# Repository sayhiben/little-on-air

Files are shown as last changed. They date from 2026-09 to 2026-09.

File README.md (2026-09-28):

# Little On Air

A wireless status sign for your desk, door or studio. Choose a mood on the desk
controller, press the knob, and the sign shows people whether you're available,
on air, waiting or asking for a little help.

The controller and sign communicate directly over Bluetooth. No phone app,
Wi-Fi network or account is needed. You choose the status yourself; Little On
Air does not automatically detect recording, calls or streaming software.

**This is the product manual.** For assembly, parts, source code, builds and
feature development, see the [developer guide](CONTRIBUTING.md).

## In this guide

- [Meet your devices](#meet-your-devices)
- [Quick start](#quick-start)
- [Choose a mood](#choose-a-mood)
- [Read the controller screen](#read-the-controller-screen)
- [Controls and settings](#controls-and-settings)
- [Connect or change a sign](#connect-or-change-a-sign)
- [Power and charging](#power-and-charging)
- [Understand the indicator lights](#understand-the-indicator-lights)
- [Troubleshooting](#troubleshooting)
- [Versions and further help](#versions-and-further-help)

## Meet your devices

Controller and sign diagrams showing the knob, OLED, mood light, sign face, reset button and power indicator.

The **desk controller** has a rotary knob that also presses like a button, a
small OLED screen and a round mood light beside the screen. Its rear USB-C port
provides power from your computer or a USB supply. It has no battery.

The **sign** has a lit front panel, a small rectangular **RESET** button and a
separate round red power indicator. The top has the **POWER** switch, a smaller
**RUN / PROGRAM** mode switch, a charger USB port and a separate XIAO USB port
for servicing. Two light guides at the rear expose the charger indicators.

The drawings are control maps, not assembly or dimensioned drawings. Locate the
two different sign USB ports before connecting a cable; they have different jobs.

## Quick start

For an assembled, commissioned pair:

1. With the sign's **POWER OFF** and both of its USB ports unplugged, select
   **RUN**. Turn **POWER ON**. Leave both sign USB ports unplugged during use.
2. Plug the controller into USB power. Keep the devices nearby for setup.
3. If already paired, the controller checks the sign and displays its mood.
   If it says **MEET YOUR SIGN**, tap the sign's **RESET** once, then press the
   controller knob to connect during the 60-second pairing window.
4. Turn the knob to choose a mood. **Press once to send it.** Wait for
   **YOUR SIGN** and the selected mood to appear as confirmed.

Turning alone is a preview: it does not change either device's mood light.
The sign remembers its last accepted mood through a normal power cycle.

## Choose a mood

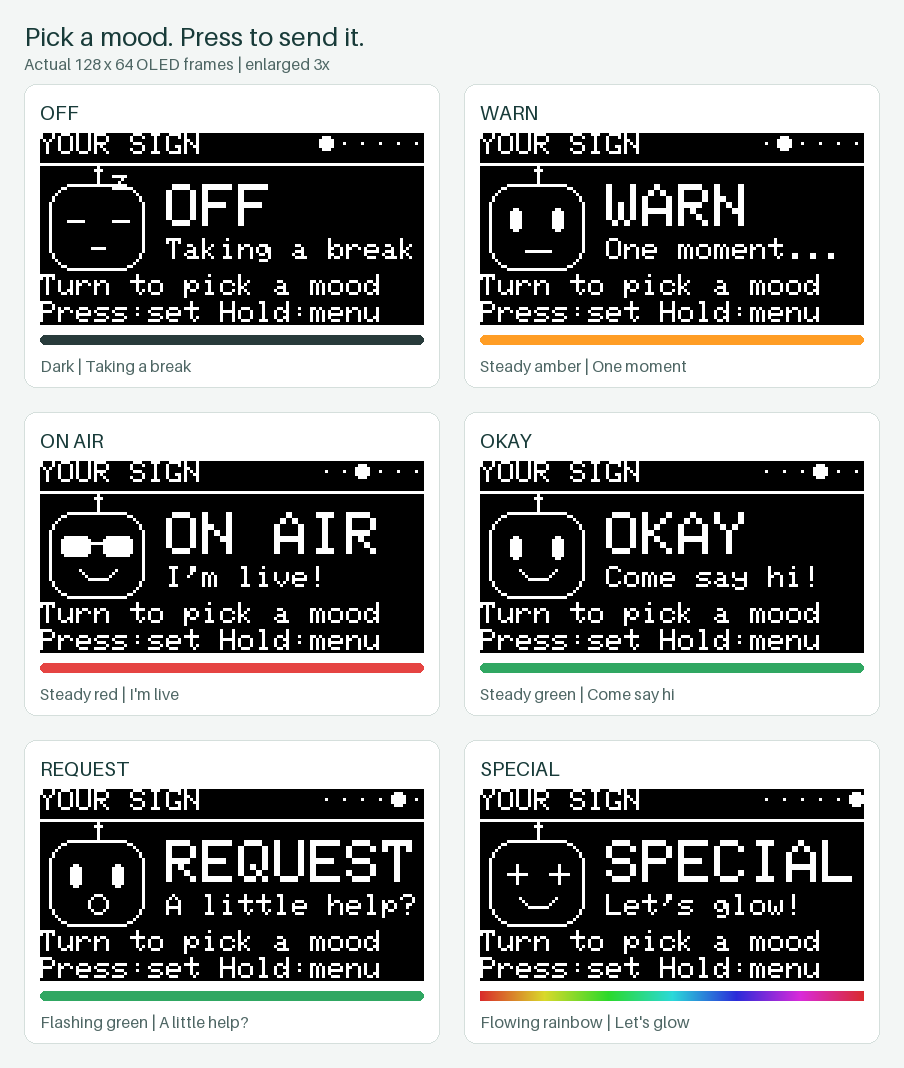
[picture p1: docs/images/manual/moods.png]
Six real controller screens: Off, Warn, On Air, Okay, Request and Special.


These screenshots use the controller's actual display code and font, enlarged
without smoothing. The color strips are a guide to the lights, not part of the
monochrome OLED. Colors on a monitor are approximate.

| Mood | Sign and controller mood light | Suggested meaning |
| --- | --- | --- |
| **Off** | Dark | Taking a break; no illuminated status |
| **Warn** | Steady warm amber | One moment; please wait |
| **On Air** | Steady red | I'm live; please avoid interruptions |
| **Okay** | Steady green | Come say hi; available |
| **Request** | Green flashing on for 0.6 seconds, off for 0.6 seconds | A little help, please |
| **Special** | A slow, flowing rainbow, repeating about every 20 seconds | Let's glow; a decorative or special status |

Agree on the meanings with the people around you. The colors are signals you
choose, not measurements of your activity.

Turning forward cycles **Off → Warn → On Air → Okay → Request → Special → Off**.
Turn the other way to go backward. Pressing a mood that is already confirmed
shows **Already set!** and leaves the sign alone.

The sign's four corner lights blend across its face. In Special, different
corners show different parts of the rainbow. The controller has one mood light;
its animation and the sign's animation do not have to move in exact step.

**Off turns off the mood lights, not the sign's power.** Its separate red power
indicator remains on while the sign is powered and paired.

## Read the controller screen

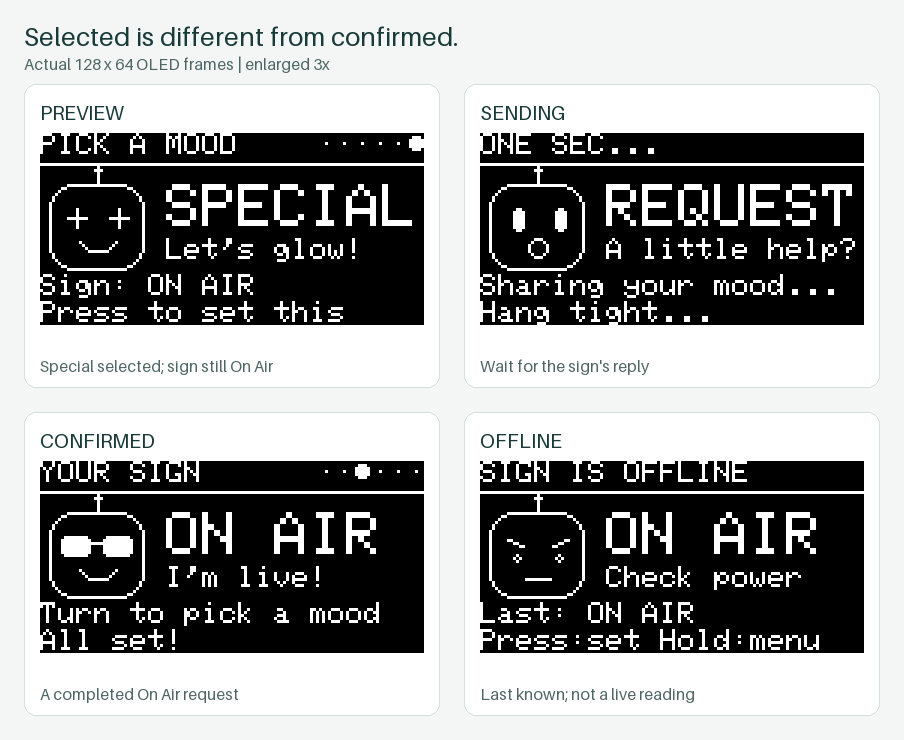
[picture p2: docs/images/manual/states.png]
Real controller screens showing a preview, a command in progress, confirmation and an offline last-known value.


The large word is the mood currently selected on the knob. Read the heading
and the smaller line to tell whether that mood has reached the sign. The six
dots at the top show the selected mood's position in the cycle; they are not
a battery gauge or signal-strength meter.

| Screen or message | What it means | What to do |
| --- | --- | --- |
| **YOUR SIGN** | The displayed mood has been checked with the sign | Turn to choose another mood, or leave it as it is |
| **PICK A MOOD** with **Sign: ON AIR**, for example | You are previewing a different mood; the smaller line is the confirmed sign state | Press to apply the large selection |
| **ONE SEC…**, **Sharing your mood…**, **Waiting for the sign** | A foreground operation is in progress | Wait for confirmation or an error |
| **All set!** | The sign confirmed the requested mood | No further action needed |
| **SIGN IS OFFLINE** with **Last: …** | The stored value has not been verified in the current connection state | Check sign power and distance; use **Check my sign** |
| **Last: not checked** | There is no confirmed saved value to show | Connect and check the sign |
| **MEET YOUR SIGN** | The controller has no paired sign | Open the sign's pairing window and press the knob |

A **Last:** value is a memory, not a live reading. When the controller cannot
verify the sign, its own mood light is dim white. It returns to the mood color
after a successful check. White is not a seventh mood.

The controller checks the sign on startup and periodically while on the home
screen. These background checks do not change the mood, restart the animations
or wake the OLED. After a connection failure it makes a few read-only retries.
If a send fails, it does not keep replaying that command later; check the screen
and press again when the sign is available.

## Controls and settings

### The knob

| Action | On the home screen | In settings |
| --- | --- | --- |
| **Turn** | Preview the next or previous mood | Move through choices |
| **Press and release** | Send the selected mood; connect if unpaired | Choose the highlighted item |
| **Hold for 1.2 seconds** | Open settings | Return to the home screen |

Holding and releasing does not also count as a click. The controller also
ignores a knob held down while it starts, so plugging it in with the knob
pressed does not send a mood or erase pairing.

### Settings menu

Hold the knob, turn to an item and press to select it.

| Item | What it does |
| --- | --- |
| **Back to my sign** | Return to the home screen |
| **Check my sign** | Read the sign's current mood without changing it |
| **Connect a sign** | Pair an unpaired controller with a sign in its pairing window; an already paired controller says **Already connected!** |
| **Brightness** | Adjust the sign frame, sign indicator, awake screen, dim screen and controller light; reset each to its default |
| **Light test** | Test the controller's small mood light; see below |
| **Forget this sign** | Ask for confirmation, then remove the pairing; see [changing or reconnecting a sign](#changing-or-reconnecting-a-sign) |

Settings and an unanswered Forget confirmation return home after 30 seconds
without input. You can also hold the knob to leave them.

### Brightness

Choose **Brightness**, then the light or screen mode you want to adjust. Press
**Level**, turn to change it in 5-point steps, and press again. Choose **Save**
to keep it. **Reset default** selects that item's original brightness; choose
**Save** to keep the reset. **Cancel**, holding the knob, or leaving the editor
idle discards an unsaved change.

Every level uses a **0–100% adjustment scale**: 0% is the lowest available
brightness, not off. The ranges are limited for each light. The default is 50%
for the three LED controls, 100% for **Screen awake**, and 0% for **Screen dim**.
These defaults reproduce the previous firmware's light levels. Awake and dim
are adjustable separately; dim stays below the awake range. Screen sleep still
turns the display off after two minutes.

The controller previews its own light and screen while editing, including the
idle contrast when editing **Screen dim**. Its light continues showing the
current mood, so choose a lit mood first if it is Off. The sign applies a change
when you save. Its mood and animation continue without restarting.

The sign must be reachable to read or save its brightness. Wait for
**Brightness saved**. **Save not confirmed** means the result is uncertain;
press to read the sign again before making another change. Unsaved or failed
requests are never sent automatically later. **Update sign firmware** means the
sign needs the matching brightness-capable firmware.

Each device saves its own brightness through power cycles and disconnects.
Changing or forgetting a pairing preserves these settings, so a replacement
controller reads the sign's own levels. Controller settings also work without a
paired sign.

### Light test

**Light test** affects only the controller's round light. It does not change the
sign or its saved mood. The screen says **LIGHT CHECK** and shows the test color
and counts of turns and clicks.

The test starts red. Turn or click to cycle through **Off, Red, Green, Blue,
White and Yellow**. Hold to finish, or let it exit after 60 seconds without
input. The controller then resumes its usual confirmed-mood or offline light.

### Screen sleep

The OLED dims after 30 seconds without activity and turns off after two minutes.
The first turn, click or hold while it is asleep **only wakes it**. Make the
gesture again to select, send or open settings. The mood light continues to work
while the screen sleeps.

If your computer removes USB power during sleep, the controller turns off.
The battery-powered sign keeps its saved mood. When USB power returns, the
controller reads the sign; startup does not advance or send a new mood.

## Connect or change a sign

### First connection

1. Power the sign in **RUN** on its battery, with both sign USB ports unplugged.
2. Tap the unpaired sign's **RESET** once. Its red indicator blinks quickly for
   the **60-second pairing window**.
3. Press the unpaired controller's knob, or choose **Connect a sign**. Keep the
   devices nearby and allow the search to finish; it can take several seconds.
4. Look for **YOUR SIGN** and a confirmed mood. The sign's red power light becomes
   steady after it is paired.

There is no PIN to type. Each controller/sign pairing is for one partner.
If the pairing window expires, tap RESET once to open it again on an unpaired
sign. Ordinary power cycles keep an existing pairing.

### Changing or reconnecting a sign

Keep the old sign powered and nearby. Hold the controller knob and choose
**Forget this sign**. The confirmation starts on **Keep my sign**; turn to
**Forget sign** and press to proceed. Hold to cancel instead.

With matching current firmware and a reachable sign, this unlinks both devices.
The sign restarts, clears its saved mood to Off and opens its pairing window.
When the controller says **Ready to connect!**, press to pair again, or open the
pairing window on the replacement sign you want to use. Only put the intended
sign into pairing mode nearby.

If the old sign cannot be reached, the controller still forgets its own pairing
and displays the recovery instructions below. The old sign retains its keys
until you reset its pairing locally.

### Five-reset recovery

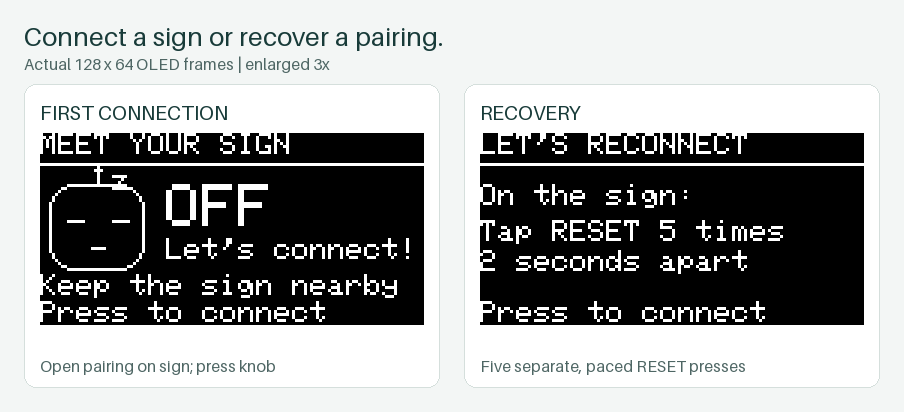
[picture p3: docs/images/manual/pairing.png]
Actual first-connection and recovery screens. The recovery screen says to tap the sign's RESET five times, two seconds apart.


Use this if a sign still remembers an old controller, online Forget could not
reach it, or the devices have mismatched pairing records.

1. If the controller still has an old pairing, use **Forget this sign** first.
2. With the sign powered in RUN, press and release its **RESET five times**, about
   **two seconds apart**. Let the application start between presses.
3. After the fifth reset, the sign forgets its pairing and saved mood, returns
   to Off and opens a 60-second pairing window.
4. Press the unpaired controller's knob to connect.

This is five separate presses, not a long hold. A gap of six seconds of normal
running clears an incomplete count; if you lose count, wait and start again.
A power cycle also clears an incomplete count. Avoid a rapid double tap: that
enters the firmware bootloader instead. If you accidentally do that, a normal
power cycle returns to the application when valid firmware is installed.

## Power and charging

**Before connecting either USB port on the sign: set POWER OFF and select
PROGRAM. Connect only one sign USB port at a time.** The sign does not have an
automatic USB/battery power selector. Do not charge it while using it in RUN.

Power mode guide: normal use is ON and RUN with no sign USB cable; charging is OFF and PROGRAM with charger USB only; servicing is OFF and PROGRAM with XIAO USB only.

| Activity | POWER | MODE | Sign USB connection |
| --- | --- | --- | --- |
| Normal use | **ON** | **RUN** | Neither port |
| Turn the sign off | **OFF** | RUN | Neither port |
| Charge the battery | **OFF** | **PROGRAM** | **Charger USB only** |
| Firmware service | **OFF** | **PROGRAM** | **XIAO USB only**; see the developer guide |

To charge:

1. Turn POWER OFF. With both USB cables removed, move MODE to PROGRAM.
2. Connect power to the **charger USB port**. Leave XIAO USB unplugged.
3. The rear light guides show the charger's indicators. Their meaning depends
   on the fitted charger board; use its verified labels. The OLED does not show
   battery percentage or a charging estimate.
4. After charging, unplug USB first. With POWER still OFF, select RUN, then turn
   POWER ON to use the sign.

Only change MODE with POWER OFF and both USB ports unplugged. PROGRAM provides
electrical isolation; selecting it does not itself start a firmware update.
POWER OFF disconnects the normal load but does not disconnect the battery from
the charging board.

The controller's USB port is separate from these restrictions: it normally stays
plugged in during use. Do not open a powered sign or charge a damaged battery;
have wiring, a loose connector or battery replacement checked using the
[assembly and commissioning guidance](CONTRIBUTING.md#hardware-and-bill-of-materials).

## Understand the indicator lights

There are three different kinds of light:

| Light | Appearance | Meaning |
| --- | --- | --- |
| Sign's large front panel | One of the six moods | The sign's saved, active mood |
| Controller's round light | Mood color or animation | The mood confirmed by the sign, not the knob preview |
| Controller's round light | Dim steady white | The sign's state is currently unverified |
| Sign's small front power indicator | Steady red | Powered and paired; stays red even when the mood is Off |
| Sign's small front power indicator | Fast red blink, about twice per second | Unpaired; pairing window is open |
| Sign's small front power indicator | Mostly red with a short dark gap every two seconds | Unpaired; pairing window has closed |
| Rear charger light guides | Charger-board indicators | Charging status, separate from Bluetooth and mood |

The little face on the OLED is decorative and sometimes blinks. Use the screen
heading and text to judge connection state.

## Troubleshooting

| Symptom | Try this |
| --- | --- |
| Turning the knob does not change the sign | Press to send the preview. If the screen was asleep, the first gesture only woke it. |
| Screen is dark | Press once to wake it. If it stays dark, check controller USB power and the cable. |
| **SIGN IS OFFLINE** or **Can't reach your sign** | Check sign battery/power and RUN mode, move closer, then use **Check my sign**. A Last value is not confirmation. |
| Controller light is white | It is waiting for a verified sign state. Check power and use **Check my sign**. |
| Controller is on but sign is dark | Off is a valid mood. Check the sign's separate red indicator, then send Okay or On Air. If the indicator is also off, check power and charge the battery using the sequence above. |
| The sign stays red after choosing Off | The small power indicator should stay red. The large front mood panel should be dark. |
| Pairing does not finish | Open the sign's 60-second window again and keep it nearby. If either device remembers a different partner, use Forget and the five-reset recovery steps. |
| **Already connected!** when choosing Connect | Connect does not replace a partner. Use **Forget this sign** before changing signs. |
| **One sec, please!** | Let the current operation finish before starting another. |
| **Press to try again** after a failed operation | Restore connectivity, then press again. A failed request is not silently sent later. |
| Mood animation resumes when the controller is unplugged | Expected: the sign runs independently and retains its mood. |
| Reset seems to enter an update mode | Avoid rapid double taps. Power-cycle normally, then space pairing-reset presses about two seconds apart. |
| **State save failed**, **Cache clear failed**, or repeated **Radio needs a restart** | Restart the controller and check again. If it recurs, record the exact message and firmware versions for service; do not repeatedly erase pairing as a substitute for diagnosis. |
| Front panel flickers, shows the wrong color or only some corners light | Check with another steady mood. If it persists, stop and have the pixel wiring and matching receiver firmware checked; Light test only tests the controller light. |

## Versions and further help

This manual describes the **ESP32-S3 controller firmware 0.5.0** with the current
matching four-pixel nRF52840 receiver firmware, **Igor measured v4 controller**
and **v2.15 sign case** with open-backed frame wire channels. This project
maintains this one device pair; install the current controller and receiver
firmware together when updating.

Manufacturing ZIPs preserve the firmware that shipped with their design snapshot;
that may be older than this manual. Use the [developer firmware guide](CONTRIBUTING.md#build-and-flash)
when updating a device, and follow the sign's USB isolation sequence above.

- [Developer guide](CONTRIBUTING.md): BOM, wiring, architecture, setup, builds,
  tests, diagnostics and making changes.
- [Current hardware](hardware/README.md): assembly guides and print files.
- [Brightness hardware checks](docs/BRIGHTNESS_BENCH.md) and
  [pairing/power observations](docs/PAIRING_POWER_UPDATE.md): what has actually
  been checked on the assembled devices.
- [Report a problem](https://github.com/sayhiben/little-on-air/issues): include
  the screen message, selected mood, power arrangement and installed versions.

## License

[MIT](LICENSE). Hardware source attribution is recorded with each design.

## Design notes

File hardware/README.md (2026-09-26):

# Hardware

| Design | Current source and guides | Ready-to-use release |
| --- | --- | --- |
| Receiver enclosure v2.15 | [Enclosure development](enclosure/README.md) | [Complete manufacturing release](../release/little-on-air-enclosure-v2.15/README.md) |
| Igor controller v4 | [Measured controller](controller/igor-measured-v4/README.md) | [Controller ZIP](../release/little-on-air-igor-controller-v4.zip) |

Earlier designs, exploratory scripts and superseded manufacturing output are
grouped in [archive/](archive/README.md). See the [workspace guide](../docs/WORKSPACE.md)
for local firmware images, build output and bench evidence.

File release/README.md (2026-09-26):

# Current project release

## Controller hardware prototype

The [measured Igor controller v4 ZIP](little-on-air-igor-controller-v4.zip)
uses Igor's actual desk orientation: broad flat base down, horizontal encoder,
upward-facing display and vertical back. A 9.5 mm base extension fits two
20 × 33.5 × 6.5 mm weights in one layer beneath a XIAO ESP32-S3 carrier.
The encoder and OLED mounts match supplied measurements; the front mini-strip
NeoPixel has a captured transparent PETG diffuser. The footprint is unchanged,
and the raised front nose contains no weights. Includes eight STLs, STEP CAD,
three Bambu projects, fit report, comparison views and assembly instructions.
Read the [controller guide](../hardware/controller/igor-measured-v4/README.md).

CAD and slicer checks pass; physical assembly and the ESP32-S3 firmware port
remain unvalidated/unimplemented. Controller v1–v3 are superseded.

## Receiver enclosure

The current manufacturing release is [Little ON AIR enclosure v2.15](little-on-air-enclosure-v2.15/README.md), the case retained by the user and restored as current on September 26, 2026. Frame 01 has open-backed perimeter wire channels; the channel roofs and access-window ceilings were removed after the v2.14 physical bridging failure. The original rear housing 05, electronics yoke 06 and other printed/laser-cut parts remain in this set.

- [Download the complete ZIP](little-on-air-enclosure-v2.15.zip)
- [Print only the replacement front frame](little-on-air-enclosure-v2.15/bambu-studio/on-air-v215-X1C-front-only.3mf)
- [Open the three-plate Bambu Studio project](little-on-air-enclosure-v2.15/bambu-studio/on-air-v215-X1C-all-plates.3mf)
- [Read the open-channel wiring guide](little-on-air-enclosure-v2.15/guides/FRONT-WIRING.md)
- [Read the complete build guide](little-on-air-enclosure-v2.15/guides/BUILD-AND-ASSEMBLY.md)
- [Review all parts and materials](little-on-air-enclosure-v2.15/BOM.csv)

The release includes production STLs, acrylic artwork, calibration SVGs, Fusion/STEP CAD, assembly and wiring guides, validation records and a firmware source snapshot. Optional laminate parts are kept separate from the selected printed backing. Older development iterations are in [the hardware archive](../hardware/archive/README.md); see the [revision history](../hardware/enclosure/REVISION-HISTORY.md).

The [v2.16 release](little-on-air-enclosure-v2.16/README.md) is preserved as an archived alternative. Both releases, their ZIPs and checksums retain their published bytes. The current case is v2.15; its bundled firmware snapshot is independently versioned v0.1.2 and drives onboard RGB only. Use the [developer guide](../CONTRIBUTING.md#four-pixel-nrf52840-receiver) for current receiver firmware. This case selection adds no new physical validation result; the original validation records and commissioning checks remain in the package.

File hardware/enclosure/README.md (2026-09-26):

# Little On Air enclosure

## Current complete release

Use [enclosure v2.15](../../release/little-on-air-enclosure-v2.15/README.md), the receiver case retained by the user and restored as current on September 26, 2026. It has the open-backed wire channels in frame 01 and the original rear housing 05 and electronics yoke 06.

- [Complete release ZIP](../../release/little-on-air-enclosure-v2.15.zip)
- [Bambu Studio: replacement front frame](../../release/little-on-air-enclosure-v2.15/bambu-studio/on-air-v215-X1C-front-only.3mf)
- [Bambu Studio: all plates](../../release/little-on-air-enclosure-v2.15/bambu-studio/on-air-v215-X1C-all-plates.3mf)
- [Open-channel wiring and mounting](../../release/little-on-air-enclosure-v2.15/guides/FRONT-WIRING.md)
- [Build and assembly](../../release/little-on-air-enclosure-v2.15/guides/BUILD-AND-ASSEMBLY.md)
- [Parts and hardware](../../release/little-on-air-enclosure-v2.15/BOM.csv)

The current set uses black PLA+ structure, black/white PLA+ backing and three clear PETG indicator guides. v2.15 removes the failed wire-channel roofs from the widened 129 × 69 mm frame. Wires lay into the channels from the rear and use small hot-glue anchors for retention. The other parts, acrylic, optical floors and nine M3x8 joints retain their earlier geometry. The all-plates project preserves the approved three-plate layout; the front-only project is for upgrading a v2.14 frame.

The existing CAD, print projects, validation records and published checksums are unchanged. This selection records which case the user kept; it does not add a new physical fit or electrical validation result. The v2.16 rearward-wiring housing/yoke revision is preserved in [the archive](../archive/enclosure/v216/README.md).

The package preserves the earlier firmware 0.1.2 snapshot, which uses onboard RGB only. Follow the [developer guide](../../CONTRIBUTING.md#four-pixel-nrf52840-receiver) for the current four-pixel firmware; release-bundled firmware notes describe the historical snapshot.

## Development files

[v215/](v215/README.md) contains the current channel-opening builder, mesh and
print audits, wiring diagram and release tooling. `output/v215/` contains its
preserved CAD, frame mesh, print projects and validation evidence. Packaging
starts from the preserved v2.14 release and replaces frame 01 and its guides.

Earlier versions, one-time patch/probe scripts, old root-level builders,
references and superseded outputs now live in
[the hardware archive](../archive/README.md). Current tools explicitly import
several archived geometry and print-audit helpers; retain that dependency tree.
[REVISION-HISTORY.md](REVISION-HISTORY.md) links to the archived manufacturing
iterations. Published release bundles keep their existing paths and checksums.

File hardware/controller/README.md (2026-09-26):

# Controller hardware

Use [Igor measured v4](igor-measured-v4/README.md) for the current controller.
Its directory contains the source, measured component references, assembly
instructions, validation reports and Bambu Studio projects.

Versions 1–3 are preserved under [the controller archive](../archive/README.md#controller).
The [ESP32-S3 firmware](../../apps/controller-esp32s3/README.md) is maintained
separately from the mechanical design.

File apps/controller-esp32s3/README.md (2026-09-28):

# ESP32-S3 desk controller

USB-powered Seeed XIAO ESP32-S3 controller for the existing Little On Air BLE
receiver. This application uses Arduino-ESP32 with pinned PlatformIO packages.
The nRF52840 controller in `../controller` and receiver in `../receiver` remain
separate Zephyr applications; their UF2 files cannot be flashed to this board.

## Wiring

| Part | XIAO label | ESP32 GPIO |
| --- | --- | --- |
| SSD1306 128×64 OLED SDA | D4 | 5 |
| OLED SCL | D5 | 6 |
| Encoder CLK | D0 | 1 |
| Encoder DT | D1 | 2 |
| Encoder SW | D3 | 4 |
| One RGB NeoPixel DIN, through 330 Ω | D7 | 44 |

OLED and encoder VCC use 3V3. NeoPixel power uses 5V. All grounds are common.
Pixel DOUT is unused. USB diagnostics use the native USB peripheral, leaving
GPIO44 available for the pixel. OLED address 0x3C or 0x3D is detected at boot.
The pixel uses GRB, 800 kHz and a default brightness limit of 24/255.

## Controls

- **Turn:** preview Off → Warn → On Air → Okay → Request → Special; turn backward
  to go the other way. Turning does not change the sign.
- **Press:** set the selected mood. When unpaired, start connecting to a sign.
- **Hold 1.2 seconds:** open the menu; hold again to return home.
- **Menu:** Back to my sign, Check my sign, Connect a sign, Brightness, Light test, Forget this sign.
- **Brightness:** separate sign frame/indicator, awake/dim OLED and controller-light
  controls. Press Level, turn, press again and Save. Reset default prepares a reset
  for that value; Save commits it. Local edits preview immediately; sign edits apply
  on Save with exact transaction/levels read-back. Cancel/hold/timeout discards drafts.
  Each device retains its own levels independently of pairing. See the
  [brightness guide](../../docs/BRIGHTNESS.md) for ranges, protocol and validation.
- **Forget this sign:** defaults to Keep my sign. Turn to Forget sign and press to erase.
  Keep the sign powered: firmware 0.4.0 clears both devices' pairing, then a
  press connects them again. If the sign cannot be reached, the OLED shows
  the five-reset recovery instructions below.
  Holding the knob during boot never clears a bond or sends a command.

The OLED buddy has a different expression for each mood: sleepy when Off,
sunglasses when On Air, and starry eyes for Special. Large text shows the
selection; **PICK A MOOD** and **Sign: ...** distinguish a preview from the
confirmed state. **SIGN IS OFFLINE** and **Last: ...** identify cached state that
has not been verified. A write response alone is not treated as confirmation.

The controller pixel stays at the confirmed state while you browse: red = On Air,
warm amber = Warn, steady green = Okay, flashing green = Request, a slowly changing
rainbow = Special, dark = Off. Unknown/offline uses a steady dim white marker.
Request flashes 600 ms on / 600 ms off. Special flows through a 20-second cycle;
the receiver's four corner pixels form a diagonal rainbow wash. Both devices
animate locally, so their phases need not match exactly.

The display dims after 30 seconds and turns off after two minutes without user
interaction. The first gesture wakes it without changing or sending a state.
The pixel continues displaying the status. Menus cancel after 30 seconds idle;
Hardware Test exits after 60 seconds idle. Background state reads do not reset
the display's inactivity timer.

**Hardware Test** labels the OLED with the commanded pixel color and input
counters. Turn or press to cycle Off / Red / Green / Blue / White / Yellow.
Hold to exit. This mode neither sends nor persists a receiver state.

## Build, flash, and inspect

From the repository root, with Python 3.10+:

```sh
python -m pip install platformio==6.1.18
python -m platformio run -d apps/controller-esp32s3
python -m platformio device list
python -m platformio run -d apps/controller-esp32s3 -t upload --upload-port COM4
python tools/controller_serial.py --port COM4 --command status
python tools/controller_serial.py --port COM4 --command "test red" --duration 30
python tools/controller_serial.py --port COM4 --command exit
```

Replace COM4 with the detected port. On this Windows workspace the Python
environment is `.venv\Scripts\python.exe`. The uploader writes and verifies the
bootloader, partition table and app; it does not erase the NVS bond/state area.
If USB upload cannot connect, hold BOOT, tap RESET, release BOOT and retry.

USB commands: `help`, `status`, `test`, `test red` (also off/green/blue/white/yellow),
`next`, `exit`, `menu`, `sync`, `pair`, `send off|warn|on-air|okay|request|special`.
`send` uses the same real BLE transaction and exact acknowledgment checks as
pressing the encoder; it rejects unpaired/busy requests and unknown states.
`pair` explicitly opens the same timed
pairing operation as the menu. Input events and BLE results are logged at 115200.
Firmware 0.2.3 adds `pixel 1 red` (indices 1–4 and the six hardware-test colors)
and `pixel end` for receivers with the individual-pixel characteristic. These
temporary front-light tests use encrypted write/read-back without changing the
saved receiver status; they end after two minutes or a regular status command.
Opening the provided monitor leaves reset control lines deasserted.
No USB command erases bonds or pretends to acknowledge a receiver command.

The full build outputs are under `.pio/build/xiao_esp32s3/`. `firmware.bin` alone
is the application at offset 0x10000; use PlatformIO to flash all required images.
Change `LOA_ENCODER_DIRECTION` to -1 if the physical encoder direction is reversed.

## Pairing with the nRF52840 receiver

1. Power the receiver. If it still has an old controller bond, clear that bond
   first using the five-reset procedure below.
2. On an unpaired receiver, one reset opens its 60-second pairing window.
3. On an unpaired controller, press to connect; otherwise hold the encoder,
   select **Connect a sign**, and press.
4. The controller scans for up to 45 seconds inside a 60-second operation budget,
   establishes an encrypted Secure Connections bond, and reads the receiver state.
5. Confirm the OLED shows **YOUR SIGN**, then turn and press to set a mood.

Only the stored bonded identity is contacted during ordinary sync/send. A missing
peer key reports a failure instead of silently forgetting/replacing the bond.
To replace the receiver, explicitly Forget this sign on the controller and clear the
receiver's old bond before pairing again.

### Reconnecting after Forget this sign

With controller **0.4.0** and the matching receiver update, keep the sign on,
choose **Forget this sign → Forget sign**, wait for **Ready to connect**, then
press the knob. The sign erases its bond and saved mood, restarts in Off, and
opens a 60-second pairing window. Its small onboard LED flashes red while
pairing and stays red after connecting. The front pixels show only the mood.

If the sign was off, out of range, or running older firmware, Forget still clears
the controller's pairing and displays **LET'S RECONNECT**. On the updated sign:

1. Leave the sign powered and press its rectangular RESET button **five times,
   about two seconds apart**. Let the application LED return between presses.
   Do not double-click: rapid double-reset enters the firmware bootloader.
2. After the fifth press, the sign clears its pairing and mood and flashes red.
3. Press the controller knob to connect within 60 seconds. If that window has
   expired, tap the sign's RESET once and press the knob again.

Six seconds of uninterrupted application runtime cancels an incomplete reset
sequence; power cycling also cancels it. Holding RESET does not run a timed
gesture because it holds the processor in reset. Ordinary power cycling and
application-only firmware updates preserve the bond.

If the controller still holds an old bond after physically resetting the sign,
choose **Forget this sign** there before pressing to connect. Recovery needs no
computer or special firmware. See [the pairing/power update](../../docs/PAIRING_POWER_UPDATE.md)
for the recorded hardware validation. Use the
[current build and service guide](../../CONTRIBUTING.md#build-and-flash) for
this device pair; earlier firmware versions are not maintained.

## Current behavior

The shared C protocol/status implementations are built directly from the root
`src/` directory. UUIDs and the six-byte version-1 payload are unchanged. The
receiver remains the authority: subscribe to indications, write with response,
then require an exact transaction-ID **and** status match. A lost indication can
be recovered by an exact matching read. Failure marks the cached state unverified
and schedules read-only reconciliation with 1/2/4-second backoff; it never replays
the user's command. After three failed retries, manual Sync/press is required.
Successful operation resumes a read once per minute.
These background checks do not show connection messages, wake the OLED, restart
animations, or flash the bonded receiver's lights. A press during a background
check queues that selection until the read succeeds; failures never replay it.

Firmware `esp32s3-0.3.0` appends Request (wire value 4) and Special (5), preserving
values 0–3. Update the receiver before selecting either new mood. Old firmware
rejects the new values. Return to Off before rolling either device back.

BLE runs on a worker task, with an eight-second ordinary-operation budget; the
UI stops scans/connections at the deadline while continuing to read controls.
Connections close after each transaction to preserve receiver battery life.
Firmware `esp32s3-0.2.2` retries one BLE connection-establishment (`0x3e`)
failure before any command is sent, within the same eight-second deadline.
NimBLE persists bonds; Preferences stores only acknowledged/read-back state.
The pinned NimBLE 2.5.1 host is compiled through `nimble_guard.py`, which disables
its automatic missing-key pairing branch before GAP notification. The GAP
listener then translates that error to authentication failure. Normal operations
require a saved encryption key and make one encryption attempt. The storage
callback replaces only the same peer's obsolete private-address mapping when
that cache fills; it never evicts pairing keys to make room. Explicit Forget
clears residual key records as well as the listed bond.
Legacy BLE pairing is compiled out. Just Works has no passkey MITM protection,
as in the original receiver firmware.

## Tests

Host tests use CMake, a C/C++ compiler, and CTest (Linux/macOS or WSL):

```sh
cmake -S tests/host -B build/desk-tests
cmake --build build/desk-tests
ctest --test-dir build/desk-tests --output-on-failure
```

They cover contact bounce/reversal/invalid encoder transitions, button debounce,
boot-held suppression, hold/release behavior, clock wrap, shared wire encoding,
malformed packets, exact ACK matching, cached-state trust, and preview preservation.
They also cover all six wire values, Request boundaries, Special's period and
bounded brightness, and background checks while the OLED is asleep. Reset tests
run the actual settings-backed counter and durable remote-reset request with
simulated pin/power/software resets, flash failures, and timeout work. Output
tests check that all six moods and individual pixel tests leave the onboard
power LED independent, with separate brightness limits. A thousand simulated
private-address rotations exercise the real storage callback without deleting
keys; the pinned-host patch refuses unrecognized source changes. After a
PlatformIO build, `python tools/render_buddy_ui.py` (g++ and Pillow required)
renders the actual Adafruit GFX home-screen code and checks text bounds.

See [the six-mood update](../../docs/BUDDY_UPDATE.md) for the receiver build,
blink diagnosis, and validation status.

See [the initial bench results](../../docs/ESP32S3_BENCH.md) for controller hardware
observations and [the pairing/power update](../../docs/PAIRING_POWER_UPDATE.md) for current
paired hardware checks.

Reference: [Seeed pin multiplexing](https://wiki.seeedstudio.com/xiao_esp32s3_pin_multiplexing/),
[PlatformIO XIAO ESP32-S3 target](https://docs.platformio.org/en/latest/boards/espressif32/seeed_xiao_esp32s3.html),
[NimBLE-Arduino](https://github.com/h2zero/NimBLE-Arduino/tree/2.5.1).

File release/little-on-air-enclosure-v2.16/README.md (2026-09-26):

# Little ON AIR enclosure v2.16

This is the complete manufacturing package for the **129 × 69 mm front / 120 × 60 × 24 mm rear body** enclosure with the broad front bevels, corrected frame seams, two switches, flat PCB mounts, front reset button and captive indicator light guides. The unpressed reset button projects approximately 2.5 mm beyond the front.

**Upgrading an existing build:** print [05 rear housing and 06 electronics yoke](bambu-studio/on-air-v216-X1C-upgrade-parts.3mf), then follow [the illustrated rearward wiring guide](guides/FRONT-WIRING.md). The existing v2.15 front frame, all other printed parts and the acrylic are unchanged. Open clearances in the housing and reinforced yoke let the LED leads turn rearward behind the optical mounts instead of around the outside corners. Lay the upper wires before clamping the yoke. No new parts or electrical components are needed.

## Start here

1. Check the [parts and hardware list](BOM.csv).
2. Open the [single Bambu Studio project](bambu-studio/on-air-v216-X1C-all-plates.3mf) **as a project**, keeping its settings. It contains all ten production prints on three plates. [Printing guide](guides/PRINTING.md).
3. Cut and rear-engrave the acrylic using the [production SVG](laser/02-acrylic-REAR-engrave-and-cut.svg) and [laser guide](guides/LASER.md). The artwork is already mirrored; do not mirror again.
4. Follow the [complete build guide](guides/BUILD-AND-ASSEMBLY.md) and [two-switch wiring guide](guides/WIRING.md). The [capacitor and resistor walkthrough](guides/CAPACITOR-AND-RESISTOR.md) shows their purpose, exact lead connections and soldering steps. Record the physical checks in [COMMISSIONING.csv](guides/COMMISSIONING.csv).

**Firmware status:** the included firmware source snapshot is version 0.1.2 and drives the onboard RGB LEDs. It does not yet drive the four external NeoPixels. This hardware revision preserves that earlier snapshot; it does not publish or assess newer firmware work in the development repository. See [firmware status](guides/FIRMWARE-STATUS.md).

## Print set

| Plate | Parts | Material |
| --- | --- | --- |
| 1 | 01 frame, 05 housing, 04 optical retainer, 06 electronics yoke, 07 reset button, 11 rear guide keeper | Black PLA+ |
| 2 | 03 display backing, black base and white raised letters | Black and white PLA+ |
| 3 | 08 front indicator guide and **two** identical 09 charger guides | Transparent PETG |

The project keeps the approved three-plate positions from v2.15. Only the housing and yoke meshes change. There is one keeper; insert painting and the material profiles are preserved. Project filament numbers are **1 black PLA+, 2 white PLA+, 3 transparent PETG**; map them to your loaded spools. First-layer inspection remains disabled. Estimated total is about **6 h 37 min / 75.81 g**.

There are nine unique production STL files and ten printed pieces. Part 02 is laser-cut acrylic. Part 10 in the CAD is the second instance of STL 09; there is no missing STL. The printed display backing sits behind the acrylic with an air gap; its letters do not insert into engraved recesses.

## Folder guide

| Folder / file | Contents |
| --- | --- |
| `stl/` | Latest production meshes, millimetres, already oriented for printing |
| `bambu-studio/` | Complete three-plate project plus a housing-and-yoke upgrade project; both editable and sliced |
| `laser/` | Production acrylic SVG and clearly disabled LightBurn review project |
| `laser/calibration/` | Thickness-fit strip, kerf coupon and engraving samples |
| `cad/` | Complete current Fusion F3D and STEP assembly; hardware/reference bodies are not extra print parts |
| `guides/` | Consolidated printing, laser, wiring, assembly, firmware and commissioning instructions |
| `reference/` | Wire paths, length allowances, fastener layout and assembly images |
| `alternatives/laminate/` | Optional laminate artwork and its two spacer rings; omit with the selected printed backing |
| `firmware/` | Preserved firmware v0.1.2 source snapshot; no unverified local build binaries |
| `validation/` | Current mesh/print/optics checks and the existing native CAD validation records |
| `PARTS.csv` | Exact quantities, file paths, materials and revision provenance |
| `MANIFEST.json`, `SHA256SUMS.txt` | File inventory, source provenance and integrity checks |

The main case, yoke, optical retainer and guide keeper use **nine M3×8 button-head screws and nine standard M3 nuts total**. No older long closure screws, printed DPDT plunger or alternate-size guide sets are required.

The manufacture package has been checked digitally; actual spool behavior, acrylic thickness/kerf, electrical operation and optical brightness still require the build checks. No printer, laser or firmware job was started while packaging this release.

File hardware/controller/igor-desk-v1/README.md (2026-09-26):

# Little On Air — Igor desk controller v1

**Superseded by [revision 3](../igor-flat-base-v3/README.md):** this revision used an incorrect desk orientation. Use revision 3 for the flat base, horizontal encoder and front NeoPixel.

**Superseded:** use the [minimal Igor revision 2](../igor-minimal-v2/README.md), which preserves the original shape and adds only a small base extension, XIAO holder and top LED spot.

A **USB-powered XIAO ESP32-S3 controller** with an OLED, a rotary push encoder,
one WS2812B RGB LED, and a weighted case. This is a direct modification of
[Project IGOR by UrbanCircles / Peter](https://www.printables.com/model/1019283-project-igor-open-source-offline-loyal-cheerful-fo),
using the creator's STEP geometry from [UrbanCircles/igor](https://github.com/UrbanCircles/igor).

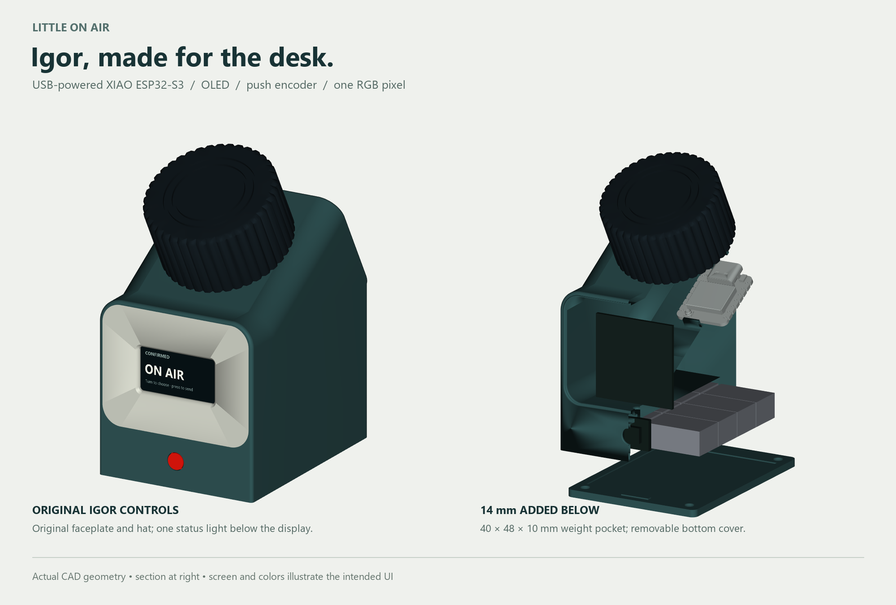
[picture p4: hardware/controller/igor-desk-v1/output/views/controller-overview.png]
Controller and section


## What changed

- **Computer USB-C supplies all power.** Use the regular XIAO ESP32-S3, without
  the Sense expansion board. No controller battery or external charger.
- Igor's **original OLED faceplate and encoder hat are retained at 100% size**.
  The assembled hat has a nominal 0.6 mm clearance above the shell.
- The original sloping underside is extended downward to a **flat desk base**.
  It adds **14 mm below the original front floor** and fills the space beneath
  the original rear slope. The upper silhouette and encoder mount remain Igor's.
- A **40 × 48 × 10 mm** underside compartment accepts adhesive wheel weights.
  The example arrangement is sixteen 5 g segments, **80 g total**, in two layers.
  Each segment must be **at most 19 × 11.5 × 4 mm, including adhesive**.
- A separate front slot holds a **10 × 10 × 1.6 mm single-pixel PCB**, behind a
  captive diffuser. The removable bottom cover retains the pixel PCB and weights.
- The D1 mini ridge is removed. A new XIAO pedestal, forward stop and enlarged
  rear USB opening fit the **actual Seeed XIAO ESP32-S3 CAD model**. Thin mounting
  tape holds the board down; the stop takes the forward insertion load.

Overall assembled envelope, excluding cable and rubber feet: approximately
**49 × 67.3 × 90.2 mm** (width × depth × height, including the hat).
Fit four approximately Ø8 × 1.2 mm rubber feet to the bottom cover for grip.

## Files to use

| File / folder | Purpose |
| --- | --- |
| [output/stl](output/stl) | Five individual parts, already oriented for printing, in millimetres |
| [output/bambu-studio](output/bambu-studio) | Three Bambu X1C / 0.4 mm projects, separated by material/color |
| [Complete STEP assembly](output/cad/igor-desk-v1.step) | Editable solid assembly; individual STEP parts are alongside it |
| [BOM.csv](BOM.csv) | Electronics, fasteners, weights and consumables |
| [ASSEMBLY.md](ASSEMBLY.md) | Printing, component fit, wiring routes and assembly |
| [WIRING.md](WIRING.md) | ESP32-S3 pin assignment and electrical connections |
| [FIRMWARE.md](FIRMWARE.md) | Controller behavior and required firmware migration |
| [output/validation](output/validation) | Native fit, manifold meshes and actual slicer results |

Print **one of each**: shell, faceplate, hat, ballast cover, diffuser. The source
Igor 3MF also contains decorative hat inlay rings; these are not needed for this
five-part build. Do not print the files in `assembly-meshes` as a print plate:
they retain assembly coordinates and include non-printable reference hardware.

## Verification and current status

**Hardware design and fabrication files are complete for a first prototype.**
All five meshes are watertight, consistently wound, connected solids. Native
solid checks find no interference between printed parts, the XIAO board model,
the declared USB plug envelope, the pixel envelope or the example weights. The
XIAO insertion path and the uninterrupted roof over the weight pocket are checked.
All three projects were actually sliced in Bambu Studio without warnings.

The original OLED and KY-040 mounts still require a fit check against the
particular modules purchased. Wiring, radio range, optical diffusion, encoder
force, insert fit and desk stability require a physical prototype. No physical
print, electrical test or hardware flash has been performed.

**The repository's existing controller firmware still targets the nRF52840.**
This hardware iteration does not make that UF2 compatible with the ESP32-S3.
The screen shown above illustrates the intended UI. See [FIRMWARE.md](FIRMWARE.md).
The receiver and its v2.13 enclosure remain the existing design.

## Rebuild

Use Python 3.12, `requirements.txt`, and the committed original STEP. From this
directory:

```sh
python -m pip install -r requirements.txt
python run_cad.py build
python run_cad.py validate_fit
python prepare_prints.py
python render_views.py
```

`prepare_prints.py` uses the installed Windows Bambu Studio executable and the
saved project profiles. It slices locally and never sends a print to a printer.
The CAD worker handles an observed Windows native-library teardown fault by
exiting after successful export/check completion; any assertion or exception
still fails the job. The renderer uses the exported CAD meshes, not AI imagery.

## Attribution

Upstream commit: `7543085fe11f102f121f08aabd8f6c25c38bdf60`.
The original files and UrbanCircles' MIT license are preserved in `upstream`.
See [SOURCES.md](SOURCES.md) for exact origins and the Seeed reference model.
The modifications and build scripts use this repository's MIT license; the
third-party files retain their original notices.

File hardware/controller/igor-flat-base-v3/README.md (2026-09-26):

# Project IGOR controller — corrected flat-base revision 3

**Superseded by [measured revision 4](../igor-measured-v4/README.md)**, which
fits the supplied weights, encoder, OLED and mini-strip LED with a diffuser.

The **large flat base sits on the desk**, the **encoder is horizontal**, the
**display faces upward at 60° to the desk**, and the **back is vertical**.
This revision starts from the original author-supplied STEP in that orientation.
It supersedes revisions 1 and 2, which misinterpreted the bottom.

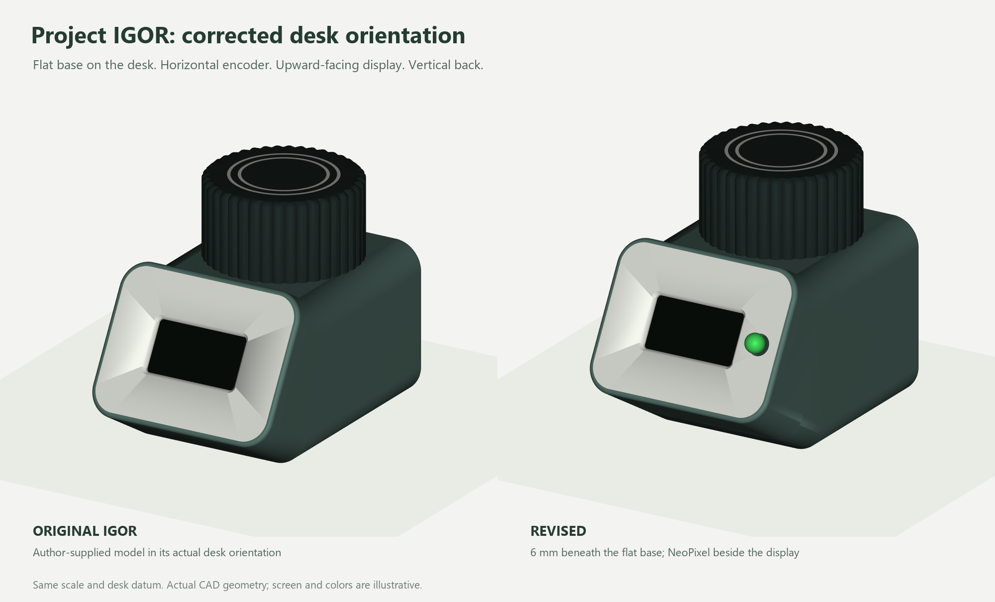
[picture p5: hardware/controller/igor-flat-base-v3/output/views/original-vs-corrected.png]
Original and revised in their correct desk orientation


## Minimal alterations

- **6 mm beneath the actual flat base.** One internal **36 × 20 mm** well holds
  three adhesive 5 g segments, each at most **19 × 11.5 × 4 mm including tape**.
  The raised front nose has no weights. The original rounded front underside
  continues smoothly into the added depth.
- **XIAO ESP32-S3 holder.** A shallow pocket and small mounting pad replace the
  D1-mini holder. USB uses the original rear position with a small opening
  enlargement to **9.8 × 4.6 mm**.
- **NeoPixel on the front face.** A **5.4 mm round opening** beside the display
  and an internal shoulder accept a **5 mm through-hole NeoPixel**. The original
  display opening, OLED mounting arrangement and faceplate closure remain.

The original hat, inlays and encoder mount are unchanged. The top has no LED
opening. There are still three main printed parts and two optional original
inlays, with no additional cover or case fasteners.

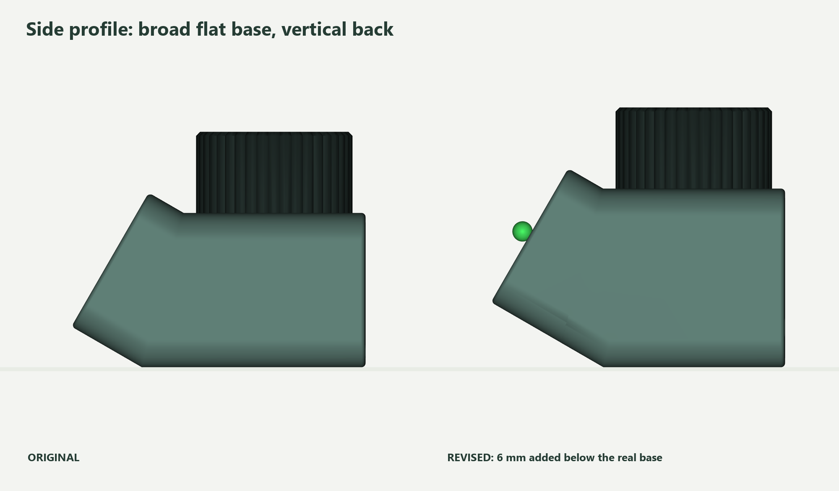
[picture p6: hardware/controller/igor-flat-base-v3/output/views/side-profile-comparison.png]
Corrected side profile


## Print and CAD files

- [Shell STL](output/stl/01-igor-flat-base-shell.stl)
- [Front LED faceplate STL](output/stl/02-igor-front-led-faceplate.stl)
- [Assembled STEP](output/cad/igor-flat-base-v3.step)
- [Bambu shell and original hat project](output/bambu-studio/igor-flat-base-v3-X1C-PLA-shell-hat.3mf)
- [Bambu faceplate and original inlays project](output/bambu-studio/igor-flat-base-v3-X1C-PLA-face-inlays.3mf)
- [Assembly guide](ASSEMBLY.md) · [BOM](BOM.csv) · [Wiring](WIRING.md)
- [Original source and attribution](SOURCES.md)

If you already have Igor, print the revised shell and LED faceplate and reuse
the original hat. STLs are oriented for printing. STEP uses the desk frame
with the original base at Z=0 and revised bottom at Z=-6. Comparison renders
place each assembly on the desk to show the real 6 mm height increase.

## Verification and limits

Native checks explicitly verify the horizontal base, vertical encoder axis and
vertical back. They confirm the raised nose is unchanged and edits are confined
to the base, XIAO holder/USB opening or small front LED mount. All five STLs are
closed, connected solids. Fit checks cover Seeed's XIAO model, sampled insertion
paths, the front pixel/lead envelope, OLED clearance, three weights and USB.

Both Bambu projects slice successfully without warnings. These are digital
checks: a physical print and soldered-module assembly still need a prototype
check. The pixel format has changed to fit beside the existing OLED; check its
dimensions and color order in [WIRING.md](WIRING.md).
See [validation records](output/validation/package-audit.json).

The controller remains computer-powered. This mechanical iteration does not
port the repository's nRF52840 firmware; see [firmware status](FIRMWARE.md).

## Rebuild

Install `requirements.txt`, then run from this directory:

```text
python run_cad.py build
python run_cad.py validate_fit
python prepare_prints.py
python render_views.py
python package.py
```

The slicer check requires Bambu Studio on Windows. `run_cad.py` reports errors
normally and avoids an OpenCascade interpreter teardown fault after completed
work. The exact source STEP and reproducible CAD operations are included.

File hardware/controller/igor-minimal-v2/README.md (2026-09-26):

# Project IGOR controller — minimal revision 2

**Superseded by [revision 3](../igor-flat-base-v3/README.md):** this revision used an incorrect desk orientation. Use revision 3 for the flat base, horizontal encoder and front NeoPixel.

This version starts again from **UrbanCircles’ original Project IGOR STEP**.
Only the shell changes. The original faceplate, hat, two decorative inlays,
screen opening, encoder position and front closure geometry are preserved exactly.

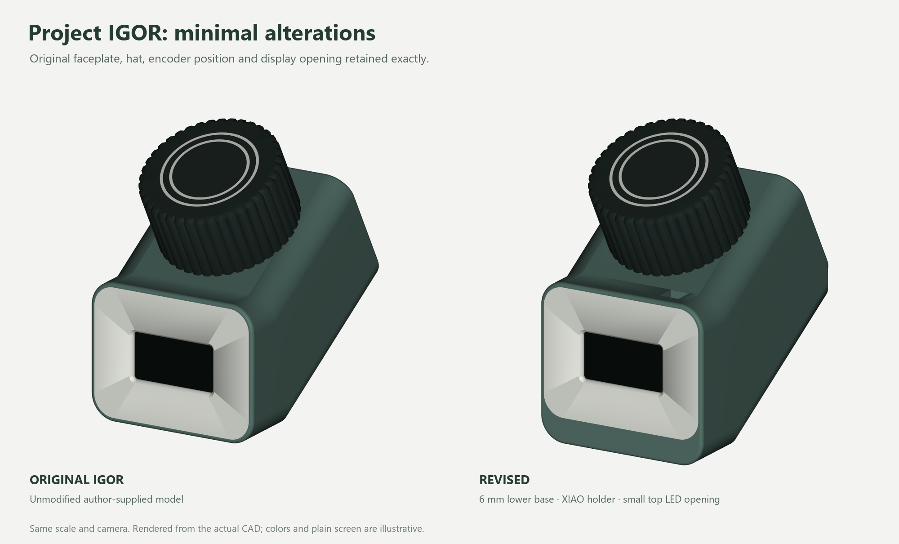
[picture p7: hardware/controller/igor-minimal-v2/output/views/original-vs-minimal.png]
Original and revised at the same scale


## The three alterations

| Change | Detail |
| --- | --- |
| Extend the base slightly | Original underside swept **6 mm downward**, following its existing rounded edges and 30° rear slope. Two internal recesses hold **five adhesive 5 g weight segments**, up to **19 × 11.5 × 4 mm each including tape**. |
| Replace the D1-mini holder | A shallow XIAO ESP32-S3 pocket and small mounting pad. Its USB-C socket stays centered at the original rear opening; that opening grows only to **9.8 × 4.6 mm**. |
| Add one LED spot | A **5.6 × 5.6 mm opening on the top**, ahead of the hat, with three small internal locating/glue lands for a **10 × 10 mm WS2812B carrier**. |

No additional case screws, bottom cover or diffuser. Use adhesive-backed weights
in a single layer. If you already have an Igor, reuse its faceplate and hat;
**only the new shell needs printing**.

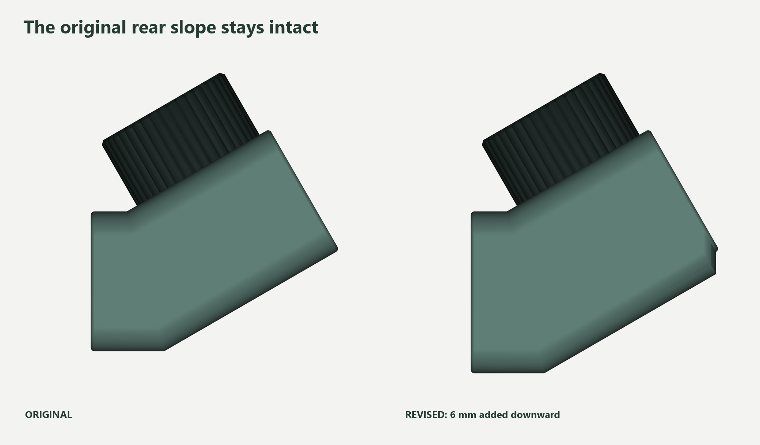
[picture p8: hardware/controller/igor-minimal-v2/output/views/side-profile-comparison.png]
The rear slope is preserved


## Files

- [Revised shell STL](output/stl/01-igor-shell-minimal.stl)
- [Complete assembled STEP](output/cad/igor-minimal-v2.step)
- [Bambu shell + original hat project](output/bambu-studio/igor-minimal-v2-X1C-PLA-shell-hat.3mf)
- [Bambu original faceplate + inlays project](output/bambu-studio/igor-minimal-v2-X1C-PLA-face-inlays.3mf)
- [Assembly and printing](ASSEMBLY.md) · [BOM](BOM.csv) · [Wiring](WIRING.md)
- [Original model provenance and attribution](SOURCES.md)

The five STLs are oriented for printing. The original inlays are optional trim
from the source design. The Bambu projects contain editable geometry/settings;
select your printer and filament and slice again before printing.

## Verification

Native solid comparisons confirm **zero change** to all four original separate
parts, and **zero shell changes outside the three edit regions**. All five STLs
are closed, valid, connected solids. The manufacturer’s XIAO model fits; sampled
socket-first insertion, LED fit and five nominal weights clear the shell.
Both Bambu projects slice successfully without warnings at 0.2 mm / four walls.

These are CAD and slicer checks. A physical print, soldered-module fit and cable
fit still need a first-prototype check. Exact purchased weight and LED carrier
dimensions matter. See [validation records](output/validation/package-audit.json).

This is a mechanical revision. The USB-powered ESP32-S3 electronics plan is
unchanged; the repository’s current controller firmware still targets nRF52840.
See [firmware migration status](FIRMWARE.md).

## Rebuild

Install the pinned dependencies in `requirements.txt`, then run from this directory:

```text
python run_cad.py build
python run_cad.py validate_fit
python prepare_prints.py
python render_views.py
python package.py
```

The print check uses an installed Bambu Studio on Windows. Model dimensions and
features are defined in `build.py`; the source STEP is bundled byte-for-byte.
`run_cad.py` reports build exceptions normally and avoids an OCP interpreter
teardown fault on Windows after the completed checks and file writes.

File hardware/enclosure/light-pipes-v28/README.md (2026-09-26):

# ON AIR v2.8 — transparent PETG indicator light guides

These are solid light pipes for the front XIAO RGB status LED and the two rear charger indicators. They retrofit the v2.8 enclosure. Use one long front guide and two identical short charger guides. The four acrylic edge-lighting pixels and the laser files are unchanged.

## Files and fit choices

Open `bambu-studio/on-air-v28-clear-PETG-light-pipes.3mf`. It contains nine parts: three complete sets, each with one long guide and two short guides. Keep each row together after removing it from the bed.

| Row / object name | Shaft diameter | Clearance in a nominal 3.2 mm bore |
| --- | --- | --- |
| Bed Y 112 / `2.95mm` | 2.95 mm | 0.25 mm diametral |
| Bed Y 126 / `3.05mm` | 3.05 mm | 0.15 mm diametral |
| Bed Y 140 / `3.15mm` | 3.15 mm | 0.05 mm diametral |

Start with 2.95 mm, then choose the largest size that slides in using light finger pressure. Different holes may need different sizes. These are nominal CAD clearances; printed bore size, extrusion calibration and elephant foot determine the actual fit. Do not scale an STL: that would change its length and LED clearance too.

Six individual STLs are supplied, flat face down and long axis along bed X. The charger STL prints twice. The F3D/STEP include the unchanged enclosure and component references to show placement. They are not a new enclosure release.

## Printing

The X1C 0.4 mm project uses 0.10 mm layers, one wall, 100% aligned rectilinear fill, aligned top/bottom/internal fill, and 0° infill direction. Narrow-area infill substitution is disabled. Speeds are 20 mm/s, with 15 mm/s on the first layer. No supports or brim are required by the supplied geometry. Keep the guides horizontal and along X; rotating a part in the plate requires changing its fill angle too.

The single clear-PETG material is a starting profile based on installed Generic PETG: 255 °C nozzle, 70 °C textured PEI, 10–30% part fan, auxiliary fan off. Confirm these temperatures suit your spool, dry it per its maker's instructions, and use its calibrated flow value. The project does not assume a particular clear-PETG brand. Print at normal speed, without Sport/Ludicrous overrides.

CLI estimate for all nine pieces: about 29 minutes including startup, approximately 1.00 g. First-layer inspection remains disabled, following the successful fix for this printer's earlier inspection stall. Bed leveling and normal heater shutdown remain present.

Bambu's [PETG Translucent product guidance](https://us.store.bambulab.com/products/petg-translucent?id=42479468281992) notes that transparency depends on geometry and print settings. The installed slicer's infill options and the [Bambu Studio source](https://github.com/bambulab/BambuStudio/blob/master/src/libslic3r/Fill/Fill.cpp) were checked; the delivered G-code, rather than just its settings, was audited for line direction. There is no measured optical-efficiency guarantee for these FDM guides.

## Installation

1. Disconnect USB and battery power. Remove strings and any lip on the guide's flat printing face. Keep the end faces clean. Avoid shortening the locating collar or extending the tip.
2. Test fit sizes gently. For the front RGB guide, insert the narrow pickup end through the front indicator opening. Its collar stops against the outside front face; it projects 0.8 mm. The flat side faces toward the bottom of the sign.
3. Install the charger guides from inside the rear housing, before refitting the charger board. The shorter collar-to-end section enters the rear wall hole; the longer section points toward the LED. The extra small flat on each collar faces the nearby charger side fence. The broad printing flat faces toward the bottom of the sign.
4. Seat the charger collars against the inside rear wall. The outlets should finish about 0.1 mm inside the outside back surface. Refit the board and retainer; preserve the existing wire routes.
5. These are friction-located parts with insertion stops, not snap latches. With a snug fit they should have little lateral play. If a guide slides axially or rattles, secure its collar to the case with a tiny removable adhesive spot, keeping adhesive away from both optical ends and the electronics. Let any adhesive cure before installing electronics. Do not use the LED or PCB as a retaining stop. In particular, a loose rear guide must not slide forward against its LED.
6. Confirm the guides do not touch the LEDs, USB socket or wires. Nominal air gaps are 0.4 mm at RGB and 0.5 mm at the charger indicators. The front pickup narrows to 1.8 mm to give 0.32 mm nominal clearance from the USB metal shell.
7. Power up and check RGB and each charger indicator separately. Check brightness and unwanted light leakage before final assembly. The rear indications are viewed with the sign removed from its wall mounting. Light transmission and the final fit still need this physical test.

## Validation completed

- Original v2.8 component volumes unchanged; no housing, button or retainer reprint required.
- Largest 3.15 mm option checked against all native assembly/reference bodies, insertion paths and the case stop surfaces.
- All 45 established wire, termination and component-bay reservations remain clear.
- All six exported meshes are watertight, single connected solids, on Z=0, with a continuous bed face and no elevated horizontal undersides.
- Source and sliced 3MF meshes match the STLs. Slicer returned no warnings. All 968 straight infill runs longer than 1 mm are along X; short connections, curved turns and perimeters are excluded from that count.

The closeup images show simplified reference component envelopes, not detailed circuit-board models. Fit retention, optical brightness and the nominal LED gaps have not been physically tested with the user's printed parts.

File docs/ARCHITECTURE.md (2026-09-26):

# Current firmware architecture

Little On Air maintains one ESP32-S3 controller and one nRF52840 sign. The full
implementation reference is the [developer guide](../CONTRIBUTING.md#software-architecture),
including the [wire/storage contract](../CONTRIBUTING.md#protocol-and-persistence).

## Roles and ownership

- `apps/controller-esp32s3/`: Arduino UI/input loop, Preferences cache and one
  asynchronous NimBLE worker. The OLED separates selected, confirmed and verified
  state. Startup and background reconciliation read without changing the sign.
- `apps/receiver/`: Zephyr peripheral, encrypted GATT server, durable reset intent,
  independent power light, mood scheduler, status output and padded SPI driver.
  Its normal build always includes four pixels with 375 ns zero pulses.
- `src/`, `include/little_on_air/`: portable status/protocol, receiver processing,
  record/storage/reset helpers and pixel-frame encoding. Status/protocol are
  compiled into both device applications.
- `tests/host/`: host build for both devices' tests under `tests/`. It includes
  ESP32 input/state, actual receiver output/scheduling/reset logic and bond guards.
- `tests/unit/`: Zephyr core tests for protocol, persistence, reset and receiver
  processing. `tests/oled/` and `tests/pixels/` exercise actual rendering/encoding.

## Transaction and persistence

A command is six bytes: version 1, 32-bit little-endian transaction ID and status
0–5. The receiver validates and deduplicates, persists, applies, then acknowledges.
The controller confirms only an exact transaction/status match through an
indication or fallback state read. An ATT write response is not confirmation.
Do not automatically replay a command after an ambiguous acknowledgement failure.

Normal operations preserve pairing keys. Explicit Forget writes a durable
receiver reset intent, reboots and clears pairing/saved mood, with physical
five-reset recovery if communication fails. Factory rapid double-reset recovery
and nRESET remain intact. The NimBLE build guard and address-cache handling stop
ordinary security errors or address churn from silently replacing keys.

## Current output model

`apps/receiver/src/mood_indicator.c` schedules steady/animated moods and preserves
phase on unchanged reads. `status_output.c` drives four GRB pixels separately
from the onboard power LED. `padded_pixels.c` sends the shared encoder's 720-byte
frame in a single SPI DMA transfer: 300 µs low, 120 µs data, 300 µs low. The
complete pin/timing configuration is in `boards/xiao_ble_nrf52840.overlay`.

The old reset-button controller, its state machine/blink patterns, and optional
receiver comparison profiles were retired. [Firmware history](HISTORY.md) points
to their last source revision. Hardware history and published bundle bytes are
preserved separately; they are not active firmware targets.

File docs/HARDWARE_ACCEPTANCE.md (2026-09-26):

# Acceptance checks for the current device pair

Use the ESP32-S3 controller and four-pixel nRF52840 sign. Record the firmware
source revision and image hashes, case/board revisions, power arrangement and
what was actually observed. A build, protocol acknowledgement or simulation is
not evidence of physical light output, fit or current draw.

- [ ] Wiring, protection, polarity, charger configuration and case fit pass the
      current design's commissioning instructions.
- [ ] Controller runs on USB; sign runs on battery with POWER ON / RUN and both
      sign USB ports unplugged. OFF/PROGRAM isolation works for service/charging.
- [ ] Unpaired sign opens a 60-second window on RESET; controller knob Pair
      connects, and red power light changes from fast blink to steady.
- [ ] Turning previews without changing either mood light; pressing confirms
      Off, Warn, On Air, Okay, Request and Special on both devices.
- [ ] Request flashes at 600 ms on/off; Special flows across all four corners.
- [ ] Sign power light stays independent, including when mood is Off and during
      background reads. Repeated reads do not flash or restart mood animations.
- [ ] Receiver power loss/restoration retains the last accepted mood and bond.
- [ ] Controller USB power loss/restoration reads without advancing the mood.
- [ ] Offline screen shows Last/unverified state and dim white controller light;
      recovery reads the receiver without replaying a stale failed command.
- [ ] Hold opens settings; release after hold does not click. OLED dim/sleep,
      wake-only first gesture, menu timeout and local Light test work.
- [ ] Online Forget clears both devices, resets sign to Off and permits pairing.
- [ ] Offline Forget gives physical recovery; five paced receiver RESET presses
      clear pairing/state, while an interrupted sequence expires safely.
- [ ] Rapid receiver double-reset still opens the factory UF2 bootloader.
- [ ] Normal application updates preserve pairing/state; ESP32 writes do not
      erase NVS and receiver UF2 does not overwrite factory bootloader/settings.
- [ ] Measured battery/power behavior and charger indications are recorded for
      the actual parts and firmware, without reusing retired-board targets.

Use [FLASHING.md](FLASHING.md), [the developer guide](../CONTRIBUTING.md) and
[the current assembly guides](../hardware/README.md). Only check a box after the
physical action/observation. Store local raw captures under `.local/bench/` and
commit a concise dated record of the results and remaining limitations.

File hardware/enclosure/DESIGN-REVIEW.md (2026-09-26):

# ON AIR enclosure design review

**Implementation note:** This review records the earlier design findings. The resulting 34 mm-deep v2 enclosure and manufacturing files are now available in [the v2 build guide](output/v2/BUILD-AND-ASSEMBLY.md). Its retaining yoke also closes the port assembly notches, following insertion-path validation.

**Rebuild the enclosure around an integrated rear electronics housing and a shallow, self-contained front display assembly.** The battery cradle, PCB supports, switch nest, cable channels and screw bosses belong on that rear housing. The acrylic and its matching graphic belong together in the front assembly. This is a design recommendation; the current Fusion model, STLs and Bambu projects still contain the previous architecture.

The present files are printable prototypes, but their passing mesh and slicing checks do not establish a good FDM design. The main carrier has approximately **4,140 mm2 of horizontal underside at 2.925 mm above the bed**, supported initially by only about 66.6 mm2 of model contact. That broad suspended surface is an architectural problem worth removing.[^1]

*An explanatory diagram is included in the PDF.*

The proposed baseline has **six printed mechanical parts**: front bezel, rear housing, optical retainer, electronics retaining yoke, reset plunger and power slider. A printed black-and-white graphic makes seven printed pieces; a laser-engraved graphic instead keeps the count at six. The acrylic is always a separate laser-cut part. One small removable yoke is useful because fixed nests alone cannot hold components against every direction of motion.

Keep the 120 x 60 mm face. Budget approximately **32 mm depth** initially, then reduce it only after the actual hardware fits. A conservative stack through an edge-on XIAO totals about 30.2 mm before additional manufacturing margin. The earlier 30 mm depth was a modeling choice, not a required external dimension.

Priorities are repeatable optical alignment, reliable board restraint, accessible assembly and broad first-layer contact. A lower piece count or a shorter slicing estimate is valuable only when those properties survive.

## Existing design and print-plate findings

| Current plate | What it actually contains | Design consequence |
| --- | --- | --- |
| 1 | 90 M3 sample; 91 LED/acrylic sample; 92 reset-guide sample | These are test pieces, not backing or enclosure parts. Put them in a separate calibration project. |
| 2 | 01 body/front frame; 10 backplate | The existing full-depth front shell owns the ports while the carrier owns the boards. |
| 3 | 04 carrier; 05 charger keeper; 06 XIAO keeper; 07 plunger; 08 slider; 09 switch keeper | Move fixed mounts into the rear housing; replace the separate stationary keepers with a deliberate retention system. |
| 4 | 03 black-and-white graphic backing | This is the optical insert, not the rear cover. Its flat print orientation is appropriate. |

### The principal geometry defects

The carrier combines a large optical partition with forward LED fingers and rearward electronics fixtures. Its selected orientation puts the partition above the bed. Flipping it transfers the support problem to the fixtures. Adding small chamfers does not solve a suspended sheet spanning most of the enclosure; the front-side and rear-side functions need to be separated.[^1][^2]

The charger and switch keepers use locating legs but depend on ribs in the backplate to stop withdrawal. The XIAO fork depends on a case stop. These are real retention features, but they distribute one function across three different parts and complicate assembly. The new rear housing should own both the component position and its external port.[^1]

The power slider has a 9 x 5.2 mm external pad and an 8.2 x 5.2 mm internal flange around a 7.6 x 2.6 mm closed guide slot. Straight insertion from either side is unavailable. A tilted insertion maneuver might exist, but it was not demonstrated; the assembly instructions currently assume insertion without proving it. Redesign the capture geometry rather than relying on that maneuver.[^1]

The fit samples also need scrutiny. Sample 91 has roughly 245 mm2 of horizontal slot ceiling 5.4 mm above its bed. Sample 92 tests a vertical-axis bore, while the real side-button bore prints with a horizontal axis. Such samples cannot establish the finish or fit of those production surfaces. New samples must reproduce the actual orientation and assembly sequence.[^1]

These are manufacturing and assembly findings. They do not invalidate the earlier observation that the meshes are closed and the modeled solids do not collide.

## Part architecture and integration decision

| Architecture | Benefits | Limitations / decision |
| --- | --- | --- |
| Separate optical/electronics carrier (current) | Electronics lift out together; rear stays relatively flat. | Broad supported underside; extra partition, latches and keepers. Replace. |
| Mounts on graphic backing | Combines a large plate with support structures. | Bends and loads the optical datum; complicates two-color face printing; ties graphics to electronics revisions. Reject. |
| Fixed mounts on rear cover, ports in front shell | Consolidates fixtures and gives the rear a flat print base. | Still requires aligning mounted boards to another part during closure. Acceptable fallback. |
| Rear housing with fixed mounts AND ports; separate front optics | Common datum for USB and controls; structures grow from a flat rear base; front optics can remain assembled. | Needs a defined front/rear seam and one serviceable retention yoke. Recommended. |

### Proposed manufactured parts

| Part | Integrated features | Reason to remain separate |
| --- | --- | --- |
| Front bezel | LED pockets, acrylic seat, common graphic datums, optical-retainer fixing points | Print front down; remove front optics for service. |
| Rear housing | Flat wall face, side walls, board nests, battery cradle, switch nest, wire guides, nut bosses, ports | Print wall face down with all fixtures growing upward. |
| Optical retainer | Perimeter clamp and four broad LED hold-down pads | Print flat with pads upward; retain acrylic and graphic without an electronics partition. |
| Electronics yoke | Contact pads for safe PCB edges and switch body | Removable restraint, screwed into the rear housing; no reliance on spring friction. |
| Reset plunger / power slider | Captive moving interfaces with positive stops | Motion requires separate parts. |
| Graphic / clear acrylic | Matching keyed outline and common text master | Independent optical fabrication and replacement. |

The yoke should be an open frame, not another full sheet. Print its broad frame down and its contact legs upward; install it with the legs facing the components. Its load is component lift-out restraint. USB insertion and withdrawal loads go into short stops on the rear housing. If one yoke would require a long flexible arm or obstruct soldering, use two short bars; do not trade reliability for a nominal part-count target.

## Rear housing and component layout

*An explanatory diagram is included in the PDF.*

Keep the broad battery footprint near the center/lower half, the charger near the top left, the DPDT near the top center, and the XIAO at the right with its USB facing upward. The drawing is a packaging proposal in front-view coordinates, not a dimensionally completed CAD layout. It preserves useful parts of the existing placement while changing what supports them.

**Battery:** start with a 54 x 23 mm pocket for the supplied 52 x 21 mm pouch and reserve at least 11.5 mm thickness including free space, before any chosen pad. Use short rounded fences and a loose nonconductive strap. Put strap slots in raised lugs with short self-supporting roofs; keep the wall-facing skin intact. A hard clamp must not preload the pouch. Keep its lead exit and insulated connections clear of every closure rib.

**Charger:** the specified listing identifies a USB-C TP4056 board. The old 16.5 x 25 mm footprint is a provisional envelope, not a verified tolerance drawing. Seat the actual board on bare support areas, leave its underside and solder pads clear, add stops on both sides of USB insertion travel, and use the yoke only at component-free contact locations.[^12]

**XIAO:** keep the edge-on orientation initially. It exposes the reset button to a direct side plunger while leaving USB at the top. A flat PCB would reduce depth, but its face-normal reset would then require a bell crank or a different switch arrangement. That adds moving parts and calibration. The official Seeed page provides a reset reference and a mechanical DXF; identify the physical board revision before using these resources as final dimensions.[^11]

**DPDT:** cradle the 8.6 x 3.1 x 2.7 mm body, not its six terminals. Keep an open solder/insulation bay below it. Its 1.4 mm actuator height does not specify its throw. The slider socket should transmit only operating force; a larger housing guide must absorb accidental finger side loads.

Keep both USB receptacles, their board seats, button guides and travel stops on the rear housing. Fit the actual cable overmolds through chamfered openings and check full seating. Keep metal hardware, reflective foil and the battery away from the XIAO antenna area where practical, then verify radio performance in the closed sign.

## Acrylic optics and edge coupling

*An explanatory diagram is included in the PDF.*

For this sign, ordinary clear cast acrylic with selectively engraved lettering is a sound starting material. The smooth sheet guides light, and the engraving scatters light out where the letters are. The white graphic behind it reflects some escaping light and supplies an unlit white-on-black appearance. It is not a second light guide.[^5][^7]

Special light-guide sheets containing scattering particles serve a different purpose: they intentionally illuminate their whole surface. Their uniformity claims should not be applied to four separate LEDs illuminating ordinary engraved acrylic. Retain clear unengraved background regions for the intended dark field.[^6]

Keep the four LED pockets in the front bezel so the acrylic edge and emitter share one locating structure. Use two LEDs along each long edge as the initial layout. Align the **emitting window center** to the measured sheet midplane. An 8 x 8 x 2 mm module envelope does not reveal that optical center. Start with a 0.2-0.3 mm non-contact edge gap, then tune with the actual modules and soldered leads.

ACRYLITE recommends polished entry edges and reflective treatment on unused edges. Keep coupling windows clear; place nonconductive white reflector strips behind unused edge regions and between LED sites where space allows. Keep those strips out of the wiring and antenna area. A clean laser-cut edge may be sufficient, but inspect and test it before deciding whether additional finishing is needed.[^5]

Do not laminate the display faces together. PLEXIGLAS notes that bonding and surface treatments change light transmission; the air interfaces are part of the optical system. Use a small controlled air gap and perimeter contact outside the visible field. Do not let retaining pads bear on the engraved letters.[^6]

The 60 mm case height leaves little spare LED space: 38 mm acrylic + two 8 mm modules + two 0.2 mm entry gaps + two 2.4 mm outer walls = **59.2 mm**, before pocket clearance. Route solder leads sideways along the edge rather than assuming there is room behind each module. Verify the actual separated modules before preserving this width of bezel.

## Graphic backing, spacing and artwork

**Keep the graphic separate, flat and replaceable.** A laser-engraved sheet with a black surface and white core is the preferred finish option: removing the surface reveals the white letters, and both optical parts can use the same vector geometry. Trotec describes this two-layer construction. Reflectance and the final illuminated appearance still require a sample; no product page establishes the performance of this particular stack.[^9]

The existing FDM concept remains a reasonable no-new-material alternative: a 1.6 mm black substrate with 0.4 mm white raised letters, printed back down. Keep that separate from electronics holders. Check whether two white layers are opaque enough over black; use a 0.4 versus 0.6 mm lettering sample if necessary. The chosen relief changes the spacer height and color-change plan.

| Interface | Proposed control | Why it matters |
| --- | --- | --- |
| Acrylic / graphic XY | Two shared perpendicular datum edges; compliant pads on opposing edges | A clipped corner controls orientation only. It does not remove translational play. |
| Perimeter clearance | Start around 0.25 mm per side away from locating datums; measure and tune | Two independently floating panels can differ by 0.5 mm on one axis even when their outlines match. |
| Engraving / white-face gap | Test 0.3 and 0.5 mm, set by perimeter stops and shims | Smaller gap reduces apparent doubling; sufficient clearance prevents contact due to bow. |
| Clamping | Broad low-force perimeter pads; hard closure stops outside optics | Screw torque must not bend the graphic or load the acrylic. |

For a first-order air-gap calculation, lateral separation is g x tan(theta). At a 45-degree viewing angle a 0.5 mm gap produces about 0.5 mm apparent offset between the rear engraving plane and graphic; a 0.3 mm gap produces about 0.3 mm. Engraving depth and actual optical paths add detail to this estimate. Identical text contours alone therefore cannot eliminate oblique-view doubling.

Thermal clearance also has a scale: ACRYLITE gives a cast-sheet coefficient equivalent to 0.000072 per degree C. A 104 mm panel changes length by about 0.225 mm for a 30 C change. This is an illustrative free-sheet calculation, not the relative movement against PETG. A compliant edge restraint is preferable to a hard interference fit.[^10]

Maintain one front-view text master as vector outlines. The acrylic rear-engraving file mirrors **both text and asymmetric cut key**. A front-engraved black/white laminate uses the unmirrored master. FDM text uses that same master. Keep cut and filled-engrave layers separate, preserve millimeters and apply measured laser kerf compensation once. The old artwork contour audit is useful, but does not validate physical registration.[^1][^7]

Epilog and Trotec agree that cast acrylic produces strong frosted engraving, but differ in how broadly they promise polished cut edges. Treat edge quality as machine- and sheet-dependent. Measure the actual thickness; 3.000 mm and 1/8 inch (3.175 mm) are different, and cast sheet also varies.[^7][^8]

## Fasteners, moving controls and service access

*An explanatory diagram is included in the PDF.*

The closure screws must pass through the front bezel and engage metal nuts retained by solid bosses in the rear housing. The nuts pull against the front-facing roof of those bosses. The rear skin remains closed. This gives a direct load path from screw head to front compression seat to rear boss to nut; the acrylic, graphic and battery are outside that path.

Keep the existing M3 socket-head approach with recessed cylindrical counterbores. Add gussets from tall bosses to the rear floor or side walls. Stratasys recommends supporting FDM bosses and using metal fastening interfaces. Preserve a flat bearing surface under the head; a self-supporting bridge detail can be added above the counterbore without replacing the bearing surface with a cone.[^4]

The existing 30 mm model places the screw bearing plane at 3.2 mm and uses a 25 mm screw, so the tip reaches 28.2 mm. Its blind bore ends at 28.7 mm and its rear skin starts there, leaving the modeled 0.5 mm tip gap and 1.3 mm skin. This explains why the back stays attached without an exterior rear hole. A revised depth or boss position requires recalculating nut engagement and tip clearance; do not transfer the hardware length blindly.[^1]

**Reset:** use a single captive inner flange larger than the guide bore, a stem that passes through from inside, and a small contact tip. Add a 45-degree underside transition to make the flange printable with the outer stem end down. The housing provides an inward hard stop; tune the tip for no resting preload and full release. The tactile switch provides the return force, which must exceed guide friction. Verify paced resets and rapid double reset on the real board.[^11]

**Power:** remove the insertion ambiguity. Use one oversized inner flange, with the outer grip small enough to pass through the elongated wall opening. The opening length must cover grip length + measured switch travel + running clearance. Alternatively, use a guide open to the case seam and close it with the mating part. The chosen path must be demonstrated in CAD and with a small printed sample.

Use two accessible internal screws for the optical retainer and two for the electronics yoke, with blind captive-nut or specified insert features. Their lengths are separate from the four external closure screws. First install optics in the bezel, then electronics and controls in the rear housing, connect a flexible LED harness, and join the halves. Disconnect external USB cables before opening. Provide enough harness slack to support the front during disconnection.

A rear housing fixed directly to the wall leaves electronics on the wall during service. Keep the yoke and wiring accessible from the front. Preserve a flat adhesive area and accessible strip-removal tabs; select a strip format that fits the 60 mm height. 3M distinguishes detaching picture-strip pairs from stretching the adhesive strip downward for removal.[^14]

## FDM geometry and slicing strategy

| Part | Print orientation | Geometry objective |
| --- | --- | --- |
| Front bezel | Visible front face down | Walls and LED pocket rails rise from the bed; remove old carrier-latch shelves. |
| Rear housing | Wall-facing exterior down | Floor first, then side walls, nests and gusseted bosses. No broad suspended partition. |
| Optical retainer | Broad frame down, LED pads up | Open center, short supported-at-root contact pads; no underside fingers. |
| Electronics yoke | Broad frame down, contact legs up | Open access to cables; no long horizontal roofs over electronics. |
| Reset plunger | Outer stem end down, chamfered flange above | Add a brim if needed; protect the contact tip from support scars. |
| Power slider | Broad captive flange down, grip up | Use an open or short-bridge actuator socket and chamfer any expanding shoulder. |
| Printed graphic | Black flat back down, white letters up | One color change after the black base; no supports. |

Use 45-degree self-supporting slopes as a conservative design starting point, measured from the horizontal build plane. Apply them beneath outward shelves and to entry edges. Add fillets at upward-growing rib roots to reduce stress concentration where they do not introduce unsupported undersides. A chamfer is a shape change; joining a holder to the rear housing requires a real solid connection and adequate root area.[^2][^4]

Start structural skins near 2.4 mm and useful fixture ribs near 1.6-2.4 mm, with local reinforcement around USB stops and fasteners. These are proposed dimensions, not material allowables. Inspect generated extrusion paths rather than assuming a dimension corresponds to an exact number of nozzle widths. Avoid long 0.8 mm spring leaves as the primary component restraint.

For the X1 Carbon and 0.4 mm nozzle, retain 0.20 mm layers, four walls and five top/bottom layers as a conservative first build. Start near 20-25% infill for large parts, with local solid regions for small bosses and solid small controls. Use the actual filament preset. The earlier Generic PETG selection and color availability were assumptions, not a confirmed material inventory.

PETG is suitable for this prototype, but its difficult support removal and weaker bridging behavior make support-heavy precision pockets undesirable. Bambu PETG HF has its own drying and print guidance; do not assign those properties or temperatures to every PETG spool. The main improvement here is removing difficult support interfaces from the model.[^3][^13]

Aim for no generated support on the major optical or board locating surfaces. Check short bridges over nut traps and port openings individually; use teardrop/45-degree roofs or accessible local support where necessary. Do not describe the redesign as support-free until its actual sliced layers confirm it.

Package the new job as **Structure** (bezel and rear housing), **Retainers and controls**, and **Graphic** if printed. Put fit samples in a separate named calibration project. Keep graphics alone on the color-change plate so tall black fixtures do not inherit the white layers. New time and material estimates require the new geometry; the previous estimates cannot be reused.

## Prototype sequence and release criteria

The redesign can proceed parametrically, but exact interfaces remain dependent on the actual components. Record the following measurements once and use them consistently across seats, openings, restraints and test pieces.

| Measurement | Required detail |
| --- | --- |
| Acrylic / laser | Thickness at several points; cut-edge size and kerf; flatness; engraving result. |
| Four LED modules | Maximum footprint after separation and soldering; emitter center and emitting direction; insulated lead envelope. |
| XIAO | Board revision; populated height both sides; bare PCB support zones; USB projection; reset center, force and travel. |
| Charger | Actual board size, thickness, underside parts, pads and soldered wires; USB projection and cable overmold. |
| DPDT | Body and terminals after soldering; both actuator endpoints; throw; necessary access to six connections. |
| Mounting / hardware | Actual M3 heads and nuts; intended adhesive-strip footprint and release tabs; real filament and plate surface. |

### Three economical validation builds

**1. Optical slice:** print a short section of the revised bezel and retainer in their production orientations. Use the actual acrylic and one soldered LED. Compare 0.3 and 0.5 mm optical gaps, edge-coupling alignment, and both graphic methods if available. Check unlit readability and the illuminated letters at normal and oblique viewing angles. This replaces the old covered-slot coupon.

**2. Mechanical interfaces:** print the actual rear-housing wall section containing each port/board seat and the complete control capture features. Demonstrate board insertion, yoke attachment, full USB seating, reset return and slider installation. Repeat button and switch operation and cable insertion enough to expose looseness or binding; a proposed screening target is 50 operations, not a life rating.

**3. Full assembly:** build one enclosure only after the interfaces fit. Verify the four LEDs across the entire text; four discrete emitters cannot be assumed to give uniform brightness. Inspect for pressure marks, rattling, alignment shift, cable pinching and light leakage. Check the intended firmware colors, reset gestures and radio connection in the mounted position.

The final CAD review must include the swept space of the moving controls and the insertion/removal path of each component, not only static interference. The final slicer review must check first layers, bridge direction, isolated islands, support accessibility, mating surfaces and actual color changes. Every delivered part needs an assembly role and a clear plate name.

Check closed-case temperature during the intended lighting and charging operation using the actual circuit. The XIAO already has charging hardware, and this design also reserves the requested external charger. The enclosure review does not determine how those power paths should be connected or the appropriate cell charge current. Keep wiring decisions and component clearances consistent with the established circuit.[^11][^12]

**Design disposition:** revise the case architecture before committing to the current full-size print. Preserve the existing CAD and print files as the v1 baseline. The research supports the integration strategy, but the proposed rear housing, retainer and yoke have not yet been modeled or physically validated.

## Sources and evidence scope

Manufacturer guidance informs the process choices. Proposed dimensions, part architecture, tolerance examples and acceptance steps are engineering recommendations for this enclosure. They are not manufacturer guarantees. The local face-area calculation measures horizontal surfaces only; it does not estimate support volume or certify printability.

Official mechanical resource retained for the next CAD revision: Seeed Studio, [XIAO nRF52840 DXF archive](https://files.seeedstudio.com/wiki/XIAO-BLE/XIAO-nRF52840-DXF.zip), accessed 8 September 2026. The archive contains top and bottom drawings. It must be matched to the actual board; the current Fusion electronics are still simplified envelopes.

## Reference notes

[^1]: Local enclosure artifacts. Existing print projects, oriented STL meshes, assembly instructions and independent audit. Reviewed 8 September 2026. hardware/enclosure/output/print/; output/bambu-studio/audit/independent-audit.json; enclosure README.md. New horizontal-face measurements and hashes are in output/design-review/geometry-observations.json.

[^2]: Prusa Research. [Modeling with 3D printing in mind](https://help.prusa3d.com/article/modeling-with-3d-printing-in-mind_164135). Undated; accessed 8 September 2026. Overhangs, chamfers, orientation and fit variability.

[^3]: Prusa Research. [PETG](https://help.prusa3d.com/article/petg_2059). Undated; accessed 8 September 2026. PETG support removal and bridging limitations; Prusa temperatures are not transferred to the X1C.

[^4]: Stratasys Direct. [FDM Design Guide](https://www.stratasys.com/siteassets/sdm/content---website-storage/design-guides/dg_sdm_fdm_0725a.pdf?v=490918). 2025 edition identified by file 0725a; pp. 5-9. Boss reinforcement, fillets, orientation and fasteners. Industrial soluble-support capabilities are not assumed for this print.

[^5]: ACRYLITE / POLYVANTIS. [Light piping acrylic](https://www.acrylite.co/resources/knowledge-base/article/what-information-do-you-have-on-light-piping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). Undated; accessed 8 September 2026. Standard acrylic, polished entry edges, surface quality and reflective unused edges.

[^6]: PLEXIGLAS / POLYVANTIS. [PLEXIGLAS LED: Solid Sheet and Rod, Ref. 212-15](https://www.plexiglas.de/files/plexiglas-content/pdf/technische-informationen/212-15-EN-PLEXIGLAS-LED-edge-lighting.pdf). July 2024; pp. 3-4. Total reflection, surface-scattering grades, edge coupling and effect of bonding. Whole-panel LED-grade performance is not a prediction for ordinary engraved acrylic.

[^7]: Epilog Laser. [Laser Cutting Acrylic](https://www.epiloglaser.com/en-ca/how-it-works/applications/laser-cutting-acrylic/). Undated; accessed 8 September 2026. Cast versus extruded engraving, reverse artwork and light engraving.

[^8]: Trotec Laser. [Tips and tricks for processing acrylic](https://www.troteclaser.com/en-tt/helpcenter/materials/material-usage-hints/material-handling-acrylic). Undated; accessed 8 September 2026. Thickness variation, cast engraving and edge-quality guidance.

[^9]: Trotec Laser. [TroLase: Laserable Plastic for Engraving and Cutting](https://shop.troteclaser.com/en-US/trolase-laserable-plastic). Undated; accessed 8 September 2026. Two-layer engraving sheet exposes a contrasting core. Use black surface over white core.

[^10]: ACRYLITE / POLYVANTIS. [Expansion and Contraction of Acrylic](https://www.acrylite.co/resources/knowledge-base/article/-how-do-i-figure-out-expansion-and-contraction-of-acrylic-for-a-glazing-application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). Undated; accessed 8 September 2026. Cast acrylic coefficient 0.000040 per degree F, equivalent to 0.000072 per degree C.

[^11]: Seeed Studio. [Getting Started with XIAO nRF52840 Series](https://wiki.seeedstudio.com/XIAO_BLE/). Page updated 7 September 2026; accessed 8 September 2026. Reset operation, onboard charger and official mechanical resources. Original nRF52840 must be distinguished from Sense and Plus revisions.

[^12]: HiLetgo / Amazon listing. [TP4056 Type-C USB 5V 1A charger, ASIN B07PKND8KG](https://www.amazon.com/dp/B07PKND8KG). Accessed 8 September 2026. Identity of the specified module; listing is not a tolerance-controlled mechanical drawing.

[^13]: Bambu Lab. [PETG HF](https://eu.store.bambulab.com/en-mt/products/petg-hf?variant=49068714557788). Undated; accessed 8 September 2026. Drying guidance and filament-specific properties. Does not establish the properties of unidentified Generic PETG.

[^14]: 3M Command. [How to Use Picture Hanging Strips](https://www.command.com/3M/en_US/command/how-to-use/picture-hanging-strips/). Undated; accessed 8 September 2026. Removable strip application, separation and downward stretch removal.

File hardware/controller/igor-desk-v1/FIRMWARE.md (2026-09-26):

# Controller firmware migration

This revision defines the **new controller hardware**. The existing
`apps/controller` application, overlays, UF2 images, reset gesture and build
instructions still describe the nRF52840 controller. They are not ESP32-S3
firmware. Igor's upstream D1-mini timer sketch is also not a Little On Air
controller and must not be treated as the new firmware.

## Intended local interaction

- Boot from computer USB, show **Connecting**, then read the receiver's
  authoritative state. Boot never advances or sends a state.
- Turn the encoder to choose **Off → Warn → On Air → Okay**. Rotation previews
  a selection; it does not change the receiver.
- Press once to send the selected state. Show **Sending** until the exact
  transaction/status acknowledgment arrives.
- Show **Confirmed** and a solid matching pixel only after the receiver's
  persisted/applied acknowledgment. The OLED labels also convey the status.
- On timeout, show the failure and reconcile with a read. Keep the last
  confirmed state visibly distinct from the pending selection.
- Pair through a deliberate on-screen action and the receiver's existing
  physical pairing window. Require an additional confirmation before erasing
  a bond; pressing or holding the encoder during boot must not erase it.
- Dim or blank the OLED after inactivity to reduce static-image wear. Wake on
  interaction while keeping the receiver's status unchanged.

## Implementation boundary

Retain the existing encrypted, bonded BLE central/peripheral relationship and
six-byte version-1 protocol. **ESP-NOW is not compatible with the existing
nRF52840 receiver.** Keep its service/characteristic UUIDs, little-endian
transaction IDs, indication subscription, exact-ack matching and recovery
semantics from `docs/ARCHITECTURE.md`.

The ESP32-S3 port needs:

1. Its own supported board configuration and flash format, USB diagnostics,
   GPIO encoder debounce, SSD1306 I2C display driver and WS2812B output driver.
2. Event-driven input during runtime instead of the nRF reset-pin boot action
   and terminal `sleep_forever()` lifecycle. Retain responsive input/rendering
   while BLE operations run.
3. Bond/state storage on ESP32 flash. Remove nRF-only `RESETREAS`, UICR,
   GPREGRET2, nRF PWM and battery-current assumptions from that application.
4. A reviewed pairing and factory-reset UI, display error states, brightness
   limit, encoder direction check, and a bounded reconnect policy.
5. A real ESP32-S3 build plus bench tests against the existing receiver for
   first pairing, command acknowledgment, lost indications, reboot, USB power
   loss, peer replacement and input bounce.

The reusable protocol and state-machine code can remain shared. Add a
controller-specific board/output layer rather than switching the receiver's
board or changing the established wire protocol.

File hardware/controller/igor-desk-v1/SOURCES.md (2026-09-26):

# Source geometry and references

Retrieved 2026-09-14 (local date).

## Exact Project IGOR basis

- Requested model: [Printables 1019283 — Project IGOR](https://www.printables.com/model/1019283-project-igor-open-source-offline-loyal-cheerful-fo).
- Creator: **UrbanCircles / Peter**.
- Creator-maintained repository: [UrbanCircles/igor](https://github.com/UrbanCircles/igor).
- Pinned commit: `7543085fe11f102f121f08aabd8f6c25c38bdf60`.
- Original STEP path: `3D Parts/Project IGOR v1 - shell, faceplate, basic hat (STEP).step`.
- Original 3MF path: `3D Parts/Project IGOR v1 - shell, faceplate, basic hat.3mf`.
- The STEP is copied byte-for-byte to `upstream/igor-v1.step`; SHA-256:
  `9645738bee23f74ca35bc64abd22047e27ce61a9ba0c0e83864a13e755bd8c33`.
- The original 3MF and repository MIT license are included alongside it.

Printables did not return the model page to the research fetcher. The original
geometry was obtained from the author's public repository, whose README describes
Igor's components and assembly. This remix does not use a traced
picture, unrelated enclosure or reconstructed approximation of Igor.

The creator's generic OLED description does not uniquely identify a currently
sold PCB. The original model's screen opening and mounting centers therefore
define compatibility. Match the actual module before printing the full shell.

## XIAO board reference

- [Seeed getting-started page and mechanical downloads](https://wiki.seeedstudio.com/xiao_esp32s3_getting_started/).
- [Manufacturer 3D-model ZIP](https://files.seeedstudio.com/wiki/SeeedStudio-XIAO-ESP32S3/res/seeed-studio-xiao-esp32s3-3d_model.zip).
- `XIAO-ESP32S3 v2.step` is stored locally as `reference/xiao-esp32s3-seeed.step`
  for fit checks. It is manufacturer reference data, not an original Little
  On Air design. SHA-256:
  `870ad45c7af5d92324cec4c6ae65fbf86e3b049d5a97ab9ffd9039ebd73455dd`.

## Electrical references

- [Seeed pin map and USB power](https://wiki.seeedstudio.com/xiao_esp32s3_getting_started/).
- [TI SN74AHCT1G125](https://www.ti.com/product/SN74AHCT1G125).
- [Adafruit NeoPixel level shifting](https://learn.adafruit.com/adafruit-neopixel-uberguide/logic-level).

Wheel-weight dimensions in this revision are an explicit **maximum envelope**,
not a claim that all 5 g or all adhesive wheel weights are interchangeable.

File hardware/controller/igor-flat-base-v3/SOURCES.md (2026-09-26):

# Source geometry and references

Retrieved 2026-09-14 (local date).

## Exact Project IGOR basis

- Requested model: [Printables 1019283 — Project IGOR](https://www.printables.com/model/1019283-project-igor-open-source-offline-loyal-cheerful-fo).
- Creator: **UrbanCircles / Peter**.
- Creator-maintained repository: [UrbanCircles/igor](https://github.com/UrbanCircles/igor).
- Pinned commit: `7543085fe11f102f121f08aabd8f6c25c38bdf60`.
- Original STEP path: `3D Parts/Project IGOR v1 - shell, faceplate, basic hat (STEP).step`.
- Original 3MF path: `3D Parts/Project IGOR v1 - shell, faceplate, basic hat.3mf`.
- The STEP is copied byte-for-byte to `upstream/igor-v1.step`; SHA-256:
  `9645738bee23f74ca35bc64abd22047e27ce61a9ba0c0e83864a13e755bd8c33`.
- The original 3MF and repository MIT license are included alongside it.

Printables did not return the model page to the research fetcher. The original
geometry was obtained from the author's public repository, whose README describes
Igor's components and assembly. This remix does not use a traced
picture, unrelated enclosure or reconstructed approximation of Igor.

The creator's generic OLED description does not uniquely identify a currently
sold PCB. The original model's screen opening and mounting centers therefore
define compatibility. Match the actual module before printing the full shell.

## XIAO board reference

- [Seeed getting-started page and mechanical downloads](https://wiki.seeedstudio.com/xiao_esp32s3_getting_started/).
- [Manufacturer 3D-model ZIP](https://files.seeedstudio.com/wiki/SeeedStudio-XIAO-ESP32S3/res/seeed-studio-xiao-esp32s3-3d_model.zip).
- `XIAO-ESP32S3 v2.step` is stored locally as `reference/xiao-esp32s3-seeed.step`
  for fit checks. It is manufacturer reference data, not an original Little
  On Air design. SHA-256:
  `870ad45c7af5d92324cec4c6ae65fbf86e3b049d5a97ab9ffd9039ebd73455dd`.

## Electrical references

- [Seeed pin map and USB power](https://wiki.seeedstudio.com/xiao_esp32s3_getting_started/).
- [TI SN74AHCT1G125](https://www.ti.com/product/SN74AHCT1G125).
- [Adafruit NeoPixel level shifting](https://learn.adafruit.com/adafruit-neopixel-uberguide/logic-level).

Wheel-weight dimensions in this revision are an explicit **maximum envelope**,
not a claim that all 5 g or all adhesive wheel weights are interchangeable.

## Corrected orientation and front pixel (revision 3)

The broad bottom face and encoder mount are parallel in the exact source.
The assembly is rotated -30° about X into its desk frame before editing.
The base, encoder-plane and rear-wall normals are checked in CAD. Revisions
1 and 2 used an incorrect desk orientation and are superseded.

The front LED is now a 5 mm through-hole addressable NeoPixel, such as
[Adafruit 1938](https://www.adafruit.com/product/1938). Its product page specifies
RGB color order and 5 V power. Checked 2026-09-15; listed out of stock. The CAD
uses an explicit conservative envelope rather than a manufacturer LED solid.
Check the purchased flange, body dimensions and soldered lead arrangement.

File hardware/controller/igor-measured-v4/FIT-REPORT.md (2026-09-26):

# Fit report — measured revision 4

Dimensions are millimeters. The user's measurements drive the OLED, encoder,
strip and weight models. Seeed's STEP drives XIAO fit. Clearances below are
nominal CAD gaps, not guarantees of printed tolerance.

| Part | Supplied geometry | Fit provided |
| --- | --- | --- |
| Weights, quantity 2 | Each 20 × 33.5 × 6.5, including foam adhesive | 41 × 34.1 well; 0.25 at outer sides, 0.5 between weights; 0.7 below carrier; at least 2.4 solid floor |
| Encoder PCB | 19.25 × 26.4 × 1.5; solder extends 2 below | Entire underside solder envelope reserved; board supported through encoder box, no locating pegs through uncertain holes |
| Encoder box | 12 × 12 × 7, measured asymmetric offsets | 12.4 × 12.4 locator; 0.2 per side and 0.25 above; header faces front |
| Registration tab | 1.2 above box; plan dimensions unspecified | Conservative 12 × 3 envelope; slot continues down for insertion; 0.25 clearance above |
| Collar | Diameter 6.8, length 7 | Diameter 7.2 roof hole; enlarged knob underside clearance |
| Shaft | Diameter 6, exposed length 13.25; flat chord 5.4 | D socket radius 3.1, flat clearance 0.15; original outside knob shape |
| Button movement | Travel not supplied | 1 mm sampled press allowance; knob stands 1.2 above roof and retains 0.2 at full allowance |
| Encoder header | Plastic 12.45 × 2.5 × 2.45; pins 2.4 above, 4.7 beyond board, diameter 0.64 | Full measured plastic and bent pins retained; separate 13.5 × 8.5 × 3 connector allowance |
| OLED PCB | 27.6 × 27.9 × 1.25 | Side and end guides provide 0.2 each; corner stops contact PCB front |
| OLED glass | 26.6 × 19.2, 2 above PCB front | 0.5 gap from faceplate rear; no supports press on glass |
| OLED active area | 25.5 × 14.5, 5 from top and 0.75 from left | 26.2 × 15.2 throat, centered on measured active area; front bevel opens to 29.2 × 18.2 at the face surface |
| OLED solder and ribbon | Front solder 1.85; centered 14.5 × 2.5 board notch; ribbon about 2 above board | Untrimmed solder reserved; central lower relief keeps stops and glue clear of ribbon |
| OLED header | 10 × 2 footprint, plastic 2 and pins another 5.8 behind PCB | Full header and pins retained; separate 10.8 × 8 × 2.6 connector allowance |
| Mini NeoPixel strip | 5 × 17.6 × 1.4, centered LED | 5.4 wide holder; 0.2 per side/end, 0.2 mounting tape allowance; no trimming required |
| Diffuser | Added printed part | Diameter 5 visible stem, 6.4 flange, 2.4 total thickness; 0.15 stem and 0.2 flange radial clearance; 1.5 gap to LED envelope |
| XIAO ESP32-S3 | Manufacturer reference STEP | 0.21 PCB side clearance, 0.3 mounting tape, USB tip about 0.11 beyond rear wall; 9.8 × 4.6 USB opening |

## Weight capacity and preserved shape

Two weights fill the usable flat-bottom compartment in one layer. Three would
require another row or extra width beyond the existing rear compartment; the
raised front nose is excluded. Both weights adhere directly to the floor.
The base extends down 9.5 mm; the curved nose continues into the extension.
The original outside width/depth, vertical rear wall, display angle and closure
are retained. No separate bottom cover is introduced.

## Diffuser retention

The diffuser is inserted from behind the faceplate. Its 6.4 mm flange cannot
pass through the 5.3 mm front hole. The strip holder blocks rearward movement.
Four short tabs retain the holder: insert it from behind, 3 mm above its final
position, then slide it down. A small top glue bead prevents it sliding back
up. A tiny perimeter adhesive dab can remove the flange's nominal axial play;
keep adhesive out of the optical path. Transparent PETG at 100% infill is the
starting print specification; diffusion and brightness have not been measured.

## Checked digitally

- Every printable part is a valid single solid and a watertight connected mesh.
- No nominal overlap of measured components with printed parts or other modules.
- Untrimmed solder, complete headers, assumed connector envelopes and ribbon
  clearance are included, rather than checking bare PCB rectangles alone.
- Sampled knob rotation and a 1 mm press, encoder insertion before ballast,
  weight loading, empty carrier loading and XIAO insertion.
- Diffuser insertion and capture, holder entry/slide, strip insertion and
  closure of the populated faceplate.
- An unobstructed face-normal view of the entire measured active display area.
- Continuous floor beneath both weights and unchanged source geometry outside
  explicitly allowed edits, with a 0.01 mm³ numerical boolean tolerance.
- Three Bambu Studio projects sliced with support settings included; all
  project meshes match the delivered STLs.

Detailed results: [geometry](output/validation/geometry.json),
[fit](output/validation/fit.json), [slicing](output/validation/slicing.json).

## Measurements that remain approximate

The encoder's 5.4 mm dimension is **confirmed along the flat face**, giving a
flat plane 1.308 mm from the shaft center. Hole positions are interpreted as
edge clearances; small inconsistencies do not affect fit because there are no
printed locating pins. The encoder's approximate 1.9 mm pin spacing is modeled
conservatively as a clear gap (2.54 mm pitch); no mating connector is fabricated.

Registration-tab width/depth, actual push travel and mating connector housings
were not supplied. Their allowances are explicit above. Flexible leads and the
XIAO antenna are routed during assembly; they are not fully modeled harnesses.
Actual display controller/resolution and pixel color order need bench verification.
No physical print, assembly, USB-plug housing fit or optical test is claimed.

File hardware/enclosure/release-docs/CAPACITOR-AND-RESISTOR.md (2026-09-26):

# Connecting the capacitor and data resistor

Fit **one C1: 680 µF electrolytic capacitor, rated at least 6.3 V**, and **one R1: 330 Ω resistor** for the whole four-pixel chain. Both can be soldered into the wire harness; no extra circuit board is needed. Keep the small components already fitted to each NeoPixel module.

## What they do

**C1 steadies the LED supply.** It stores a little energy and releases it during brief changes in LED current, helping reduce short voltage dips and glitches. It does not raise the battery voltage or control battery charging.

**R1 protects the first pixel's data input.** It reduces sharp signal transients and limits brief input current. It carries the data signal, not the LEDs' power, so it is not a brightness-setting resistor. The selected values and placement follow [Adafruit's NeoPixel guidance](https://learn.adafruit.com/adafruit-neopixel-uberguide/best-practices).

## Where each lead goes

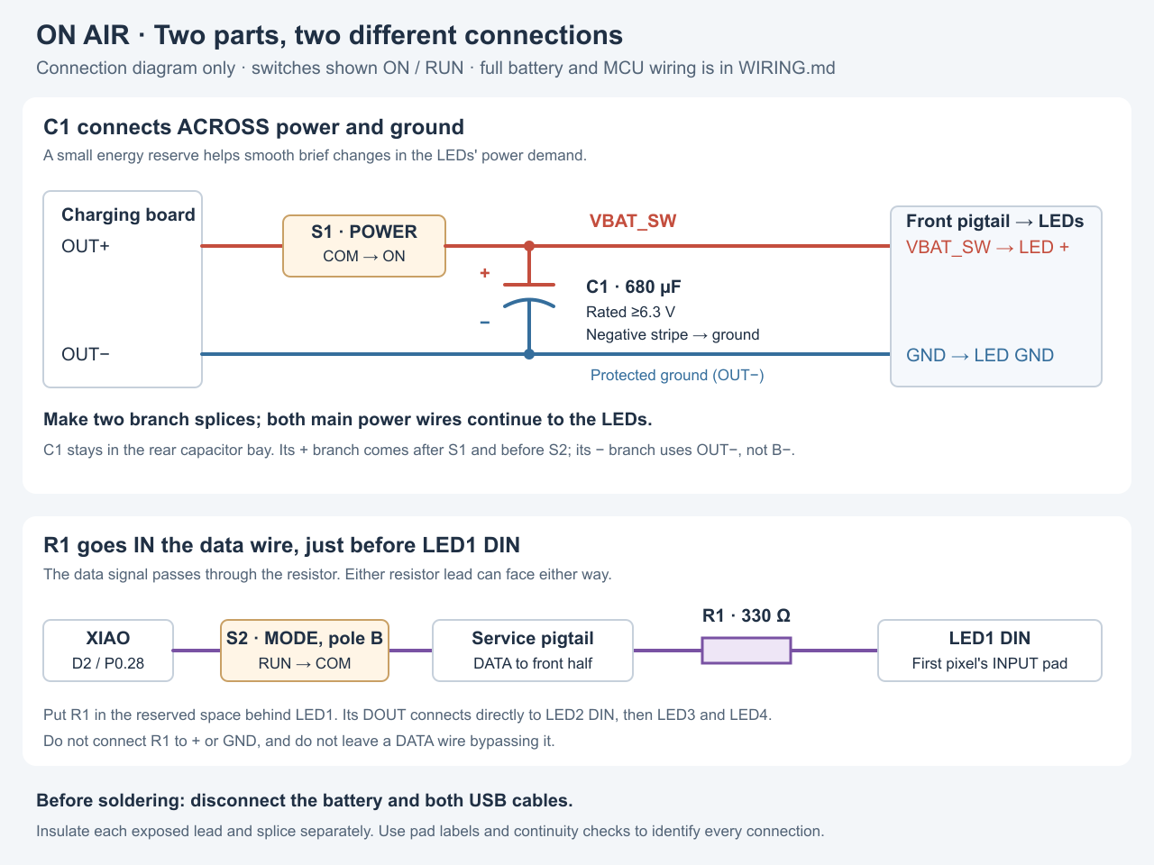
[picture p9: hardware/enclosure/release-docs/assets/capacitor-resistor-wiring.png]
Capacitor across switched LED power and ground; resistor in the first pixel's data wire


[Open the scalable diagram](../reference/capacitor-resistor-wiring.svg). This is a connection diagram, not the parts' physical positions. It shows S1 and the data pole of S2 in their ON/RUN positions. The [complete wiring table](WIRING.md#exact-connections) includes the battery, XIAO power and both switch poles.

| Part lead | Solder it to | Meaning |
| --- | --- | --- |
| C1 **positive (+)** | The **VBAT_SW** splice joining S1 POWER's ON terminal to the front pigtail's LED-power wire | Switched power, before the small S2 MODE switch |
| C1 **negative (−)** | The protected-ground splice joining charger **OUT−** to the front pigtail's GND wire and XIAO GND | The common ground return |
| Either R1 lead | The **front half of the pigtail's DATA wire**, which comes from S2 pole B common when connected | Signal arriving from the microcontroller through MODE |
| Other R1 lead | **LED1 DIN** (or a very short insulated lead to DIN) | Signal entering the first pixel |

The capacitor goes **across two wires**: one lead to power, the other to ground. Each of those wires still continues to the LEDs. Do not cut the power wire and put the capacitor end-to-end in it.

The resistor goes **end-to-end in one wire**: DATA must pass through R1 to reach LED1 DIN. Do not connect either R1 lead to power or ground, and do not leave a second wire bypassing it. R1 works either way around. Add it only before LED1; keep the three subsequent DOUT-to-DIN links direct.

## Solder C1 into the power harness

1. Disconnect the battery and both USB cables. Set POWER to OFF and MODE to PROGRAM. If the capacitor has been powered, check that it has discharged before handling its leads; do not short them together with a tool.
2. Identify C1's polarity **before clipping its leads**. On the usual radial aluminum electrolytic, the stripe marked **−** identifies the negative lead, and the untouched longer lead is positive. Verify the markings on your actual part; lead length cannot identify polarity after trimming. Reversing an electrolytic can damage it. [Adafruit's capacitor polarity example](https://learn.adafruit.com/adafruit-neopixel-uberguide/powering-neopixels).
3. Make two short insulated branch leads for C1. Slide heat-shrink tubing onto each before soldering. Solder one to C1 + and the other to C1 −, then sleeve each exposed lead and joint separately so they cannot touch.
4. Join C1's positive branch to **VBAT_SW**, the same splice that feeds the front LED-power pigtail. Join its negative branch to **charger OUT− / protected ground**. Insulate these splices separately too. Use OUT−, not B−: bridging those charger terminals externally would bypass the board's protection.
5. Keep both branches short with enough slack to install the part without pulling its leads. Lay C1 in the existing **right lower capacitor bay** and secure its insulated body. The selected body must be no larger than **8 mm diameter × 11.5 mm long**. Keep its leads clear of the pouch, screw pockets and guide keeper; do not cover its pressure-relief vent with adhesive.

C1 remains on the **rear housing side** of the service disconnect. Its power branch comes directly from S1's switched rail; it does not pass through either pole of the tiny DPDT. The front LED power and ground wires stay continuous. This is a bulk capacitor for the harness; the modules retain their local SMD capacitors.

## Solder R1 into the front DATA lead

1. Identify LED1 by its **DIN/DI** label or the arrow pointing into that module. In this enclosure LED1 is the lower-left module when viewed from the front; use its actual pad labels to distinguish DIN from DOUT. [Adafruit's input-pad guidance](https://learn.adafruit.com/adafruit-neopixel-uberguide/basic-connections).
2. Check the loose resistor with the meter's resistance setting: it should read about **330 Ω**, allowing for its marked tolerance. For a common four-band part the code is orange–orange–brown, followed by its tolerance band. Use the meter if the bands are unclear.
3. Leave the front pigtail's power and ground wires intact. Terminate its **DATA** wire at one R1 lead; solder the other R1 lead to a short insulated wire ending at **LED1 DIN**. Keep R1 close to DIN, in the reserved space behind that module.
4. Insulate both resistor joints, then sleeve the whole resistor assembly as needed. Keep its finished size within **12 mm long × 3.2 mm diameter**. Secure the sleeve so it cannot pull on the pixel pad or obstruct the acrylic edge. Leave enough service slack to remove the front.

## Check before insulating the final splices and closing

- With R1 disconnected from the electronics, measure about 330 Ω from its incoming DATA lead to its outgoing DIN lead. A continuity beeper may stay silent at this resistance; use the ohms setting. Do not expect an exact reading through the assembled electronics.
- Trace C1 **+ to VBAT_SW** and C1 **− to OUT−** visually and with continuity checks on their individual wires. The plus and minus leads must not touch. A resistance check across the power rails can change while the meter charges the capacitor; a sustained near-zero reading needs investigation.
- Confirm R1 has no bypass, C1 is not in series with power, and the LED-power branch avoids S2. Insulate all remaining joints before reconnecting power.
- Keep POWER off and MODE in PROGRAM before connecting either USB; use only one USB port. Follow the full [mode table and commissioning procedure](WIRING.md#everyday-modes). These two parts do not replace the manual USB isolation procedure or the remaining external-NeoPixel firmware work.

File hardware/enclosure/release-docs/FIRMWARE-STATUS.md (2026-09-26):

# Firmware included with the manufacturing release

Enclosure revision **2.13** and firmware version **0.1.2** are separate version numbers. The current committed firmware source is included under `firmware/`; its exact commit is recorded in the release manifest. This packaging task does not change, build or flash firmware.

The existing firmware uses `src/status_output_pwm.c` and the board's `pwm_red`, `pwm_green` and `pwm_blue` aliases. It operates the **onboard RGB LEDs**, including the XIAO indicator visible through the new front guide. It does **not** configure or drive the four external NeoPixels on D2/P0.28.

The two-switch wiring guide reserves D2/P0.28 for the external data chain. To finish the illuminated display, the receiver still needs an external addressable-pixel driver configured for the actual four modules, their protocol/color order, the data pin and a conservative brightness ceiling. Startup, low-cell-voltage behavior and current must then be tested with the physical harness. The PWM brightness setting alone does not add an addressable LED output.

The source ZIP contains the repository's firmware build, flashing, pairing and diagnostics guides, plus its pinned dependency manifest. The Zephyr toolchain/dependencies and generated local build directories are not included. No ambiguous local UF2 or ELF was selected as a release binary.

For USB work on the assembled sign, the enclosure's operating procedure takes precedence over the generic source flashing instructions: **POWER off, MODE in PROGRAM, only the XIAO USB plugged in**. Double-tap the front reset to use the factory bootloader as described in the source's `docs/FLASHING.md`. MODE selects electrical isolation; it does not enter the bootloader automatically. Unplug USB before selecting RUN and turning POWER on.

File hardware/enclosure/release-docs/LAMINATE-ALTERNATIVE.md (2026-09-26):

# Optional laminate backing — omit for the selected printed insert

These files are retained as an alternative, separate from the production print set:

- `03-optional-laminate-FRONT-engrave-and-cut.svg`: front-facing, unmirrored artwork for confirmed laser-safe black-over-white laminate, nominal **1.6 mm** thick.
- `81-laminate-front-spacer.stl` and `82-laminate-rear-shim.stl`: both spacer rings required for that alternative stack. Print black at 0.10 mm layers and 100% infill, in the supplied orientation.
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

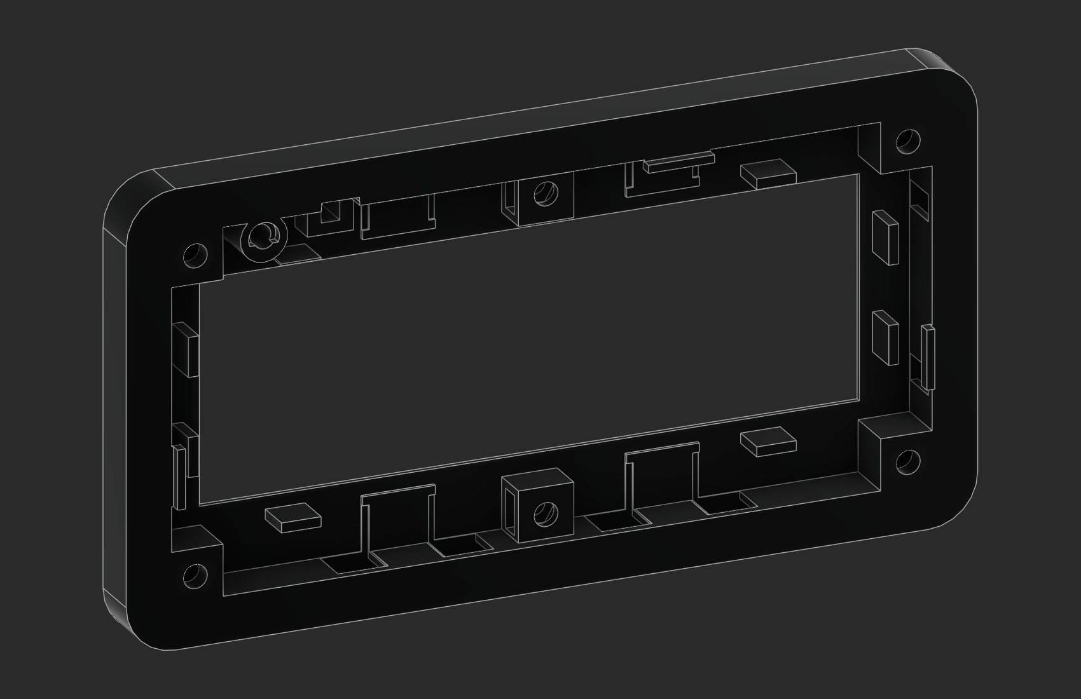
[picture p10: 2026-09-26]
release/little-on-air-enclosure-v2.16/reference/views/v214-inside.png

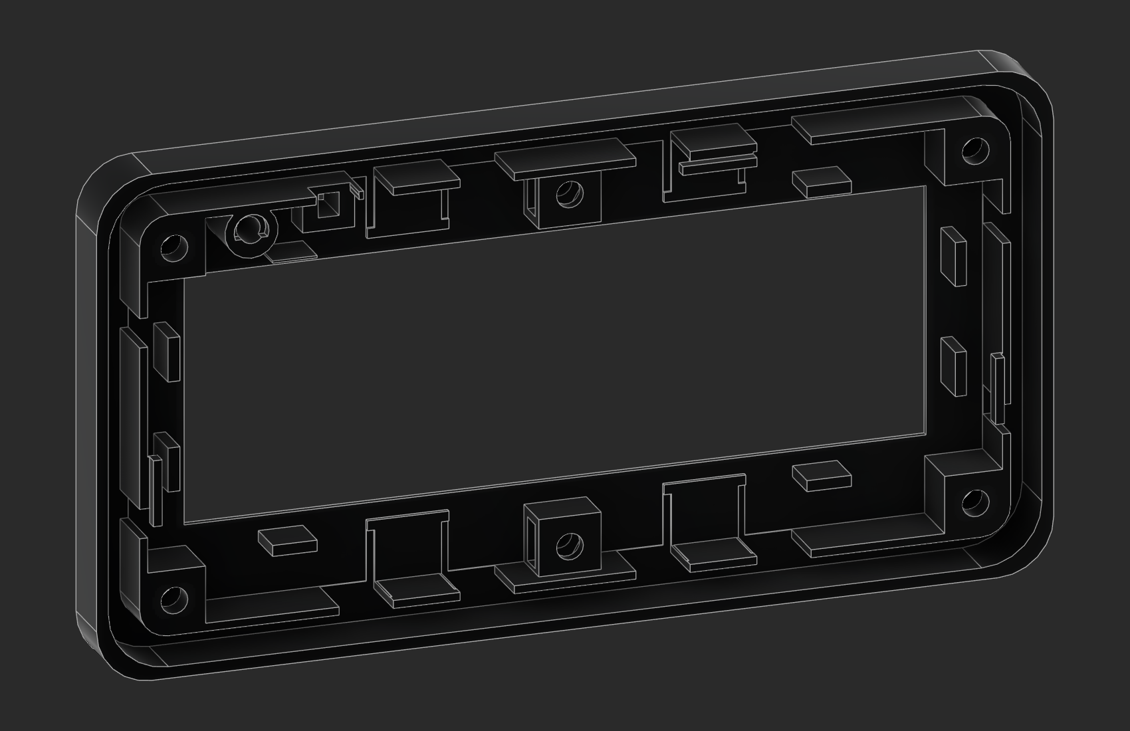
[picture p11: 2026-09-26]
release/little-on-air-enclosure-v2.16/reference/views/v215-inside.png

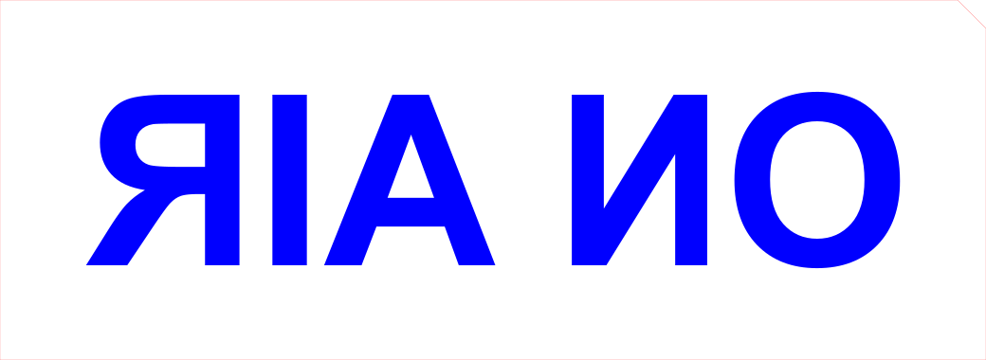
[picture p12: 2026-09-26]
release/little-on-air-enclosure-v2.16/reference/previews/02-acrylic-REAR-engrave-and-cut.png

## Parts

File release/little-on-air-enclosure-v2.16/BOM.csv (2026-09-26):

Ref | Quantity | Item | Specification | Location | Status
P01 | 1 | Front frame with open-backed LED wire channels | Black PLA+; supplied orientation | stl/01-front-optical-bezel.stl; plate 1 | Make
P03 | 1 | Registered display backing | Black and white PLA+; supplied orientation | stl/03-registered-graphic-backing.stl; plate 2 | Make
P04 | 1 | Optical retainer | Black PLA+; supplied orientation | stl/04-optical-retainer.stl; plate 1 | Make
P05 | 1 | Rear housing with shallow LED-lead reliefs | Black PLA+; supplied orientation | stl/05-rear-electronics-housing.stl; plate 1 | Make
P06 | 1 | Reinforced electronics yoke with open wire grooves | Black PLA+; supplied orientation | stl/06-electronics-retaining-yoke.stl; plate 1 | Make
P07 | 1 | Front reset button | Black PLA+; supplied orientation | stl/07-front-guided-reset-button.stl; plate 1 | Make
P08 | 1 | Captive front RGB guide | Transparent PETG; supplied orientation | stl/08-captive-front-rgb-guide.stl; plate 3 | Make
P09 | 2 | Rear charger guide | Transparent PETG; supplied orientation | stl/09-charger-light-guide.stl; plate 3 | Make
P11 | 1 | Rear guide keeper | Black PLA+; supplied orientation | stl/11-rear-light-guide-keeper.stl; plate 1 | Make
AC1 | 1 | Clear PMMA panel | 104 x 38 nominal; measured 3.00-3.45 thick | Rear-engrave shared SVG | Owned stock
BT1 | 1 | Single-cell LiPo | 1000 mAh; 52 x 21 x 10; verify protection and cell charge rating | Battery cradle | Owned
MCU1 | 1 | Seeed XIAO nRF52840 | PCB21 x17.8 x1.2; USB8.97 x3.17 centered across width; overhang1.75; reset1.8 from PCB back; no headers | Flat, components face front; open pad rows; front-frame reset and RGB hole | Owned
CH1 | 1 | HiLetgo TP4056 USB-C with protection | Measured PCB 28.1 x17.5; USB 8.85 x3.1; overhang1.25; PCB thickness provisional1.0 | Flat, components face back; both rear LED holes retained | Owned
S2 | 1 | WMYCONGCONG DPDT B07F7PNDGM | Body9.1 x3.72 x3.36; six legs0.7 wide x3.25 projection; 1.85 clear gaps; actuator1.5 square x1.87; travel2.4; no flange | Exposed fingernail slider; retained by yoke; open terminal channels | Owned; confirm MCU branch current
S1 | 1 | Tnuocke SPDT SS12F15-G5 B099N3HFPG | Measured body10.6 x6 x5.05; flange19.73; terminals2.6; actuator2.95 square x5 high; travel2.85 | Integrated POWER nest; retained by yoke | Owned; measured body fit retained
LED1-4 | 4 | Adafruit side-light RGB NeoPixel segments | Measured nominal 8 x 8 x 2; verify cut outline; keep SMD capacitors | Original front alignment floors; small hot-glue anchors; emitter inward | Owned; keep existing SMD components
C1 | 1 | 680 uF aluminium electrolytic | >=6.3 V; body <=8 diameter x11.5 long; polarity marked | Rear right lower bay; + to VBAT_SW after S1, - to charger OUT-; two branch splices; see capacitor/resistor guide | Selected addition; body fit check
R1 | 1 | 330 ohm data series resistor | 330 ohm; insulated body <=12 long x3.2 diameter | H1 DATA -> R1 -> lower-right LED1 DIN; X70-82 Y5.2-8.4 depth18-21.2; see capacitor/resistor guide | Additional
J1 | 1 | User pigtail disconnects | Mated envelope <=13 x10 x7.5 reserved; verify pinout and actual bends | Left lower bay X4-17 Y14-24 depth12-19.5; accessible disconnect | User supplied
W1 | 3 m total | Flexible stranded 28 AWG wire | Insulated OD <=0.9; three colors; cut from routing list | Existing compact rear leads; exclude revised H1-H4; keep clear of new LED routes | Additional
W2 | 1 m total | Flexible stranded 30 AWG wire | Insulated OD <=0.8; signal/XIAO low-current branch | Paired power fanout and signal leads; OD <=0.8 for pairs | Additional
H1 | 9 | M3 x8 button-head screws | Head <=5.7 diameter x1.65 high; 8 mm under-head length; no washers | 4 closure; 2 optical retainer; 2 electronics yoke; 1 rear guide keeper | Hardware
H4 | 9 | M3 nuts | Standard 5.5 across flats x2.4 thick | Captive side-entry pockets | Hardware
I1 | As needed | Insulating adhesive and compressible shims | Measured stack; no conductive foam; do not cover ICs | PCBs optical retainer battery | Assembly
I2 | As needed | Heat shrink / insulating sleeves | DPDT finished OD <=1.2; no bare joints | Terminations | Assembly
T1 | 1 | Narrow nonconductive straps | 2.5 wide nonconductive strap; leave loose around pouch | Battery through two integral lugs | Assembly
A1 | As needed | Removable wall strips | Sized for actual assembled mass | Flat rear | Assembly
R_CHG | Only if required | Charger current-programming resistor replacement | Select for confirmed charger IC and battery permitted charge current; verify measured result | Existing resistor pads on charger; no new carrier or enclosure bay | Conditional; not an unconditional extra part
W_LED | Cut to fit | Flexible stranded 22 or 24 AWG LED interconnect wire | Insulation OD <=1.8 mm; separate wires; prefer flexible 24 AWG | Rearward H1-H4; open yoke grooves; lay before clamping; dry-fit actual pad exits | User owned; measure actual insulation
A_LED | Small quantity | Hot glue | Small corner/back anchors; no glue under optical datum or on emitter/pads | LED modules on original floors; small insulation anchors in accessible areas away from seats | User selected mounting method

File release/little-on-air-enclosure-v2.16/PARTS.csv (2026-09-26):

Part | Description | Quantity | Material | Bambu plate | Geometry provenance | Release file
01 | Front frame with open-backed LED wire channels | 1 | Black PLA+ | 1 | v2.15 front-only roof removal | stl/01-front-optical-bezel.stl
03 | Registered display backing | 1 | Black and white PLA+ | 2 | v2.8 unchanged | stl/03-registered-graphic-backing.stl
04 | Optical retainer | 1 | Black PLA+ | 1 | v2.8 unchanged | stl/04-optical-retainer.stl
05 | Rear housing with shallow LED-lead reliefs | 1 | Black PLA+ | 1 | v2.16 rearward wiring | stl/05-rear-electronics-housing.stl
06 | Reinforced electronics yoke with open wire grooves | 1 | Black PLA+ | 1 | v2.16 rearward wiring; one charger contact relocated | stl/06-electronics-retaining-yoke.stl
07 | Front reset button | 1 | Black PLA+ | 1 | v2.8 unchanged | stl/07-front-guided-reset-button.stl
08 | Captive front RGB guide | 1 | Transparent PETG | 3 | v2.13 | stl/08-captive-front-rgb-guide.stl
09 | Rear charger guide | 2 | Transparent PETG | 3 | v2.13 release; identical pair | stl/09-charger-light-guide.stl
11 | Rear guide keeper | 1 | Black PLA+ | 1 | v2.13 | stl/11-rear-light-guide-keeper.stl
02 | Rear-engraved acrylic panel | 1 | Clear PMMA measured 3.00-3.45 mm | Laser | Shared artwork unchanged since v2.8 | laser/02-acrylic-REAR-engrave-and-cut.svg

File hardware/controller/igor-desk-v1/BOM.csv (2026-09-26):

Item | Quantity | Specification | Notes
Controller | 1 | Seeed Studio XIAO ESP32-S3 standard 21 x 17.8 mm | No Sense expansion board; USB-powered
BLE antenna | 1 | XIAO-compatible U.FL flexible antenna | Use antenna supplied with board; mount on upper plastic wall away from ballast
Display | 1 | Igor-compatible 0.96 inch SSD1306 128x64 I2C OLED | 27 x 27 mm PCB family; match original faceplate and 21.2 x 23 mm mounting-center pattern before buying
Encoder | 1 | KY-040 rotary encoder module with pushbutton | Use Igor-compatible shaft and supplied panel nut/washer; connect module to 3.3 V
Status LED | 1 | WS2812B RGB 5050 on 10 x 10 x 1.6 mm PCB | Centered emitter up to 1.6 mm tall; solder wires on rear; do not substitute a 12 mm Flora disc
Level shifter | 1 | SN74AHCT1G125 at 5 V on small breakout | TTL-compatible input; completed insulated assembly must fit 18 x 12 x 4 mm envelope
Pixel data resistor | 1 | 330 ohm 0.125 W or smaller | Between shifter output and pixel DIN
Input pulldown | 1 | 100 kilohm | Shifter A input to ground
Ceramic bypass capacitors | 2 | 100 nF | At shifter supply and pixel supply; onboard capacitor may fulfill pixel requirement
Bulk capacitor | 1 | 47 uF at least 10 V low profile | Across 5 V/GND near pixel feed; maximum diameter 6.3 mm and length 8.5 mm
Case screws | 4 | M3 x 8 mm 90-degree countersunk | Overall length including head; maximum head diameter 6.2 mm
Heat-set inserts | 4 | M3 nominal 4.2 mm OD x 4 mm long | 4.0 mm pilot; test actual insert fit on scrap first
Wheel weight segments | up to 16 | 5 g steel adhesive segments | Each at most 19 x 11.5 x 4 mm including tape; two layers provide 80 g
Rubber feet | 4 | Approximately 8 mm diameter x 1.2 mm | Adhere to bottom cover; clear screws
XIAO mounting tape | 1 piece | 0.3 mm thick electrically insulating double-sided tape | 13 x 17 mm maximum on center pedestal; USB insertion stop is printed
Insulation and wire | as needed | 28-30 AWG stranded insulated wire and heat shrink | No pin headers; insulate auxiliary board and capacitor leads
Anti-rattle pad | 1 | Thin closed-cell foam | Compress lightly over ballast; total weights/tape/pad no more than 10 mm
USB cable | 1 | USB-C data cable from computer | Case checked for plug overmould at most 12 mm wide x 7 mm high
Printed parts | 5 | Shell/faceplate/hat/cover/diffuser | See STL and Bambu projects

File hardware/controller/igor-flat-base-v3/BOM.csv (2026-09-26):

Item | Quantity | Specification | Notes
Controller | 1 | Seeed Studio XIAO ESP32-S3 standard 21 x 17.8 mm | No Sense expansion board; USB-powered
BLE antenna | 1 | XIAO-compatible U.FL flexible antenna | Use antenna supplied with board; mount on upper plastic wall away from ballast
Display | 1 | Igor-compatible 0.96 inch SSD1306 128x64 I2C OLED | 27 x 27 mm PCB family; match original faceplate and 21.2 x 23 mm mounting-center pattern before buying
Encoder | 1 | KY-040 rotary encoder module with pushbutton | Use Igor-compatible shaft and supplied panel nut/washer; connect module to 3.3 V
Status LED | 1 | 5 mm through-hole addressable NeoPixel; e.g. Adafruit 1938 | 6 mm maximum flange; 7 mm body and 7 mm trimmed lead envelope; front faceplate; verify RGB order and availability
Level shifter | 1 | SN74AHCT1G125 at 5 V on small breakout | TTL-compatible input; completed insulated assembly must fit 18 x 12 x 4 mm envelope
Pixel data resistor | 1 | 330 ohm 0.125 W or smaller | Between shifter output and pixel DIN
Input pulldown | 1 | 100 kilohm | Shifter A input to ground
Ceramic bypass capacitors | 2 | 100 nF | One at buffer supply; one across through-hole pixel power leads
Bulk capacitor | 1 | 47 uF at least 10 V low profile | Across 5 V/GND near pixel feed; maximum diameter 6.3 mm and length 8.5 mm
Wheel weight segments | 3 | 5 g steel adhesive segments | 19 x 11.5 x 4 mm maximum including adhesive; one flat-base well; 15 g total with 5 g segments
XIAO mounting tape | 1 piece | 0.3 mm thick electrically insulating double-sided tape | 13 x 17 mm maximum on center pad; pocket locates the PCB; socket centered at original USB position
Insulation and wire | as needed | 28-30 AWG stranded insulated wire and heat shrink | No pin headers; insulate auxiliary board and capacitor leads
USB cable | 1 | USB-C data cable from computer | Case checked for plug overmould at most 12 mm wide x 7 mm high
Printed parts | 3 main parts plus 2 original decorative inlays | Revised shell and LED faceplate; original hat and inlays | No extra covers or case fasteners; original hat can be reused

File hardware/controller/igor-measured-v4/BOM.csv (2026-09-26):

Item | Quantity | Specification | Notes
XIAO ESP32-S3 | 1 | Standard board without Sense expansion | Computer USB-C power; direct-soldered wires
Monochrome OLED | 1 | 27.6 x 27.9 x 1.25 mm PCB | User measured four-pin I2C module; retain header
Rotary push encoder | 1 | 19.25 x 26.4 x 1.5 mm PCB | User measured module with right-angle five-pin header
Mini NeoPixel strip segment | 1 | 17.6 x 5 x 1.4 mm | Adafruit mini strip; centered single LED; retain full segment
Adhesive wheel weight | 2 | 20 x 33.5 x 6.5 mm | Height includes supplied foam adhesive; mass not specified
Printed shell | 1 | 01-igor-measured-shell.stl | PLA
Printed faceplate | 1 | 02-igor-measured-faceplate.stl | PLA
Printed knob | 1 | 03-igor-measured-hat.stl | PLA; measured D socket
Printed small inlay | 1 | 04-igor-small-inlay-original.stl | Optional original decoration
Printed large inlay | 1 | 05-igor-large-inlay-original.stl | Optional original decoration
Printed diffuser | 1 | 06-front-diffuser-PETG.stl | Transparent PETG; 100 percent infill
Printed strip holder | 1 | 07-strip-cassette.stl | PLA
Printed XIAO carrier | 1 | 08-xiao-carrier.stl | PLA
AHCT level shifter | 1 | SN74AHCT1G125 or suitable small board | Insulated assembly at most 18 x 12 x 4 mm
Data resistor | 1 | 330 ohm | Near strip DIN
Input pulldown | 1 | 100 kohm | AHCT input to ground
Bypass capacitor | 2 | 100 nF | One at pixel and one at buffer; count existing fitted bypass if suitable
Bulk capacitor | 1 | 47 uF at least 10 V | Prototype allowance; body within diameter 6.3 x 8.5 mm; verify on bench
Wire and insulation | As needed | Thin flexible insulated hookup wire | Keep joints and strain relief outside LED channel
Mounting tape | As needed | Approximately 0.2 mm strip and 0.3 mm XIAO | Do not add foam under wheel weights
Hot glue or suitable adhesive | As needed | Small corner fillets | Keep clear of glass ribbon buttons and moving shaft
USB-C data cable | 1 | Computer connection | Check actual plug housing at rear opening

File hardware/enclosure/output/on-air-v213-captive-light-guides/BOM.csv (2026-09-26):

Part | Quantity | Material | Action
01 Front optical bezel | 1 | PLA PLA+ or PETG | Replace with deep RGB bearing and captive collar pocket
05 Rear electronics housing | 1 | PLA PLA+ or PETG | Replace with rear collar seats and keeper nut boss
08 Captive front RGB light guide | 1 | Clear PETG | New internal-collar design; do not reuse old front guide
09 Charger light guide | 2 | Clear PETG | Existing short guides may be reused if they fit freely
11 Rear light guide keeper | 1 | PLA PLA+ or PETG | New rigid keeper; support under open arm during printing
Additional M3x8 button-head screw | 1 | Steel | Same length as current case screws
Additional M3 hex nut | 1 | Steel | 5.5 mm across flats and about 2.4 mm thick

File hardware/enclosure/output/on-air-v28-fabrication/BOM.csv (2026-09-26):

Ref | Quantity | Item | Specification | Location | Status
P01-P07 | 6 | Printed parts 01 03 04 05 06 07 | PLA / calibrated PLA+ / PETG | Supplied STL and 3MF | Make
AC1 | 1 | Clear PMMA panel | 104 x 38 nominal; measured 3.00-3.45 thick | Rear-engrave shared SVG | Owned stock
BT1 | 1 | Single-cell LiPo | 1000 mAh; 52 x 21 x 10; verify protection and cell charge rating | Battery cradle | Owned
MCU1 | 1 | Seeed XIAO nRF52840 | PCB21 x17.8 x1.2; USB8.97 x3.17 centered across width; overhang1.75; reset1.8 from PCB back; no headers | Flat, components face front; open pad rows; front-frame reset and RGB hole | Owned
CH1 | 1 | HiLetgo TP4056 USB-C with protection | Measured PCB 28.1 x17.5; USB 8.85 x3.1; overhang1.25; PCB thickness provisional1.0 | Flat, components face back; both rear LED holes retained | Owned
S2 | 1 | WMYCONGCONG DPDT B07F7PNDGM | Body9.1 x3.72 x3.36; six legs0.7 wide x3.25 projection; 1.85 clear gaps; actuator1.5 square x1.87; travel2.4; no flange | 9.5 mm body-width pocket; .15 mm total retained depth clearance | Owned; confirm MCU branch current
S1 | 1 | Tnuocke SPDT SS12F15-G5 B099N3HFPG | Measured body10.6 x6 x5.05; flange19.73; terminals2.6; actuator2.95 square x5 high; travel2.85 | New integrated POWER nest; retained by yoke | Owned; successful body fit retained; combined sample99 first
LED1-4 | 4 | Adafruit side-light RGB NeoPixel segments | Measured nominal 8 x 8 x 2; verify cut outline; keep SMD capacitors | Front seats | Owned; fit check first
C1 | 1 | 680 uF aluminium electrolytic | >=6.3 V; body <=8 diameter x11.5 long; polarity marked | On its side in right lower bay; across VBAT_SW and protected ground | Selected addition; body fit check
R1 | 1 | 330 ohm data series resistor | 330 ohm; insulated body <=12 long x3.2 diameter | Behind LED1 in reserved inline assembly bay | Additional
J1 | 1 | User pigtail disconnects | Mated envelope <=13 x10 x7.5 reserved; verify pinout and actual bends | Left lower service bay | User supplied
W1 | 3 m total | Flexible stranded 28 AWG wire | Insulated OD <=0.9; three colors; cut from routing list | Dressed LED bundles and individual leads; routing length guide | Additional
W2 | 1 m total | Flexible stranded 30 AWG wire | Insulated OD <=0.8; signal/XIAO low-current branch | Paired power fanout and signal leads; OD <=0.8 for pairs | Additional
H1 | 8 | M3 x8 button-head screws | Head <=5.7 diameter x1.65 high; 8 mm under-head length; no washers | 4 closure, 2 optical retainer, 2 electronics yoke | Hardware
H4 | 8 | M3 nuts | Standard 5.5 across flats x2.4 thick | Captive side-entry pockets | Hardware
I1 | As needed | Insulating adhesive and compressible shims | Measured stack; no conductive foam; do not cover ICs | PCBs optical retainer battery | Assembly
I2 | As needed | Heat shrink / insulating sleeves | DPDT finished OD <=1.2; no bare joints | Terminations | Assembly
T1 | 1 | Narrow nonconductive straps | 2.5 wide nonconductive strap; leave loose around pouch | Battery through two integral lugs | Assembly
A1 | As needed | Removable wall strips | Sized for actual assembled mass | Flat rear | Assembly

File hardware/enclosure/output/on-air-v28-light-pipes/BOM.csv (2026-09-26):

Part | Quantity | Material | Notes
08 front RGB guide | 1 | Clear PETG | Choose 2.95 or 3.05 or 3.15 mm fit
09 charger guide | 2 | Clear PETG | Choose fit independently for each hole
Optional collar retention | As needed | Removable adhesive | Only if friction fit permits axial movement; keep clear of optics and electronics

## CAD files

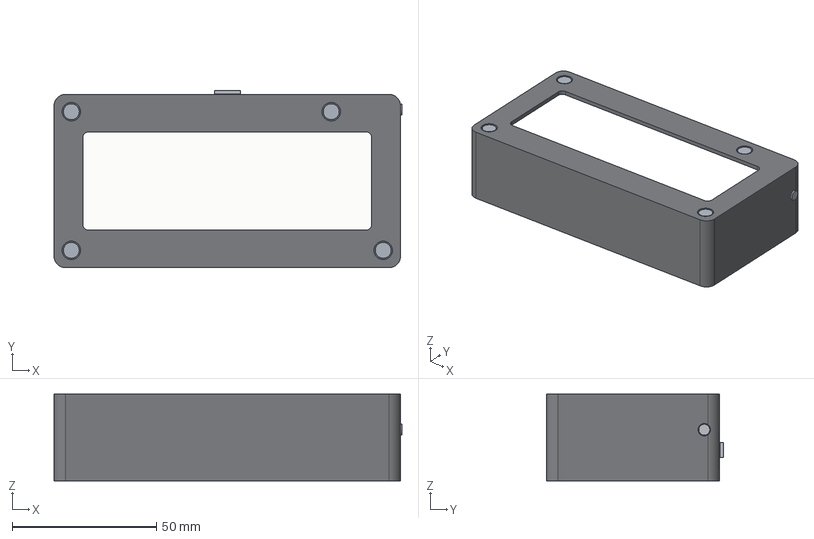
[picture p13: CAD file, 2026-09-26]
hardware/enclosure/output/little-on-air-assembly.step
120.5 x 61.4 x 30.0 mm
01 Body and front frame
02 Engraved acrylic
03 Black and white backing
10 Wall back plate
04 Optical and electronics tray
05 Charger keeper
06 XIAO keeper
09 Switch keeper
07 Captive reset plunger
08 Captive power slider
REF Battery 52x21x10
REF TP4056 charger
REF XIAO nRF52840
REF DPDT switch and leads
REF Four side emitting LEDs
REF M3 screws and nuts

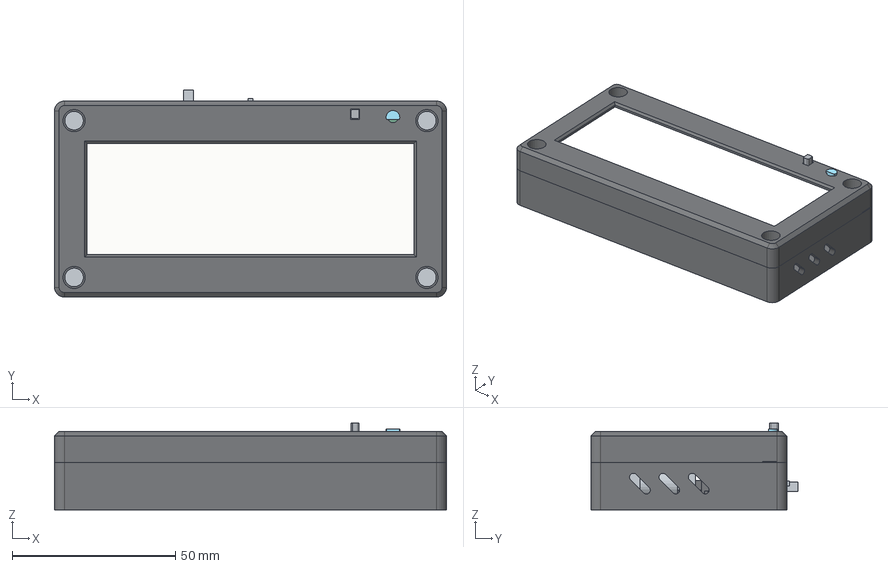
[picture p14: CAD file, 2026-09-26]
hardware/enclosure/output/on-air-v210-beveled-front/cad/little-on-air-v210-assembly.step
120.0 x 63.4 x 26.5 mm
01 Front optical bezel
02 Clear acrylic
03 Registered graphic backing
04 Optical retainer
REF Four LEDs
REF Charger
REF SPDT power switch
REF SPDT moving lever
REF DPDT
REF DPDT moving actuator
REF XIAO
05 Rear electronics housing
06 Electronics retaining yoke
07 Front guided reset button
REF Battery
REF Capacitor
REF M3 screws
REF M3 nuts
08 Front RGB light guide
09 Upper charger light guide
10 Lower charger light guide

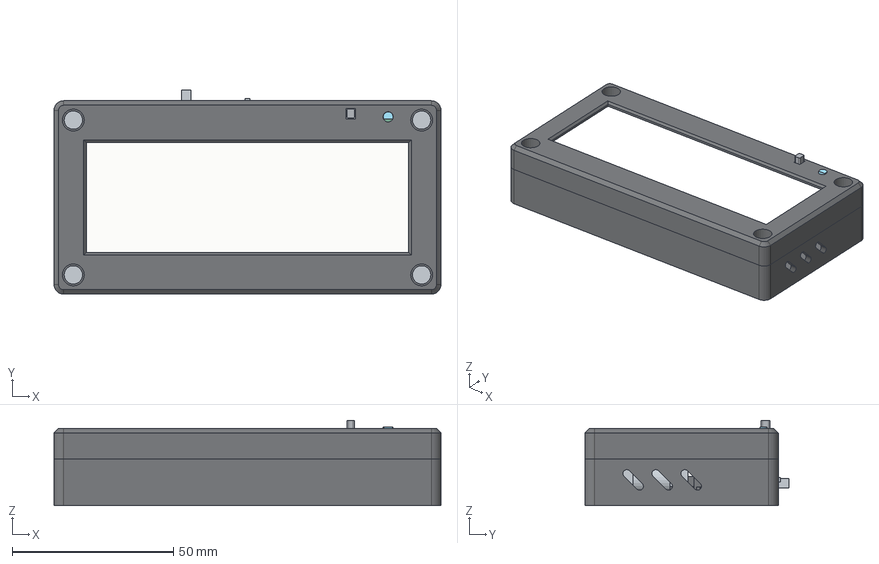
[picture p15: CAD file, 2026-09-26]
hardware/enclosure/output/on-air-v213-captive-light-guides/cad/little-on-air-v213-assembly.step
120.0 x 63.4 x 26.5 mm
01 Front optical bezel
02 Clear acrylic
03 Registered graphic backing
04 Optical retainer
REF Four LEDs
REF Charger
REF SPDT power switch
REF SPDT moving lever
REF DPDT
REF DPDT moving actuator
REF XIAO
05 Rear electronics housing
06 Electronics retaining yoke
07 Front guided reset button
REF Battery
REF Capacitor
REF M3 screws
REF M3 nuts
09 Upper charger light guide
10 Lower charger light guide
08 Front RGB light guide
REF Guide keeper hardware
11 Rear light guide keeper

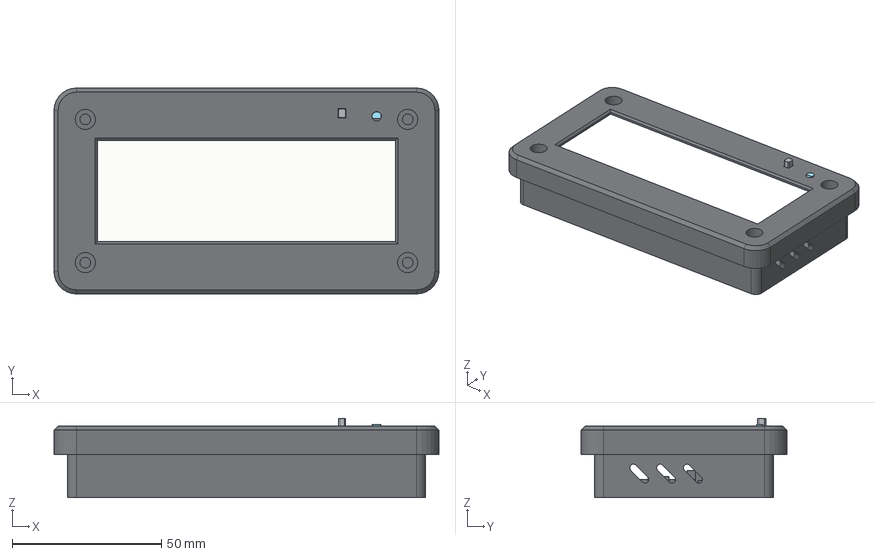
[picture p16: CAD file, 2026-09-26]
hardware/enclosure/output/v216/little-on-air-v216-assembly.step
129.0 x 69.0 x 26.5 mm
01 Front optical bezel
02 Clear acrylic
03 Registered graphic backing
04 Optical retainer
05 Rear electronics housing
06 Electronics retaining yoke
07 Front guided reset button
09 Upper charger light guide
10 Lower charger light guide
08 Front RGB light guide
11 Rear light guide keeper

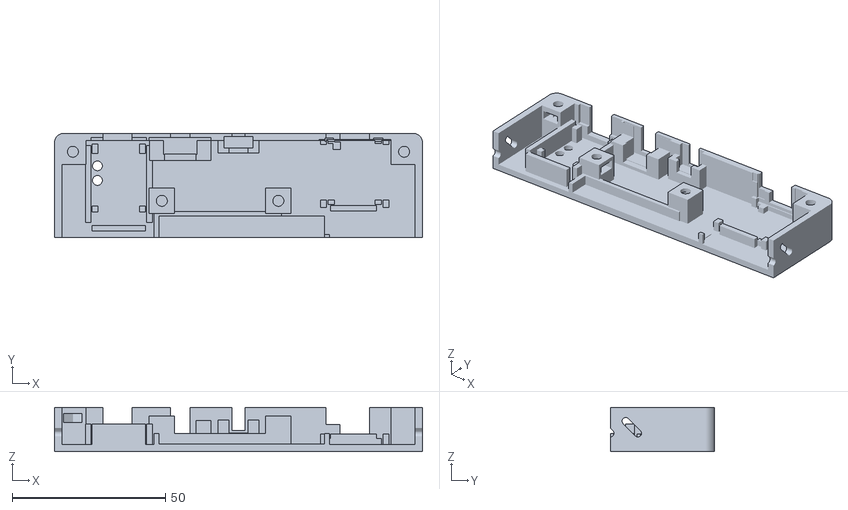
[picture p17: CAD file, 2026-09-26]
hardware/enclosure/output/on-air-v28-fabrication/fit-samples/99-upper-housing-complete-fit-section.stl
120.0 x 34.0 x 14.5

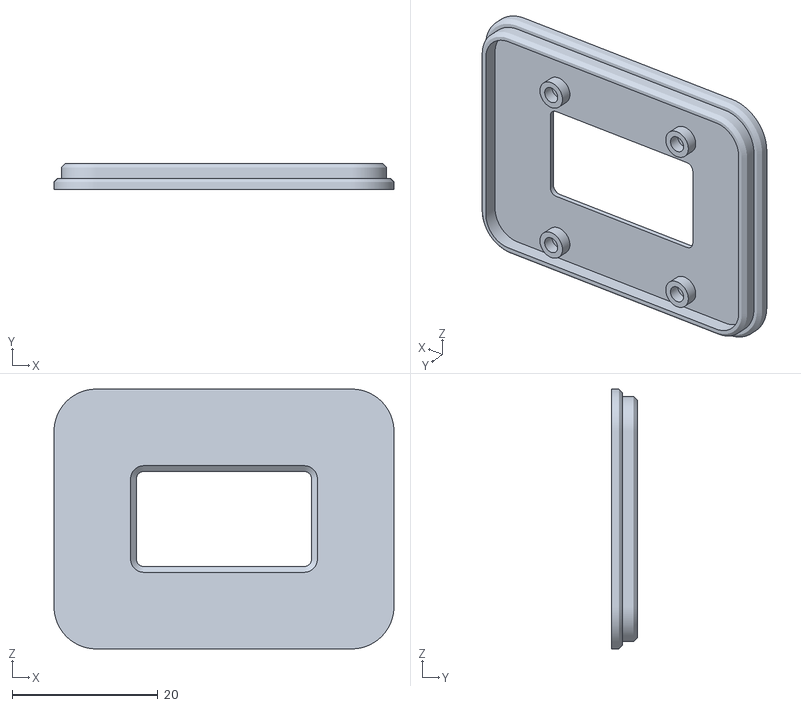
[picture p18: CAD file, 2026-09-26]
hardware/controller/igor-desk-v1/output/assembly-meshes/02-igor-faceplate.stl
46.6 x 3.50 x 35.6

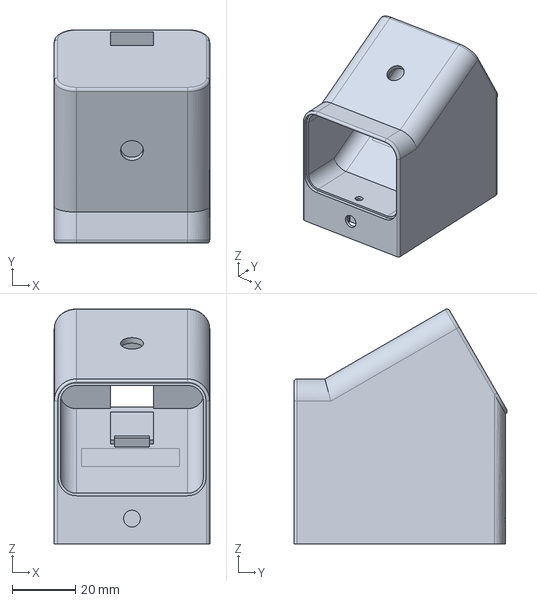
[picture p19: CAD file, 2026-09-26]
hardware/controller/igor-desk-v1/output/cad/01-weighted-shell.step
49.0 x 67.3 x 74.0 mm

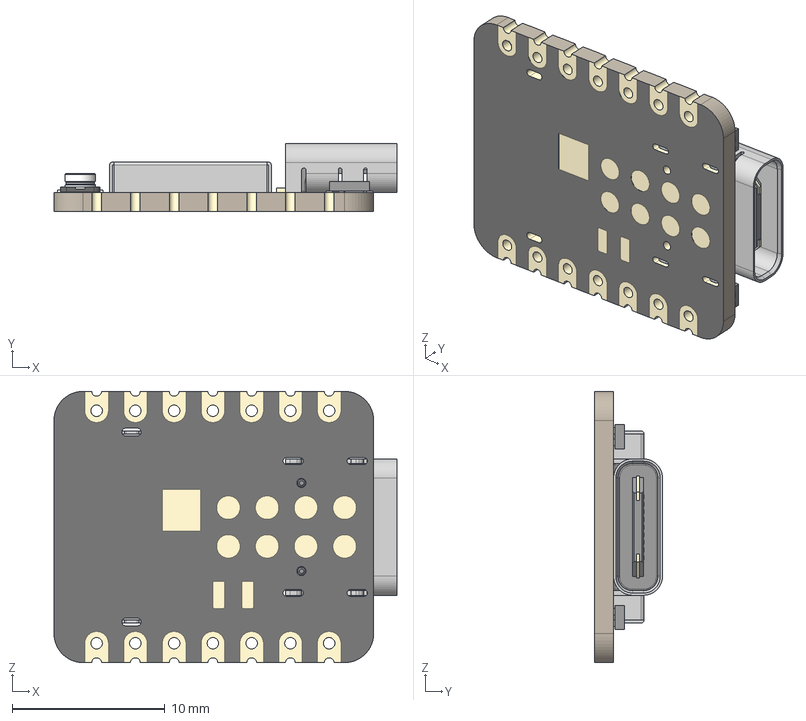
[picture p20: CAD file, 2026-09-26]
hardware/controller/igor-desk-v1/reference/xiao-esp32s3-seeed.step
22.5 x 4.46 x 17.8 mm
BOSS-EXTRUDE14_8_
BOSS-EXTRUDE7_4_
BOSS-EXTRUDE7_3_
BOSS-EXTRUDE14_4_
BOSS-EXTRUDE14_2_
BOSS-EXTRUDE14_11_
BOSS-EXTRUDE7_7_
BOSS-EXTRUDE14_9_
BOSS-EXTRUDE14_3_
BOSS-EXTRUDE14_7_
MIRROR2
BOSS-EXTRUDE14_5_
BOSS-EXTRUDE14_12_
BOSS-EXTRUDE7_8_
BOSS-EXTRUDE7_1_
BOSS-EXTRUDE14_10_
BOSS-EXTRUDE7_9_
BOSS-EXTRUDE14_6_
BOSS-EXTRUDE14_1_
BOSS-EXTRUDE7_6_
BOSS-EXTRUDE7_2_
CUT-EXTRUDE5
BOSS-EXTRUDE7_5_
Shield
Pins x 2
U.FL-R-SMT-1_10_ v1

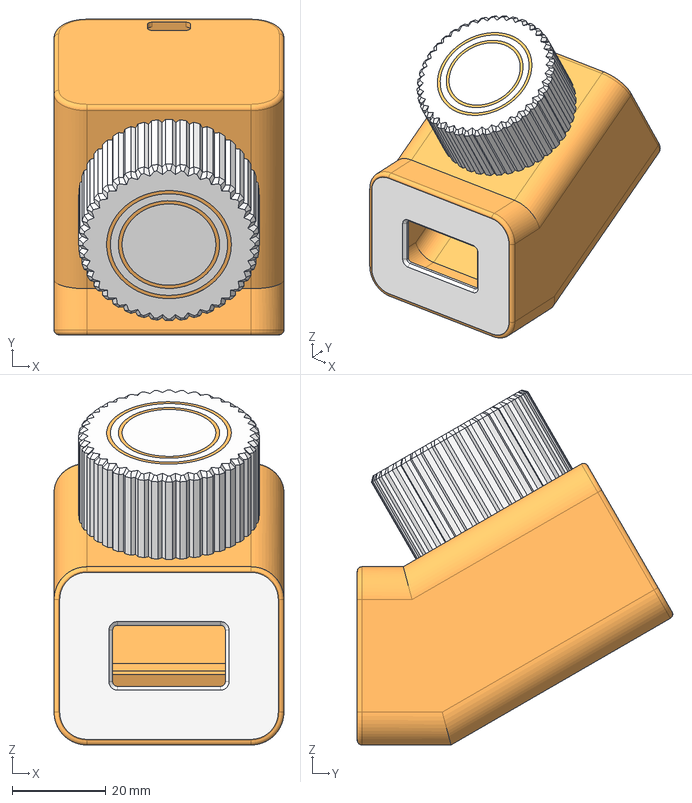
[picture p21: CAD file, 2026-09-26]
hardware/controller/igor-desk-v1/upstream/igor-v1.step
49.0 x 67.3 x 75.7 mm
small groove
big groove
Faceplate
classic

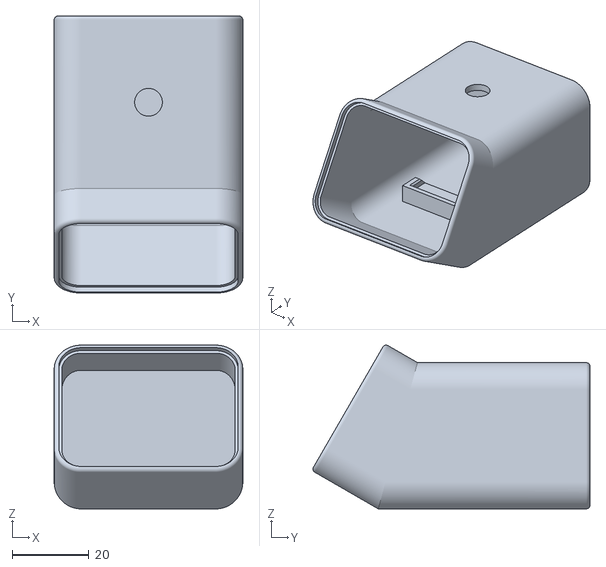
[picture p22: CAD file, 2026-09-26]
hardware/controller/igor-flat-base-v3/output/assembly-meshes/original-shell-reference.stl
49.0 x 72.0 x 42.5

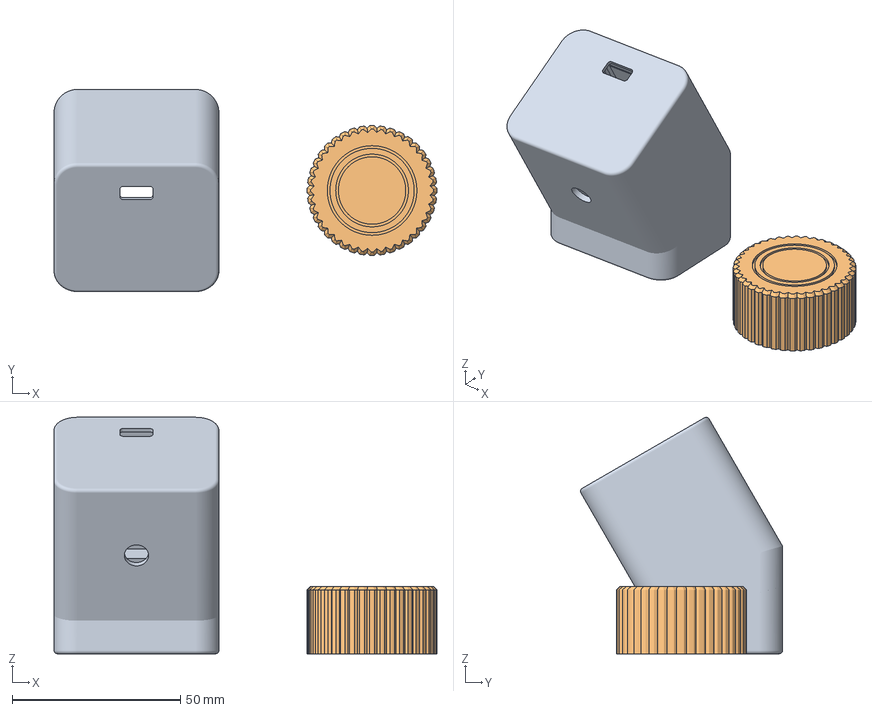
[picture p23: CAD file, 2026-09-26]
hardware/controller/igor-flat-base-v3/output/bambu-studio/igor-flat-base-v3-X1C-PLA-shell-hat.3mf
113.8 x 60.1 x 70.3 mm
01-igor-flat-base-shell.stl
03-igor-hat-original.stl

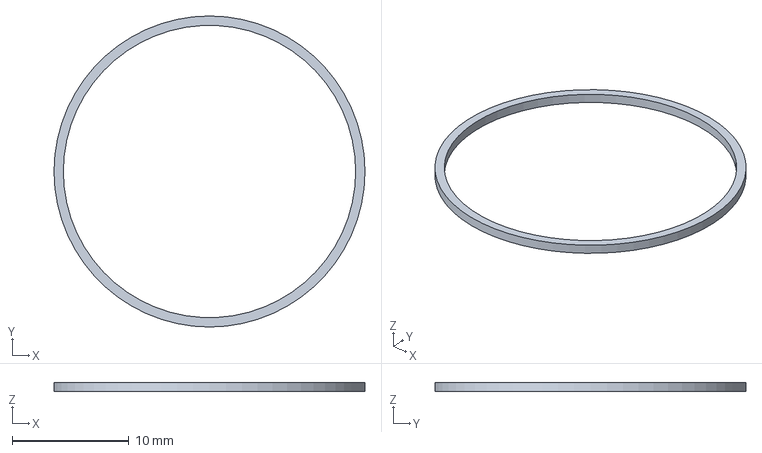
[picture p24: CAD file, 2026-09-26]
hardware/controller/igor-flat-base-v3/output/cad/05-igor-large-inlay-original.step
26.6 x 26.6 x 0.8 mm

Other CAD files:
hardware/enclosure/output/on-air-v211-clean-top-front/cad/little-on-air-v211-assembly.step
hardware/enclosure/output/on-air-v212-clean-perimeter-front/cad/little-on-air-v212-assembly.step
hardware/enclosure/output/on-air-v28-fabrication/cad/little-on-air-v28-assembly.step
hardware/controller/igor-desk-v1/output/bambu-studio/igor-desk-v1-X1C-PLA-faceplate.3mf
hardware/archive/controller/igor-desk-v1/output/assembly-meshes/01-weighted-shell.stl
hardware/archive/controller/igor-desk-v1/output/assembly-meshes/03-igor-hat.stl
hardware/archive/controller/igor-desk-v1/output/assembly-meshes/04-ballast-cover.stl
hardware/archive/controller/igor-desk-v1/output/assembly-meshes/05-led-diffuser.stl
hardware/archive/controller/igor-desk-v1/output/assembly-meshes/ballast-envelopes.stl
hardware/archive/controller/igor-desk-v1/output/assembly-meshes/pixel-envelope.stl
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

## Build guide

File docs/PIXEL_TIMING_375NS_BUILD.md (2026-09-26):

# Receiver 375 ns timing comparison

> Historical bench record: commands, paths and build variants below describe
> the recorded revision. Use the [current developer guide](../CONTRIBUTING.md)
> for today's build/flash commands. See [firmware history](HISTORY.md) for the
> retired source revision. Observations and image hashes below are retained.

This is a historical bench record. The old build trees were removed during
workspace cleanup; retained firmware snapshots, logs and simulation evidence
are listed in the [workspace guide](WORKSPACE.md#preserved-local-work).
Build commands below use the consolidated `build/` directory.

Prepared 2026-09-24 for the XIAO nRF52840 receiver's four front pixels.
This separate candidate changes the zero pulse width. It was flashed on
2026-09-25 after the user's wiring work. The scoped physical checks below passed;
the first pixel no longer showed the reported unwanted green in those checks.
The ESP32-S3 controller needs no update.

## Timing change

| Nominal timing | Earlier padded build | This comparison build |
| --- | --- | --- |
| SPI clock | 4 MHz | 8 MHz |
| SPI clocks per pixel bit | 5 | 10 |
| Zero HIGH / LOW | 250 / 1,000 ns | 375 / 875 ns |
| One HIGH / LOW | 750 / 500 ns | 750 / 500 ns |
| Pixel bit period | 1,250 ns | 1,250 ns |
| Leading / trailing continuous LOW | 300 / 300 us | 300 / 300 us |
| Clocked frame length | 360 bytes | 720 bytes |
| Clocked frame duration | 720 us | 720 us |

At 8 MHz, zero is `1110000000` and one is `1111110000`. The shared encoder
stores each symbol in a 16-bit integer so the leading bits are retained.
The original five-bit profile is still selectable. No runtime detection or
automatic timing changes are introduced.

The same SPIM2 peripheral clocks a single contiguous RAM buffer: 300 zero
bytes, 120 payload bytes, 300 zero bytes. The additional original 300 us
post-transfer wait remains. Compile-time checks enforce the selected SPI
bus's clock limit and DMA capacity, and match the encoder to the devicetree.
The actual bus supports 8 MHz and has a 16-bit DMA counter; 720 bytes fit in
one transfer. GRB order, four pixels, D2/P0.28, brightness, onboard indicator,
pairing, saved state and BLE commands are unchanged.

The upstream `worldsemi,ws2812-spi` driver only supports 3–8 bits per symbol.
This variant uses the application-owned `loa,padded-ws2812-spi` binding and
driver. It does not pass ten-bit symbols to the upstream driver or patch
Zephyr's source.

The nominal zero timing moves inside the older [WS2812B timing reference](https://cdn-shop.adafruit.com/datasheets/WS2812B.pdf).
It does not establish compatibility with every WS2812-compatible part.
The exact installed pixel model and its electrical behavior remain unknown.

## Reproduce the build

From a configured Zephyr workspace, replace the paths as needed:

```sh
west build -b xiao_ble/nrf52840 little-on-air/apps/receiver -d build/receiver-pixels-timing375 -- \
  -DEXTRA_CONF_FILE="pixels.conf;pixels-padded.conf;pixels-timing375.conf" \
  -DEXTRA_DTC_OVERLAY_FILE="/path/to/little-on-air/boards/xiao_ble_nrf52840_pixels.overlay;/path/to/little-on-air/boards/xiao_ble_nrf52840_pixels_timing375.overlay"
```

Local image: `build/receiver-pixels-timing375/zephyr/zephyr.uf2`.
Checksums and the validation record are stored alongside it in
`SHA256SUMS.txt` and `build-record.json`.

Build and host verification passed. The image uses 163,664 bytes of flash and
29,988 bytes of RAM. UF2 starts at `0x27000`, preserving the factory bootloader.
Candidate SHA-256:
`715533d41269dd5ee470e7927f0443ce59f2c09c5f74eae442ca52b9d7ffdc8b`.

The earlier images are preserved:

- Installed baseline: `build/receiver-pixels/zephyr/zephyr.uf2`.
- Padding-only candidate: `build/receiver-pixels-padded/zephyr/zephyr.uf2`.

Their original hashes were verified, and copies are also saved in the new
build directory as `comparison-installed.uf2` and `comparison-padding-only.uf2`.

## Encoding and waveform verification

On Linux/WSL with a C compiler:

```sh
python3 tools/simulate_pixels.py --profile timing375
```

The default generated-header path is under `build/receiver-pixels-timing375`.
Use `--devicetree-header PATH` for another build directory. Results go to
`build/pixel-simulation-timing375/simulation.json` unless `--output` overrides it.

The tool compiles the firmware's actual C encoder. It verifies the generated
firmware's Kconfig, devicetree, SPI clock limit and DMA capacity. It checks:

- All channel values at all four positions, mixed colors, diagnostic colors
  and deterministic random frames: 3,359 complete frames.
- Every expected HIGH and LOW interval, in GRB/MSB-first order, including
  the final bit before reset: 322,464 nominal pulse pairs.
- Bounds, rejected inputs, guard bytes, padding and input preservation.
- The separately identified injected-startup fault model and hypothetical
  DMA pauses in padding, bringing total waveform cases to 10,055.

All checks passed for both profiles. The five-bit encoder output also matched
the preserved pre-change host executable byte for byte over all 3,359 frames.
A separate negative test deliberately restored eight-bit symbol storage in
a temporary host source; the nominal waveform checker rejected the corrupted
output. That mutation is not included in the firmware. Its result is recorded
in `.local/bench/build-pixel-simulation-timing375/truncation-regression.json`.

The 255-byte DMA split is an extra hypothetical stress case, not this board's
actual transfer. For this 720-byte profile its boundaries are at bytes 255
and 510, both in continuous LOW padding; the payload spans bytes 300–419.

The injected one-microsecond first-HIGH stretch deliberately tests a proposed
failure mode. It is not evidence that the hardware produces that fault.
The unpadded comparison removes padding from the selected profile's bytes;
it does not execute the old firmware. The nominal timing checks above do not
inject a fault or assume an unwanted green result.

Passing these checks verifies digital encoding under an assumed ideal SPI
clock. It is not an MCU emulator, electrical simulation, oscilloscope capture,
or confirmation that the first pixel is fixed.

## Hardware results and further comparison

### Flash session — 2026-09-25

The user confirmed POWER OFF / MODE PROGRAM, XIAO USB only. Factory bootloader
0.6.1 identified the target as `Seeed_XIAO_nRF52840_Sense` on `E:`. The source
UF2 checksum matched the recorded candidate. A 1,908,736-byte `CURRENT.UF2`
backup was saved under `.local/archive/2026-09-26/tmp/receiver-flash-20260926T043752Z/` before copying.
The copy completed and the firmware drive disappeared. A subsequent BLE sync
through controller COM4 succeeded with the existing bond and saved Off
transaction `78b4dae0`. This confirms application operation, not optical output
or a byte-for-byte post-flash read-back.

### Battery-powered visual checks — passed

The user confirmed POWER ON / MODE RUN with both receiver USB ports unplugged.
Controller COM4 remained connected. All ten diagnostic/state/sync operations
received successful BLE confirmation, and the user reported:

| Check | Physical observation |
| --- | --- |
| All Off | All four front pixels dark |
| Pixel 1 Red | Pixel 1 red; other three dark |
| Pixel 1 Green, Blue, White | Each color correct; other three dark |
| Normal On Air | All four red |
| Power off 3 seconds, then on | All four returned to red |
| Normal Warn, Okay, Off | All four yellow, then green, then dark |

After the power cycle, read-only sync confirmed the same saved On Air transaction
`04cf0874`. The final state was restored to Off, transaction `fa49507c`.
Command logs, the prior firmware backup and the observation record are under
`.local/archive/2026-09-26/tmp/receiver-flash-20260926T043752Z/`. The pre-update backup's application bytes
matched the preserved installed baseline.

The reported green symptom did not recur in these tests. This session tested
the combined padding and 375 ns timing build on the rewired hardware; it did
not isolate which change resolved the symptom. Pixels 2–4 were not separately
tested in blue/white, and long-duration/battery-voltage-range tests remain open.

Follow the existing [PROGRAM/RUN power sequence](PAIRED_BENCH.md#connections).
Use an ordinary application UF2 update, preserving pairing and saved state.
If further cause isolation is needed, compare the earlier padded build with
this one to isolate the zero-pulse change.
For each pixel, observe Off, Red, Green, Blue and White with the other pixels
dark. Then test normal states and a power cycle. Record the actual observed
colors before deciding which firmware to keep.

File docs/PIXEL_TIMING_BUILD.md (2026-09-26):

# Receiver pixel timing test build

> Historical bench record: commands, paths and build variants below describe
> the recorded revision. Use the [current developer guide](../CONTRIBUTING.md)
> for today's build/flash commands. See [firmware history](HISTORY.md) for the
> retired source revision. Observations and image hashes below are retained.

This is a historical bench record. The old build trees were removed during
workspace cleanup; retained firmware snapshots, logs and simulation evidence
are listed in the [workspace guide](WORKSPACE.md#preserved-local-work).
Build commands below use the consolidated `build/` directory.

A separate [375 ns zero-pulse comparison build](PIXEL_TIMING_375NS_BUILD.md)
is now available. This page describes the earlier padding-only candidate,
whose image remains preserved for comparison.

Prepared 2026-09-24 for the XIAO nRF52840 receiver's four external GRB pixels.
This is a candidate fix for the first pixel showing unwanted green. It has not
yet been flashed or accepted on hardware. The ESP32-S3 controller needs no update.

## Change

The optional `pixels-padded.conf` replaces the default Zephyr WS2812 SPI driver
with a repository-owned driver. Every output uses one contiguous RAM buffer:

```text
300 microseconds LOW | 120 microseconds pixel data | 300 microseconds LOW
```

At 4 MHz this is 150 zero bytes, 60 encoded data bytes and 150 zero bytes.
The first and last transmitted bits are LOW. The original additional 300 us
post-transfer delay remains. Padding consists of raw zero bits, which hold the
wire LOW; an encoded black pixel would contain pulses and would not serve this
purpose. The existing GRB mapping, 250/750 ns high pulses, four-pixel count,
brightness limit, D2 data pin, onboard LED and BLE protocol are preserved.

The actual generated nRF52840 configuration has a 16-bit DMA counter. The full
360-byte frame fits in one transfer. A compile-time assertion checks that against
the selected SPI bus. Other assertions match the encoder constants to the
generated pixel configuration. No upstream Zephyr files are patched.

The motivation is a possible SPI first-bit preload: starting a transfer with
HIGH may lengthen the first WS2812 pulse. GRB puts the first pixel's green byte
first, so a zero becoming one there could introduce unwanted green. This is a
hypothesis, supported by similar [Nordic observations](https://devzone.nordicsemi.com/f/nordic-q-a/126078/ws2812-with-spi-on-nrf9160-disrupted-by-an-high-signal-before-data-on-the-spi-mosi/556785)
and a [Zephyr first-pixel report](https://github.com/zephyrproject-rtos/zephyr/issues/75965),
not a measurement of this receiver's waveform.

## Build

From a configured Zephyr workspace, substitute your repository path:

```sh
west build -b xiao_ble/nrf52840 little-on-air/apps/receiver -d build/receiver-pixels-padded -- \
  -DEXTRA_CONF_FILE="pixels.conf;pixels-padded.conf" \
  -DEXTRA_DTC_OVERLAY_FILE=/path/to/little-on-air/boards/xiao_ble_nrf52840_pixels.overlay
```

Local candidate image: `build/receiver-pixels-padded/zephyr/zephyr.uf2`.
Candidate SHA-256:
`494144f2415d9b36adc0d12e96015360f0f519aab6936112738dd224a9648840`.
The production receiver build passed: 163,664 bytes flash and 29,604 bytes RAM.
Inspection of the linked ELF confirmed the padded driver and shared encoder are
present and the default WS2812 SPI update function is absent.

The standard `pixels.conf` profile remains available as the comparison image.
The previously installed image is still `build/receiver-pixels/zephyr/zephyr.uf2`,
SHA-256 `a16bb6e2d27a27406f7b4217680f1cea51fbb18cf5831abe971fc81f9928c78e`.
Rebuilding that original profile produced the same checksum. A preserved copy is
also at `build/receiver-pixels-padded/comparison-receiver.uf2`.
Use the normal application-only UF2 update; no pairing/state erase is needed.

## Simulation

On Linux or WSL with a C compiler, from this repository:

```sh
python3 tools/simulate_pixels.py
```

By default this checks the generated header in `build/receiver-pixels-padded`.
Use `--devicetree-header PATH` for another build directory and `--output PATH`
for another report directory. The simulator compiles and runs the **same C frame
encoder linked into the firmware**, then independently interprets its emitted
pulses. It also verifies the actual generated SPI frequency, pixel count, color
order, symbols, reset time and DMA capacity.

Results: **3,359 frame vectors and 10,055 waveform checks passed**, plus C bounds,
null-input, output-canary and input-preservation checks. Cases include:

- Every channel value 0–255 at all four positions, 256 deterministic random
  frames, mixed colors, all-off, and each pixel/color diagnostic.
- First-bit preload of 0, 0.25, 0.5, 1, 5 and 20 microseconds.
- Reset thresholds of 50, 280 and 300 microseconds; preceding partial frames.
- The actual single-transfer layout, plus an extra hypothetical 255-byte split
  with 0, 10 and 500 microseconds of idle time. That split lands in trailing LOW.

In the specific model where a one-microsecond startup delay stretches the first
HIGH pulse into a one bit, a pixel-1 red request `(31, 0, 0)` decodes as
`(31, 128, 0)` without padding and correctly as `(31, 0, 0)` with padding.

Outputs are `build/pixel-simulation/simulation.json`, `pixel-1-red.spi.bin`, and
`all-off.spi.bin`. CI builds the receiver variant and runs the same simulation.

**Limits:** this is a digital pulse-width model, not a microcontroller emulator
or oscilloscope capture. It cannot verify voltage levels, signal integrity,
the unknown pixel IC's precise timing tolerance, or RGB versus RGBW hardware.
Passing it establishes the intended encoded signal, not a physical repair.

## Hardware acceptance when connected

Follow the existing [PROGRAM/RUN and power sequence](PAIRED_BENCH.md#connections).
Flash the candidate receiver UF2, preserving the bond. With receiver USB removed
and the sign in RUN, use the existing controller `pixel` commands to observe:

1. Pixel 1 Off, Red, Green, Blue, White; each must match, with pixels 2–4 dark.
2. The same sequence independently at positions 2, 3 and 4.
3. Normal Off / Warn / On Air / Okay, with all four matching.
4. A receiver power cycle and repeated updates to verify the first frame too.

Record actual observations before calling the green-pixel issue resolved.

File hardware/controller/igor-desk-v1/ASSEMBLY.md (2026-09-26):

# Print and assemble the Igor desk controller

## 1. Match the parts before the long print

Use the standard XIAO ESP32-S3, an Igor-compatible KY-040 and a **0.96 inch,
128 × 64 SSD1306 I2C module**. Igor's faceplate is preserved at its original size:
its window throat is 24 × 13 mm and its four mounting centers are spaced
21.2 × 23 mm. The compatible small OLED family has a roughly 27 × 27 mm PCB.
The controller IC name alone does not identify a mechanical fit.

First print the faceplate and try the actual OLED. Check that its glass clears
the posts, the active image is centered in the opening, and rear components
and wires do not bear on the glass. Use the original faceplate retention fit;
if necessary, small neutral-cure silicone dots at the PCB edges hold it in
place. Keep adhesive off the glass and connector pads. Check the hat on the
actual encoder shaft separately, without forcing the key.

Measure the chosen single-pixel carrier: **10 × 10 mm, 1.6 mm PCB thickness,
centered 5 × 5 mm emitter up to 1.6 mm tall**. Larger round NeoPixel boards need
a different carrier slot. Wires leave the back of this board; header pins or
a plug on the carrier will not fit.

For the example 80 g ballast, select sixteen steel 5 g adhesive segments, each
no larger than **19 × 11.5 × 4 mm including tape**. The pocket is a dimensional
specification, not a promise that every wheel-weight product fits. Shorter
segments work; clip-on weights are not the intended form.

## 2. Print

All STL coordinates are millimetres. Import at **100% scale** and preserve
their supplied orientation. Use a 0.4 mm nozzle and the actual filament's
temperature/flow settings. The included X1C profiles use the existing project
PLA+ and clear-PETG material presets.

| Project | Parts | Settings | Measured slicer estimate |
| --- | --- | --- | --- |
| PLA body | Shell, hat, bottom cover | 0.20 mm; 4 walls; 25% gyroid | 5 h 12 min / 97.25 g, including support |
| PLA faceplate | Faceplate | 0.20 mm; 4 walls; 25% gyroid | 19 min / 3.31 g |
| Clear PETG | Diffuser | 0.12 mm; 3 walls; 100% fill | 12 min / 0.42 g, including startup |

The **shell prints front down**, with normal snug supports enabled throughout
the part, including interior areas. Remove them through the open front and
the underside service opening. The ballast compartment and LED slot must be
fully cleared before assembly. Do not change to build-plate-only support:
the cavity can need support beginning on printed surfaces. Supports cannot
remain in the weight pocket or on the XIAO pedestal.

The faceplate prints front down, the hat with its shaft socket down, the cover
with its outside face down, and the diffuser with its small front end down.
These four parts use no automatic supports. The short overhang around the
diffuser's collar is intentional. Remove the brim without reducing the
collar. Try the clear lens before choosing a final brightness; printed clear
PETG will diffuse light and will not behave like polished optical plastic.

The plate layout and exact STL identities are recorded with the slicer
results. No job has been uploaded to a printer. Slicer success verifies toolpath
generation, not physical print quality or component fit.

## 3. Prepare the shell and cover

1. Remove all support and brim. Check the faceplate seam, encoder hole, USB
   opening, board pedestal, LED slot, wire passage and all four screw holes.
2. Test the bottom cover dry. It has **0.3 mm clearance per side**, seats on
   its outer ledge, and is flush with the base. Its small inner tongue belongs
   at the **front**, below the LED board. It is not a snap fit.
3. Install four **M3 × 4 mm heat-set inserts, nominal 4.2 mm outside diameter**,
   into the four 4.0 mm pilot holes from below. Test the insert/material
   combination on scrap first. Set the insert mouths flush with the internal
   cover-bearing surface, not the outer bottom face. Allow them to cool fully.
4. Use four **M3 × 8 mm countersunk screws**, length measured including the
   head. The 90° countersinks accept heads up to 6.2 mm. Do not use a longer
   screw to compensate for an incorrectly seated insert.

## 4. Bench-wire the electronics

Follow [WIRING.md](WIRING.md). Keep USB unplugged while soldering. Direct-solder
the XIAO and modules without headers, and insulate exposed joints. Include
the 5 V AHCT buffer, 330 Ω data resistor and decoupling capacitors.

The display and encoder use **3.3 V**, while the pixel and buffer use **USB 5 V**.
Preserve common ground. The pixel's `DIN` is the input; its `DOUT` is unused.
Do not load the old nRF52840 UF2 onto the ESP32-S3. Firmware status and the
required bench tests are in [FIRMWARE.md](FIRMWARE.md).

Keep service loops modest: approximately 60–80 mm of wire from the XIAO to
the front components is a starting allowance, then trim to the actual route.
These are assembly allowances, not prevalidated cut lengths. Before soldering
the final ends, check the path with the components in the case.

## 5. Fit the upper electronics

1. Attach the included **external antenna** to the XIAO's U.FL socket before
   burying the board. Place the flexible antenna along the upper right plastic
   wall, clear of the encoder and display metal. Keep it out of the weight
   compartment. Confirm radio range after assembly.
2. Put **0.3 mm insulating double-sided mounting tape** on the central XIAO
   pedestal, at most 13 × 17 mm. Solder the board pads from the upper side and
   keep the underside clear so it can sit on this pad.
3. With the faceplate and encoder still out, bring the board in through the
   front, **about 2 mm above its final position**, USB socket toward the rear.
   Slide it back and lower it onto the pedestal. The checked insertion motion
   clears the forward stop. The socket is about **1.6 mm recessed** from the
   rear outer plane. Use a USB plug whose overmould is at most **12 × 7 mm**.
4. Check the USB cable inserts fully without levering the PCB. The printed
   forward stop supports insertion; the tape resists lift and withdrawal.
   Add a relaxed cable loop on the desk rather than letting the cable pull
   sideways on the case.
5. Secure the insulated shifter assembly to the upper left inside wall with
   thin tape. Keep its completed size within **18 × 12 × 4 mm** and place it
   forward of the XIAO. Put the small bulk capacitor above the front floor,
   toward the right; sleeve both leads. Keep electronics out of the weight bay.
6. Fit the KY-040 through Igor's original encoder hole and use its supplied
   washer and nut. Orient its connector toward the open front as space allows.
   Keep wire loops clear of the moving shaft. Fit the hat with a visible gap
   above the shell (nominal 0.6 mm); increase the gap if required for the
   actual encoder's full push travel. It must rotate, click and release freely.
7. Route the display wires, then install the OLED faceplate. Route wires along
   the side walls so the faceplate rim seats without crushing a wire.

## 6. Install the front pixel

1. Feed the pixel's three wires from the underside LED bay up the **3.2 mm
   vertical passage** into the upper electronics bay. Keep the data resistor
   in the upper bay just above this passage; only insulated wires pass through.
2. Insert the diffuser from inside the front bay, small end toward the front
   hole. Its 6.8 mm collar remains inside and prevents it pulling outward.
3. Slide the wired **10 × 10 mm** pixel PCB upward from below into the narrow
   guide slot, LED facing the diffuser. Seat the top edge against the stop.
   The PCB has nominal 0.2 mm side clearance and 0.2 mm depth clearance. Keep
   solder bumps and wires in the wider rear wire bay.
4. The PCB stops the diffuser withdrawing inward, and the cover's tongue
   stops the PCB sliding downward. Retention becomes complete only when the
   cover is installed. No adhesive is required for the lens or pixel.

## 7. Add ballast and close

Lay out the segments on the **inside of the removable cover**, within its
40 × 48 mm recessed center. Use two 19 mm-wide columns and four rows of
segments no longer than 11.5 mm. Repeat as a second layer if using all 80 g.
Keep every piece inside the rectangular recess and clear of the LED tongue,
screw holes and cover-bearing ledge.

The two layers occupy up to 8 mm including their tape, leaving **2 mm** for
clearance and a lightly compressed anti-rattle pad. Adhesive retains each
segment; a thin foam pad prevents movement if the adhesive ages. The total
weights, tape and compressed pad must not exceed the **10 mm** pocket height.
The rigid printed roof separates the metal weights from the electronics.

Lift the cover into place and tighten the four screws just until seated. If
the cover bows or will not sit flush, reopen it and correct the packing.
Fit four Ø8 mm rubber feet approximately at **X=±16 mm, Y=13 and 54 mm**,
measured from the enclosure centerline and front. These positions clear the
screws, so the cover remains serviceable.

## First-prototype acceptance

- Cover flush, all four feet touch the desk, no rattle when lifted.
- Weight pocket, LED bay and upper electronics remain separated; no loose
  metal or exposed conductor can migrate between them.
- USB plug seats and releases without PCB movement; no solder joint rubs a wall.
- Display centered; hat turns, presses and releases without touching the shell.
- Turn and press one-handed on the intended desk; check sliding and tipping
  with the actual weights, feet, encoder force and cable arrangement.
- After the ESP32 firmware port, verify all four states, exact acknowledgments,
  receiver disconnect/recovery, USB restart, LED colors and BLE range with
  ballast installed. Record results before calling this a tested hardware build.

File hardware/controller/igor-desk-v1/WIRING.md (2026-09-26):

# Wiring — USB-powered ESP32-S3 controller

Use the **standard XIAO ESP32-S3**, powered through its USB-C socket from the
computer. Its **5V pin is USB VBUS**. The OLED and encoder use the board's 3V3
output. The single WS2812B and its AHCT buffer use 5V. All grounds are common.
Leave the battery pads unconnected. Use thin, directly soldered wires instead
of pin headers in this enclosure.

## Pin assignment

| XIAO label | ESP32-S3 GPIO | Connect to |
| --- | --- | --- |
| D0 | GPIO1 | Encoder CLK / A |
| D1 | GPIO2 | Encoder DT / B |
| D3 | GPIO4 | Encoder SW, active low |
| D4 | GPIO5 | OLED SDA |
| D5 | GPIO6 | OLED SCL |
| D6 | GPIO43 | AHCT buffer A input, then WS2812B data |
| 3V3 | — | OLED VCC and KY-040 `+` |
| 5V | USB VBUS | Pixel +5V and buffer VCC |
| GND | — | OLED, encoder, pixel and buffer grounds |

Enable pull-ups on the three encoder inputs. A KY-040 board with onboard
pull-ups must be powered from **3.3 V** so those pull-ups cannot feed 5 V to the
ESP32-S3. Any OLED I2C pull-ups likewise belong on 3.3 V. Check the module's
actual printed GND/VCC order; cheap OLED boards vary.

D2/GPIO3 is deliberately unused because it is a strapping pin. Native USB
GPIO19/20, BOOT/GPIO0 and onboard LED GPIO21 are not reassigned. D6 is used for
the pixel instead of UART TX; diagnostics should use native USB.

## Pixel circuit

```text
XIAO D6 / GPIO43 ─────── A     SN74AHCT1G125     Y ── 330 Ω ── WS2812B DIN
                    │          VCC = 5 V                         +5V = VBUS
                  100 kΩ       /OE = GND                         GND = GND
                    │          GND = GND                         DOUT unused
                   GND
```

For the TI DBV / DCK five-pin package, `/OE=1`, `A=2`, `GND=3`, `Y=4`,
`VCC=5`. Verify the breakout's labels instead of assuming header order matches
package pin order. Tie `/OE` low; the 100 kΩ pulldown keeps A defined at boot.
Use a **74AHCT** buffer, not an HC-only part or an I2C MOSFET level shifter.

Place one 100 nF ceramic capacitor directly across the buffer's VCC/GND and
one across the pixel's +5V/GND if its carrier does not already have one.
Put the 330 Ω resistor close to pixel DIN. A 47 µF, ≥10 V capacitor across the
5 V feed near the front reduces local supply transients; connect its marked
negative lead to GND. Keep the pixel ground and data wires together.

The completed shifter/resistor assembly fits an **18 × 12 × 4 mm** insulated
envelope on the left inside wall, forward of the XIAO. Keep the capacitor in
the upper electronics bay, not the small front LED slot. Feed the pixel's
three wires through its vertical passage before inserting the pixel board.

## Power and operation assumptions

The computer provides power; control remains local through the encoder and
BLE to the existing receiver. A desktop companion app is not required by
this hardware design. Reserve a **5 V / 500 mA USB supply budget** and measure
the completed unit; this is a design allowance, not a measured current draw.
Run BLE with Wi-Fi disabled unless a later feature needs Wi-Fi. Start the
single pixel around **12.5% brightness**; full white can draw roughly 60 mA
with older WS2812B variants. Do not drive a large strip from this wiring plan.

The controller loses power if the computer removes USB power during sleep or
shutdown. Boot must read the receiver's state without sending a new status.
Battery charging behavior and the nRF52840 low-power targets do not apply to
this USB controller.

## Sources

- [Seeed XIAO ESP32-S3 pinout and power](https://wiki.seeedstudio.com/xiao_esp32s3_getting_started/)
- [TI SN74AHCT1G125 datasheet and package information](https://www.ti.com/product/SN74AHCT1G125)
- [Adafruit NeoPixel logic-level guidance](https://learn.adafruit.com/adafruit-neopixel-uberguide/logic-level)

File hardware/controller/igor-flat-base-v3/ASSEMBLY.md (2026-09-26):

# Assemble the corrected Igor controller

## Orientation and printing

For use, the **broad base is down, encoder is horizontal, display tilts upward,
and back is vertical**. Supplied STLs use a different orientation for printing:
shell and faceplate front-down, hat and inlays underside-down.

The Bambu projects use a 0.4 mm nozzle, PLA, 0.2 mm layers, four walls,
25% gyroid infill and a 3 mm brim. Supports are enabled for the shell and
removed through its existing front opening. The other parts slice without
supports. Select your printer and actual filament and re-slice.

Print the new shell and front LED faceplate. The hat and two decorative inlays
are unchanged original geometry and can be reused.

## Assembly

1. **Dry-fit the original interfaces.** Clean out support and test the front
   closure, OLED mount, encoder and hat. Use Igor-compatible modules; the
   screen opening and encoder mount have not moved.
2. **Fit the weights in the flat base.** Use three 5 g adhesive steel segments,
   each no larger than **19 × 11.5 × 4 mm including tape**. Place them side by
   side across the **36 × 20 mm** well, long sides front to back. Press onto
   clean, dry floors. Keep them in one layer below the surrounding floor.
   There are no weights in the raised display nose.
3. **Fit the XIAO.** Use the standard ESP32-S3 without headers or Sense
   expansion. Put **0.3 mm electrically insulating double-sided tape** on its
   central mounting pad, at most 13 × 17 mm. Insert USB end first through the
   front opening, with the board's front tipped up about 15°. Align the USB
   socket, advance along the horizontal pocket, then lower the front onto
   the tape. Dry-fit before exposing the adhesive. Test a real cable.
4. **Fit the front NeoPixel.** With the faceplate removed, insert a 5 mm
   through-hole addressable NeoPixel from behind into the hole beside the
   display. Its flange must be at most 6 mm across. Secure the flange with
   a small electronics-adhesive dot. Use the vendor's actual pin diagram.
   Trim and individually insulate leads, keeping joints and bends within
   the checked 3.6 mm diameter × 7 mm space behind the flange. Place a 100 nF
   bypass capacitor close to its power leads, clear of the closure. Check
   the real soldered module fit.
5. **Wire and close.** Follow [WIRING.md](WIRING.md). Secure the insulated buffer
   against the left inner wall. Fit the OLED, encoder and original hat using
   Igor's original arrangement. Route the antenna on upper plastic away from
   weights. Close the faceplate and power through computer USB.

## Physical prototype checks

Confirm print tolerances, retention, full USB seating, OLED clearance, free
encoder rotation and push, and closure over real wires. Verify red/green/blue
channel order; the specified through-hole NeoPixel uses RGB. Check desk
stability with the actual cable connected.

The base extension is 6 mm. The recess has at least 2.1 mm of verified material
beneath it. Continuing the original front underside into the added depth moves
the start of the flat contact patch about 10.4 mm rearward. The width and
vertical rear wall remain unchanged. The main flat contact patch is about
35 × 43.6 mm before its rounded edge regions. The raised nose has no ballast.

Digital checks do not establish a completed physical print, electronics test
or ESP32-S3 firmware implementation.

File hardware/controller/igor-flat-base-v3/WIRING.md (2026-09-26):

# USB-powered ESP32-S3 controller wiring

Use the standard XIAO ESP32-S3, powered by computer USB-C. Leave its battery
pads unconnected. OLED and encoder use 3.3 V; the NeoPixel and AHCT buffer use
the board's USB 5V pin. All grounds are common. Use directly soldered thin
wires and no pin headers.

| XIAO label | GPIO | Connection |
| --- | --- | --- |
| D0 | 1 | Encoder CLK / A |
| D1 | 2 | Encoder DT / B |
| D3 | 4 | Encoder SW, active low |
| D4 | 5 | OLED SDA |
| D5 | 6 | OLED SCL |
| D6 | 43 | AHCT input, then pixel data |
| 3V3 | — | OLED VCC and encoder + |
| 5V | USB VBUS | Pixel and buffer VCC |
| GND | — | All grounds |

Enable pull-ups on encoder inputs. Power KY-040 pull-ups and OLED I2C pull-ups
from 3.3 V. Check each module's printed VCC/GND order. D2/GPIO3 is a strapping
pin and remains unused; native USB GPIO19/20 and BOOT/GPIO0 are not reassigned.

## One front NeoPixel

The mount is for a **5 mm through-hole addressable NeoPixel**, such as
[Adafruit 1938](https://www.adafruit.com/product/1938), with a flange at most
6 mm across. This replaces the earlier 10 × 10 mm carrier. The model allows
7 mm for the body and 7 mm behind the flange for trimmed, insulated leads.
Check the actual dimensions and vendor pinout before printing. An ordinary
four-lead RGB LED is electrically different and cannot be substituted.

Adafruit listed 1938 out of stock when checked on 2026-09-15; a mechanically
compatible addressable pixel can be used after checking its dimensions and
pinout. The flange sits in the rear shoulder and is secured with adhesive.

```text
XIAO D6 ── A  [SN74AHCT1G125, VCC=5 V]  Y ── 330 ohm ── Pixel DIN
           │          /OE = GND                         DOUT unused
         100 kohm                                       +5V = USB 5V
           │                                           GND = common
          GND
```

For TI's five-pin DBV/DCK package: /OE=1, A=2, GND=3, Y=4, VCC=5. Check
breakout labels separately. Use an **AHCT** buffer for 3.3 V input at 5 V supply.
Tie /OE low and put the 100 kohm pulldown on A.

Fit **100 nF across the pixel's power leads**, close to the LED, plus 100 nF
at the buffer supply. Fit a 47 µF capacitor rated at least 10 V across 5V/GND
near the front wiring; observe polarity. Put the 330 ohm resistor close to DIN.
Insulate every trimmed LED lead and solder joint. Dress the local capacitor
clear of the display and faceplate closure.

Secure the insulated buffer/resistor assembly within 18 × 12 × 4 mm against
the left inner wall. Keep the capacitor within a 6.3 mm diameter × 8.5 mm
envelope in the front cavity. Route the XIAO antenna on upper plastic, away
from weights.

Adafruit 1938 specifies **RGB color order**; many flat 5050 modules use GRB.
Set the driver for the actual pixel and confirm the three colors individually.
Start at low brightness. Reserve a 5 V / 500 mA USB supply budget and measure
the complete controller; this is a design allowance, not measured consumption.

The computer may remove USB power during sleep or shutdown. The intended
firmware reads receiver state at boot without issuing a new status command.
The ESP32-S3 firmware port remains unfinished.

## References

- [Seeed XIAO ESP32-S3 pin map and power](https://wiki.seeedstudio.com/xiao_esp32s3_getting_started/)
- [TI SN74AHCT1G125](https://www.ti.com/product/SN74AHCT1G125)
- [Adafruit 5 mm NeoPixel](https://www.adafruit.com/product/1938)
- [Adafruit logic-level guidance](https://learn.adafruit.com/adafruit-neopixel-uberguide/logic-level)

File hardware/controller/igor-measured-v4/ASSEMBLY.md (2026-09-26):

# Print and assembly guide

Use revision 4 parts together. Keep the broad flat base down; the encoder is
horizontal and the display leans upward. Dry-fit before applying adhesive.

## Print

The three supplied Bambu Studio projects use an X1C with a 0.4 mm nozzle:

| Project | Material | Settings |
| --- | --- | --- |
| Shell, knob, XIAO carrier | PLA | 0.2 mm layers, 4 walls, 25% gyroid; supports on shell and knob |
| Faceplate, strip holder, two optional inlays | PLA | Same settings; supports on strip holder |
| Diffuser | Transparent PETG | 0.12 mm layers after 0.2 first layer, 100% infill, 3 walls; no supports |

STLs are oriented for printing. Remove brims and supports carefully, including
the knob socket and strip-holder channel. Check the tiny holder tabs and entry
notches for debris. First-layer scanning is disabled in the projects. Reslice
for your actual printer, plate and filament. The delivered 3MFs are editable
projects; validation sliced copies are used to check printability.

Do not glue the knob to its shaft. Test its D socket first and lightly deburr
if necessary. The two original decorative inlays are optional.

## 1. Encoder before weights

Feed the encoder through the open angled front with the shaft leading into
the shell. Keep it low while turning it upright, then raise it into the roof
hole. The empty base provides room for this maneuver. The five-pin header
faces **forward toward the display**; the registration tab faces rearward.

Seat the metal box in its square locator with a thin adhesive layer at its
upper contact surface (nominal gap 0.25 mm). Hold the shaft centered while it
sets. Add small hot-glue fillets at accessible box/locator edges. Keep glue
away from the rotating shaft, switch and header. PCB solder faces down.
This design uses adhesive retention; no mounting nut or PCB screws are required.

Fit the knob and check rotation and click. At rest its bottom is 1.2 mm above
the roof. The model reserves a 1 mm press, leaving 0.2 mm. Check actual switch
travel before final gluing; remove the knob again while working inside.

## 2. Two wheel weights

Insert each weight through the front above the well and lower it to the floor.
Place them side by side, long dimension front-to-back, with a 0.5 mm gap
between them. Their 6.5 mm height already includes the foam adhesive; add no
extra foam layer. The outer nominal side gaps are 0.25 mm. Press the supplied
adhesive onto a clean floor. No weights go into the raised front nose.

## 3. Carrier and XIAO

Insert the **empty** XIAO carrier through the front, then lower its edges onto
the shell ledges above the weights. Small accessible glue dabs secure it.
The minimum nominal gap from weight tops to carrier underside is 0.7 mm.

Use approximately 0.3 mm insulating mounting tape under the XIAO. Enter low
through the front beneath the encoder, USB socket first, with the board's
front tilted up about 15°. Lower it near the rear opening, slide the socket
through, then lower the front onto its carrier. The PCB fits between the
rails; add small side glue fillets. Keep the reset/boot buttons accessible.

Use soldered wires at the XIAO pads; tall XIAO pin headers are not modeled.
Fit the antenna against upper plastic, clear of weights and the encoder.
Secure and insulate the small level-shifter assembly against the left wall.

## 4. Front subassembly

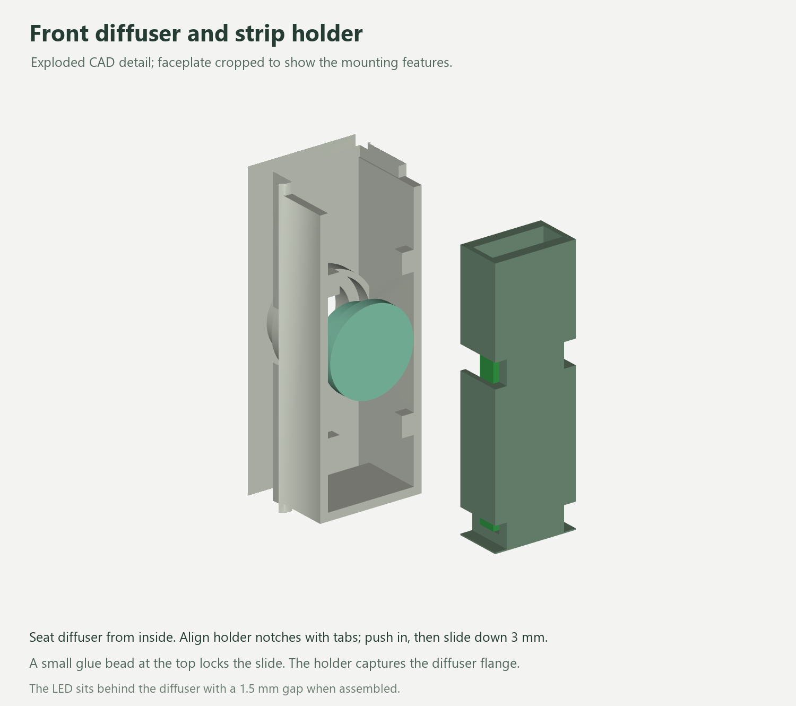
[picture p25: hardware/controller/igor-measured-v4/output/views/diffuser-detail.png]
Exploded diffuser and holder


1. Place the OLED between its edge guides, with the four-pin header at the
   **top/rear** and ribbon at the bottom. Corner stops bear on the PCB front.
   Use small hot-glue dabs on PCB side/corner edges. Keep the glass, ribbon
   loop and bottom notch free of glue. No solder trimming is required by CAD.
2. Insert the transparent PETG diffuser through its hole from behind. The
   larger flange remains inside. An optional tiny dab around its outer flange
   stops rattling; leave the optical faces clean.
3. Slide the mini strip into its holder through the open top, LED facing the
   holder's window. Center the LED on that window. There is a 0.2 mm tape
   allowance behind the strip. Keep solder and strain relief out of the narrow
   channel; route leads from the strip end. The full 17.6 mm length fits.
4. With the strip in place, hold the holder 3 mm above its final position and
   align its edge notches with the four retaining tabs. Push it in from behind,
   then slide it down 3 mm to the bottom stop. The holder now captures the
   diffuser flange. Add a small removable hot-glue bead at the top to prevent
   upward release. No snap-fit flexing is needed.

## 5. Wire, close and check

Follow [WIRING.md](WIRING.md). The encoder and OLED retain their measured
headers. If using plug-on connectors, compare their housings with the allowances
in [FIT-REPORT.md](FIT-REPORT.md); soldered insulated leads may be used instead.
Keep a short service loop clear of the front closure and rotating parts.

Seat the populated faceplate along its normal into Igor's original closure.
Fit the knob/inlays. Check the full display area, free click/rotation, centered
diffuser, stable base and an unobstructed USB plug. Test the LED at low brightness
with red, green and blue separately. Lightly frosting the exposed PETG face is
an optional adjustment if the LED hotspot remains visible.

The component-fit and loading checks are digital. Physical print tolerances,
adhesion, cable routing and optical performance still require this dry-fit and
bench check. The ESP32-S3 application has not yet been ported.

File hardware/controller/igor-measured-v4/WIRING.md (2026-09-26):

# USB-powered measured controller

The standard XIAO ESP32-S3 is powered through computer USB-C. Leave battery
pads unconnected. Power the encoder pull-ups and compatible I2C OLED from
3.3 V; power the single NeoPixel and AHCT buffer from USB 5 V. Join all grounds.
The proposed GPIO assignment follows [Seeed's pin map](https://wiki.seeedstudio.com/xiao_esp32s3_getting_started/).

| XIAO label | GPIO | Connection |
| --- | --- | --- |
| D0 | 1 | Encoder CLK / A |
| D1 | 2 | Encoder DT / B |
| D3 | 4 | Encoder SW, active low |
| D4 | 5 | OLED SDA |
| D5 | 6 | OLED SCL |
| D6 | 43 | AHCT input, then pixel DIN |
| 3V3 | — | OLED VCC and encoder + |
| 5V | USB VBUS | Pixel and buffer VCC |
| GND | — | All grounds |

Enable encoder input pull-ups. Follow each module's printed pin labels; a
four-pin header does not establish pin order or identify the display driver.
Keep I2C pull-ups at 3.3 V. This mechanical revision retains the encoder and
OLED headers; use soldered wires at the XIAO, whose tall pin headers are not
modeled. D2/GPIO3 is left unused and native USB pins are not reassigned.

## Mini NeoPixel strip

Use the user's **17.6 × 5 × 1.4 mm segment**, with the LED centered behind the
diffuser. The exact Adafruit strip SKU was not supplied. Connect the pad marked
**DIN** or the input end indicated by its arrow; leave DOUT unused. Confirm
color order by lighting red, green and blue separately at low brightness.
Do not reuse the revision 3 through-hole pixel assumption.

```text
XIAO D6 ── A  [SN74AHCT1G125, VCC=5 V]  Y ── 330 ohm ── Strip DIN
           │          /OE = GND                         DOUT unused
         100 kohm                                       +5V = USB 5V
           │                                           GND = common
          GND
```

Use the AHCT family for the 3.3-to-5 V data buffer and check the package or
breakout pinout. Tie /OE low. This circuit uses a 100 kohm input pulldown and
a 330 ohm series resistor near DIN. [TI SN74AHCT1G125](https://www.ti.com/product/SN74AHCT1G125),
[Adafruit signal and power guidance](https://learn.adafruit.com/adafruit-neopixel-uberguide/best-practices).

Provide 100 nF bypassing close to the pixel and buffer; account for bypassing
already fitted to the strip. Retain the prototype's compact 47 µF, at least
10 V bulk capacitor near the front power wiring, observing polarity. This is
a one-pixel design allowance and needs a bench check; Adafruit's general guide
recommends larger bulk capacitance for larger pixel installations. Do not force
a larger capacitor into the reserved 6.3 mm diameter × 8.5 mm space.

Keep the insulated buffer/resistor assembly within 18 × 12 × 4 mm against the
left inner wall. Route strip-end wires outside its narrow holder channel and
provide strain relief after dry-fitting. Keep the antenna against upper plastic
away from weights. The complete harness and antenna have not been fit-tested.

Budget up to 5 V / 500 mA for this prototype and measure actual consumption;
this is not a measured current claim. Computer sleep or shutdown may remove
USB power. The intended firmware reads receiver state at boot without sending
a new status. See [firmware status](FIRMWARE.md).

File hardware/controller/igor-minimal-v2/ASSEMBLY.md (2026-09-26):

# Print and assemble the minimal Igor shell

## Print

Use the supplied shell STL **front opening down**. The prepared Bambu project
uses PLA, a 0.4 mm nozzle, 0.2 mm layers, four walls, 25% gyroid infill and a
3 mm brim. Supports are enabled for the shell, including its internal ledges.
Remove them through the existing front opening before fitting electronics.
Print the original hat with its underside down and the faceplate front down;
they and the optional inlays use no supports in the supplied projects.

If reusing an existing Igor, print **only `01-igor-shell-minimal.stl`**. The
faceplate, hat and inlays in this package are unchanged original geometry.
No new screws, heat-set inserts, bottom lid or lens are required.

## Fit the parts

1. **Clean the shell.** Remove support and check the original front closure,
   encoder mount, LED opening and rear USB opening. Dry-fit the purchased OLED
   and encoder against the original mounting geometry. Use Igor-compatible
   modules and the encoder’s original panel nut/washer.
2. **Fit five adhesive weight segments.** Maximum individual size is
   **19 × 11.5 × 4 mm including adhesive**. Put two side by side in the flat front
   well (long edges across the case), and three side by side in the sloping well
   (long edges front to back). Both are accessible through the front opening.
   Press firmly onto clean, dry recess floors. These recesses are sized for one
   layer totaling 25 g with 5 g segments. Insulate any exposed conductive weight
   surfaces near wiring. Keep all weights below the surrounding floor.
3. **Mount the XIAO.** Use the standard ESP32-S3 without headers or Sense
   expansion board. Add **0.3 mm electrically insulating double-sided tape**
   on the central pad, at most 13 × 17 mm. Insert from the front, USB end first,
   with the board’s front tipped up about 15°. As the USB end approaches
   the rear wall, lower it about 2 mm to align the socket with the opening,
   advance along the sloping pocket, then lower the front onto the tape. Dry-fit before
   removing the release liner. The PCB pocket locates the board and the tape
   retains it. Check a real USB cable seats fully without stressing the board.
4. **Mount the pixel under the top opening.** Use a 10 × 10 × 1.6 mm carrier
   with a centered 5 × 5 × 1.6 mm emitter. Insert through the front, emitter up,
   between the small internal locating lands. The board sits just behind the
   faceplate, under the opening ahead of the hat. Secure its edges to the lands
   with small dots of suitable electronics adhesive. Leave the emitter and
   solder pads clear; use directly soldered wires without headers.
5. **Wire and close Igor.** Follow [WIRING.md](WIRING.md). Fit the original OLED,
   encoder, faceplate and hat using the original assembly arrangement. Secure
   the insulated shifter assembly against the left inner wall and dress the
   wires clear of the controls. Fit the XIAO antenna on upper plastic, away
   from the weights. The computer supplies power through USB-C; no battery.

## First physical prototype

The CAD checks use Seeed’s board model, nominal weights and a specified LED
carrier. Check actual solder joints, wire bends, adhesive thickness and module
variation during dry assembly. Verify unobstructed encoder rotation and push,
full USB seating, firm board/weight retention and faceplate closure. A slicer
pass does not establish real printer tolerances or a completed electronics test.

## Size and access

- Overall shell width and front-to-back length remain **49 × 67.27 mm**.
- The bottom moves down 6 mm; the rest of Igor’s original position is retained.
- Flat weight well: **39 × 13 mm**, floor 3.5 mm below the old bottom datum.
- Sloping weight well: **36 × 20 mm** along the original 30° base plane.
- Minimum modeled material beneath the weight wells: approximately **2.2 mm**.
- No removable weight cover: service through Igor’s original front opening.

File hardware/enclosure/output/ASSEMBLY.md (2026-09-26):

# Little On Air enclosure

Native Autodesk Fusion design, built through the local MCP API on port **27182**.
All dimensions and exports use **millimetres**. The front is the XY plane at Z=0;
the rear is at Z=-30. The positive Y edge is the top of the wall-mounted sign.

## Fabrication package

The `output` directory contains the Fusion archive, STEP assembly, individual
part meshes, laser artwork, assembly views, and a geometry verification report.
The editable source is `build_enclosure.py`; the local API client is
`fusion_client.py`. Reference electronics are explicitly named `REF` and must
not be printed.

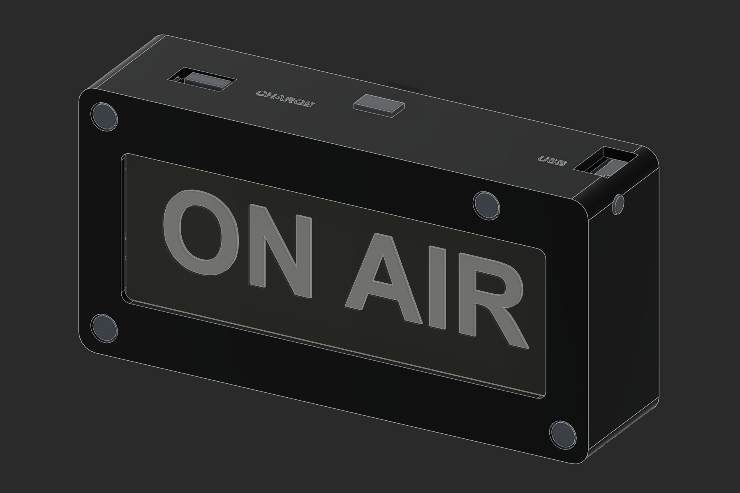
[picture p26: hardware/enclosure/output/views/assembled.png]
Assembled enclosure in Fusion


This is a **first-fit prototype**, not a dimensionally verified production
enclosure. Physical board heights, soldering envelopes, reset position/travel,
switch throw, and LED emitter alignment still need confirmation. Named Fusion
parameters identify these measurements. The native timeline supports editing
individual sketches and features; changes to the overall layout should be made
in the builder and regenerated so all component positions stay coordinated.

## Parts and materials

| Component | Process | Notes |
| --- | --- | --- |
| 01 Body and front frame | Black PETG | Integrated bezel, LED pockets, four front M3 recesses, top USB openings |
| 02 Engraved acrylic | Clear acrylic, CO2 laser | Nominal 3.175 mm; cut and reverse-engrave the supplied artwork |
| 03 Black and white backing | Black then white PETG | Back down; change filament at 1.6 mm; white lettering is 0.4 mm tall |
| 04 Optical and electronics tray | PETG | Three side latches, LED retaining fingers, battery cradle, board and switch mounts |
| 05 Charger keeper | PETG | U clip with locating legs; back ribs prevent withdrawal |
| 06 XIAO keeper | PETG | Side-inserted fork; case stop prevents withdrawal |
| 07 Captive reset plunger | PETG | Insert from inside before fitting the board |
| 08 Captive power slider | PETG | Insert from inside and engage the DPDT actuator |
| 09 Switch keeper | PETG | Removable terminal-access cover, captured by the back |
| 10 Wall back plate | Black PETG | Flat adhesive surface; internal nut bosses and keeper ribs |

Use a 0.4 mm nozzle and 0.2 mm layers as the starting print setup. Use four
perimeters on structural parts and solid small clips. Inspect the slicer for
bridges, support beneath overhangs, and thin features. Remove support from mating
surfaces before checking fit. The mesh package places parts on Z=0 and includes
recommended print orientations; do not apply those transforms to laser artwork.
The 3MF files contain geometry, without a printer profile or automatic filament
change. Set the black-to-white change at Z=1.6 mm manually in the slicer.

The upper-right fastener is at X=96, Y=54 mm, moved inward to clear the XIAO.
The other fasteners are at (6,6), (114,6), and (6,54) mm, measured from the lower-left
front corner. Hardware heads are recessed by 0.2 mm, and screw tips have 0.5 mm
clearance above a 1.3 mm rear skin. Reference bolts have simplified unthreaded shafts.

Hardware: four M3 x 25 mm socket-head screws and four ordinary M3 hex nuts,
removable adhesive mounting strips, a thin nonconductive battery strap, and thin
perimeter/LED cushioning pads. Confirm the actual screw head and nut dimensions
against the fit coupon before printing the full body.

## Optical stack and artwork

The 100 x 34 mm window exposes a 104 x 38 mm keyed acrylic panel. A chamfered
upper-left corner, viewed from the front, identifies the correct orientation.
The backing uses the same outline. A nominal 0.5 mm air gap separates the rear
engraving from the raised white letters. Do not glue the clear viewing faces
together or coat the light-entry edges.

The two upper and two lower LED modules point into the long acrylic edges.
Their emitting-window centres must align to the middle of the measured acrylic
thickness. The supplied 2 mm module thickness does not determine emitter height;
the current model assumes a 1 mm optical offset from the module's front face.

Use the **rear-face** laser file as supplied: the text and the asymmetric cut
outline are mirrored together. The separate front-view artwork is for alignment
and inspection. Engrave only the text layer; cut only the outline layer. Run an
engraving/edge-coupling sample with the actual acrylic before the full panel.

## Assembly and servicing

1. Solder and insulate the LED leads, with the emitting faces kept clean. Lay the
   four modules into the body pockets; route wires beside the modules.
2. Insert the acrylic from the rear, engraving facing inward. Insert the backing
   with the white lettering toward the acrylic, matching the keyed corner.
3. Install the XIAO and its fork keeper on the loose tray. Insert the reset
   plunger into the body from inside before fitting this tray assembly.
4. Fit the tray assembly, positioning the fork behind the case's withdrawal
   stop. Confirm all three side latches engage and the LED fingers contact
   cushioning pads without bending the LED boards. Verify the reset has no
   preload and adjust its contact tip before repeated presses.
5. Fit the charger and its U keeper. Check both actual USB cables can seat fully
   without moving the boards.
6. Fit the top slider, engage the DPDT actuator, and fit the switch keeper.
   Check both detents and adequate clearance for the six soldered terminals.
7. Install the battery and loose nonconductive strap. Keep solder joints, wire
   ends, and screws clear of the pouch; leave room at the battery lead exit.
8. Load the M3 nuts into the back's internal pockets. Check the internal ribs
   align behind the charger and switch keepers, leaving their small running
   gaps. Fit the back and tighten the four front screws gently until the
   compression posts meet.
9. Apply removable adhesive strips to the flat back, keeping removal tabs
   accessible after the body is detached. Remove the front screws to service
   the sign while the back remains on the wall.

Release the tray before removing the XIAO fork. The charger and switch keepers
can be lifted out after removing the back; their legs locate them while the back
ribs provide positive retention during use. Keep wiring out of the rib paths.

## Measurements and physical acceptance

- Measure actual acrylic thickness (3 mm and 1/8 inch are different).
- Verify each separated LED module including solder fillets and emitter height.
- Verify the charger PCB thickness, underside, components, and USB overhang.
- Verify the XIAO reset centre, actuation direction, safe travel, and bare PCB
  support locations. The reference model is an envelope, not a manufacturer STEP.
- Measure DPDT throw separately from the 1.4 mm actuator height. Tune the slider
  slot and socket if necessary. The six legs have a nominal 3 mm trimmed envelope;
  allow additional space for the actual soldered/insulated assembly.
- Verify mating clearances with small samples before full printing. Start at
  0.25 mm per side; keeper legs and slots require printer-specific adjustment.
- Verify letters are aligned and the four LEDs illuminate red/yellow/green
  acceptably, without strong glare or isolated hotspots.
- Test repeated USB insertion, single and double reset presses, switch operation,
  cable bend clearance against the wall, closed-case charging temperature, and
  BLE operation using the intended electrical circuit.

Firmware and the power circuit are unchanged. The mechanical model does not
validate charger selection, charge current, or isolation between the two USB
power paths.

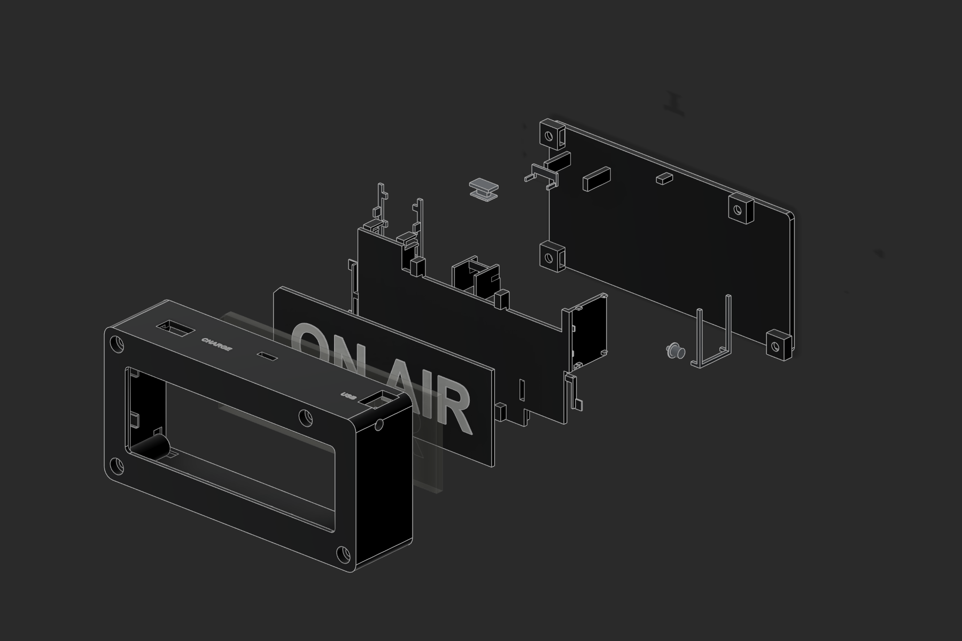
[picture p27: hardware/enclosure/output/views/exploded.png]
Exploded Fusion assembly


The exploded view separates the body, acrylic, backing, carrier, controls,
keepers, and back. The electronics are hidden in this view. See
`views/electronics-layout.png` for the component arrangement, viewed
from the rear (left and right are reversed relative to the front).

## Reproduction

With Fusion's MCP server running on `127.0.0.1:27182`, use Python 3 and run:

These commands use the repository layout. In the ZIP, scripts are in `source`;
run the equivalent commands there without the `hardware/enclosure/` prefix.

```powershell
python hardware/enclosure/fusion_client.py stage setup
python hardware/enclosure/fusion_client.py stage shell
python hardware/enclosure/fusion_client.py stage optics
python hardware/enclosure/fusion_client.py stage backplate
python hardware/enclosure/fusion_client.py stage tray
python hardware/enclosure/fusion_client.py stage keepers
python hardware/enclosure/fusion_client.py stage controls
python hardware/enclosure/fusion_client.py stage references
python hardware/enclosure/fusion_client.py stage refine
python hardware/enclosure/fusion_client.py run hardware/enclosure/correct_fit.py
python hardware/enclosure/fusion_client.py run hardware/enclosure/mechanical_finish.py
python hardware/enclosure/fusion_client.py run hardware/enclosure/finish_design.py
python hardware/enclosure/fusion_client.py run hardware/enclosure/add_fasteners.py
python hardware/enclosure/fusion_client.py run hardware/enclosure/retention_finish.py
python hardware/enclosure/fusion_client.py run hardware/enclosure/verify_fusion.py
python hardware/enclosure/fusion_client.py run hardware/enclosure/export_fusion.py
python hardware/enclosure/fusion_client.py run hardware/enclosure/capture_views.py
python hardware/enclosure/fusion_client.py run hardware/enclosure/fit_coupons.py
python hardware/enclosure/prepare_prints.py
python hardware/enclosure/package_release.py
```

The setup stage creates a new design. Later stages operate only on a design
marked with the `LittleOnAir` attribute. Do not rerun completed build stages in
the same design; they intentionally create new native features.

Print the small samples in `output/print/90-*`, `91-*`, and `92-*` first. They check
M3 heads/nuts, the LED/acrylic interface, and the reset guide. The fastener sample
is shorter than the case, so a 25 mm screw intentionally extends through it.
Also print the small keepers, plunger and slider before committing to the full
body. The carrier needs support beneath its optical partition and overhangs;
remove that support without damaging the latch leaves or snug sockets.

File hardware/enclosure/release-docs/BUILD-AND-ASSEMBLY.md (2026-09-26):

# Build and assembly — enclosure v2.13

Use the complete set in this release. The electronics mounts are integrated into the rear housing; they are independent of the black-and-white display backing. All dimensions below are millimetres.

## 1. Prepare the parts and hardware

Print the ten pieces listed in [PARTS.csv](../PARTS.csv), using the [printing guide](PRINTING.md). Cut and engrave one acrylic panel using the [laser guide](LASER.md). Let printed parts cool before removing brims, support and strings. The clear guides' flat sides are intentional printing surfaces.

Clean screw holes, nut entries, USB apertures and guide pockets. Remove support from reset button 07 and rear guide keeper 11 without shortening the reset tip or rounding retaining shoulders. Dry-fit the shell and retainers; they must seat by hand before screws are tightened. Do not scale the assembly to correct one tight hole.

Use nine M3×8 button-head screws, measured under the head, with heads no larger than 5.7 diameter × 1.65 high, and nine M3 nuts, 5.5 across flats × approximately 2.4 thick. No washers. Allocation: four case closures, two optical-retainer joints, two electronics-yoke joints and one rear-guide-keeper joint.

Load captive nuts while the parts are empty. Directions below are viewed from the front of the sign, top ports upward:

- Upper-left closure nut: enter from below. Lower-left: from the right. Both right closure nuts: from the left.
- Left electronics-yoke nut: from the right. Right yoke nut: from the left.
- Optical-retainer nuts: from the right through their open entries.
- Rear-guide-keeper nut: lower into the open bay below its boss, then slide approximately 7.8 toward the top under the 2 mm roof. It does not load straight through the screw hole.

## 2. Prepare the electrical harness

Disconnect the battery and both USB cables while soldering. Follow the [exact connection table](WIRING.md). Identify switch commons and throws with a meter before attaching wires; physical pin position does not establish electrical function.

Solder the boards outside the case without pin headers. The XIAO's component face will point toward the display; the charger's component face will point toward the rear wall. On the XIAO, leave both long pad rows accessible, route BAT/GND through the gap behind the board, and keep underside solder projection within the reserved 1.25 allowance. The charger OUT+/OUT− corner joints must clear the support seats 5 mm above its bottom edge.

Use flexible stranded wire sized by **insulated outside diameter**, not AWG alone: up to 0.9 for individual leads and compact three-wire LED bundles, and up to 0.8 for the constrained paired routes. Use the [routing map](../reference/routing-map.svg), [coordinate record](../reference/routing-coordinates.json) and [wire-length allowances](../reference/harness-length-guide.csv). Crossing lines on the map may be at different depths. Leave service slack and trim after fitting the actual connectors.

### Connect the capacitor and resistor

Use one of each for the whole four-pixel chain. Follow the [illustrated soldering guide](CAPACITOR-AND-RESISTOR.md) for identifying leads, making the splices, insulating them and checking them with a meter.

| Part | What it does | How to connect it |
| --- | --- | --- |
| **C1: 680 µF, ≥6.3 V capacitor** | Stores a little energy to smooth brief changes in LED power demand | **+** to the VBAT_SW splice after S1 POWER; **−** to charger OUT− / protected ground. These are two branch connections; the main LED power and ground wires continue past them. |
| **R1: 330 Ω resistor** | Reduces sharp transients at the first pixel's data input | Front pigtail **DATA → either resistor lead → other resistor lead → LED1 DIN**. Either orientation works. All data to LED1 must pass through it. |

C1 is polarized: its negative stripe faces the ground connection. Keep its power branch before S2 MODE, and use OUT− rather than the charger's B−. R1 goes in the data wire only; it has no connection to power or ground. Leave the modules' existing SMD components in place. See [Adafruit's NeoPixel guidance](https://learn.adafruit.com/adafruit-neopixel-uberguide/best-practices) for the recommended capacitor and resistor arrangement.

Keep R1 close to LED1 DIN. Its insulated assembly must fit within 12 length × 3.2 diameter, in the 12.5 × 5.7 × 5.6 space behind LED1. C1 stays on the rear housing side of the pigtail: its body must fit within 8 diameter × 11.5 length, on its side in the right lower bay. Use short insulated branch leads with service slack, sleeve every exposed joint separately, and secure the parts so they cannot pull on solder pads or touch the battery pouch. Check both connections before closing the case.

The mated pigtail pair belongs in the left lower service bay, within 13 × 10 × 7.5 including its body. Label and verify both halves **GND, VBAT_SW, DATA**. Junctions belong in the open center, with the dressed trunk following the checked passages. Keep all leads out of screw/nut entries and the new guide keeper's channel.

## 3. Assemble the display in the front frame

With frame 01 face down on a clean soft surface, place the four cut LED modules in their seats, keeping every onboard SMD component and solder pad intact. Point the emitting sides into the clear acrylic edges. Pixel order in the routing drawing is lower-left → lower-right → upper-right → upper-left, as viewed from the front. Follow each module's actual DIN/DOUT labels even when that changes wire dressing.

Route the three-wire chain through the frame's passages. Seat the acrylic with its smooth viewing face outward and engraved face inward. Viewed from the front, ON AIR must read normally and the keyed clipped corner must be upper left. Keep the LED entry edges clear of frosting, adhesive and excess solder.

Place backing 03 behind the acrylic, **white lettering toward the engraved face**. Use the common left/bottom datums so the text aligns. The integral pads set about 0.5 air gap between the white letter tips and the unengraved rear acrylic surface. The letters do not press into the engraving. Keep glue out of this optical gap.

Fit nonconductive shims/cushion behind the backing as specified in the laser guide: `rear gap = 0.45 − (actual acrylic thickness − 3.175)`. At nominal 3.175 thickness this is 0.45. Add thin compliant pads only where the optical retainer supports the LED modules, filling any real seating gap without bending their small boards.

Install optical retainer 04 with two M3×8 screws. Its ears must meet their seats without bowing the acrylic or loading the LED solder joints. Gently shake the subassembly: the panel, backing and LEDs should remain seated. Check text registration before tightening further.

Insert reset button 07 from inside the frame, feeding its keyed rounded stem through the front guide. Its collar retains it inside and its external face projects approximately 2.5. Keep the front subassembly separate for now.

## 4. Install the rear indicator guides first

With charger CH1 still out and the ninth nut already loaded, insert the two short guides 09 from inside housing 05. Their short outlet ends enter the rear viewing holes and their collars seat in the keyed wells. Point the broad printing flats toward the bottom of the sign; the smaller collar flats face the charger fence.

Lower keeper 11 over the guide shafts. Its crossbar enters the short channel through the charger fence and its screw pad bears on the nut boss. Install one M3×8 screw and tighten until seated. Do not use the screw to force alignment. Both guides should be captive with only slight movement; the nominal axial allowance is 0.20. They must not rest against either charger LED.

See [keeper view](../reference/views/rear-guide-keeper.png) and [rear housing view](../reference/views/rear-housing-with-retention.png).

## 5. Install the electronics and battery

Lower the XIAO into its short end supports, **components facing the front, USB toward the top**. Its PCB back seats at depth 19.7 from the display face. The pad beneath reset supports button force. Dress underside leads before clamping; do not trap wires in corner stops or against the antenna end.

Lower the charger into its supports, **components facing the rear, USB toward the top**. The bare PCB face is at depth 15.3 and the component-side face at approximately 16.3, based on the remaining 1.0 PCB-thickness assumption. Both solid lower corners must engage the widened 17.5 stop; the indented center need not touch. Confirm the real board, solder and USB overhang seat without strain. The rear guide pickups must stay clear of the two indicator packages.

Lower the SPDT POWER and DPDT MODE switches into their nests. Use the DPDT's exposed slider directly; there is no printed extension. Its two terminal channels clear three 0.7-wide legs per row with 1.85 clear gaps. The body must sit on its supports, rather than on bent legs or solder sleeves. The SPDT flange ends intentionally remain open for its bracket.

Place the 52 × 21 × 10 battery on approximately 0.5 insulating cushioning in its cradle. Pass a 2.5-wide nonconductive strap through the integral lugs and retain the pouch without compression. Route bundles around the battery, not on top of it; avoid projecting solder joints and sharp edges.

Install electronics yoke 06 with two M3×8 screws. It should seat on both screw bosses by hand. Its pads retain the PCB ends and switch bodies; its roofs finish the USB and slider apertures. Check both USB plugs latch and unplug without shifting a board, and both switches reach both detents. Keep the guide-keeper bay and service disconnect accessible.

## 6. Fit the front guide and close the case

Insert front guide 08 **from inside the detached front frame**, passing its plain outlet end outward through the RGB viewing hole. Seat the internal collar in the frame pocket, with its printing flat toward the bottom of the sign. The narrow pickup end points toward the XIAO RGB LED. The old guide with an exterior collar does not fit this retention scheme.

Hold the guide seated while bringing the front straight onto the housing. Feed the reset stem through the yoke's second keyed guide and the indicator pickup through its existing bore. The yoke completes the front guide's capture, leaving 0.25 nominal axial play. Before closure, the guide can still back out inward.

With POWER off and MODE in PROGRAM, mate the internal pigtail. Dress the slack into the reserved bay. Seat the halves by hand, with no spring pressure, trapped leads or interference. Install the four M3×8 closure screws from the front and tighten gently until the seam is seated. Heads, nuts and tips must remain inset.

The [front section view](../reference/views/front-captive-guide.png) shows the gray frame bearing, amber yoke stop and blue guide. The production frame is whole; the image is a section through the actual solids.

## 7. Check operation and mount

Before power, press and release reset twenty times. It must click before its collar reaches the stop, return freely and not shift the PCB. The current collar allows 0.80 total movement, but actual button contact must be checked physically. Do not force it against the stop. Operate both switches repeatedly and gently push/pull all three guides; they should remain captive without pressing an LED or wire.

Complete the continuity, charge-current, temperature and operating checks in [COMMISSIONING.csv](COMMISSIONING.csv) using the [mode table](WIRING.md). The packaged firmware can exercise the XIAO RGB indicator; the four display NeoPixels require the external-output firmware described in [firmware status](FIRMWARE-STATUS.md).

Once the assembled unit passes its checks, apply removable adhesive strips to the flat rear, leaving the charger viewing holes uncovered. Rear indicators are viewed with the sign removed from the wall. The top USBs/switches and front reset remain accessible.

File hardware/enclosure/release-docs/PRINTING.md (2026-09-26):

# Bambu Studio — current three-plate project

Open [on-air-v213-X1C-all-plates.3mf](../bambu-studio/on-air-v213-X1C-all-plates.3mf) **as a project**, keeping its settings. It targets the **Bambu X1 Carbon, 0.4 mm nozzle and textured PEI plate**. This release retains your three-plate arrangement and painted insert, restores the requested filament profiles, and removes the spare guide keeper. All ten required pieces are present.

| Plate | Contents | Material | Slicer estimate |
| --- | --- | --- | --- |
| 1 | 01 frame, 05 housing, 04 optical retainer, 06 electronics yoke, 07 reset button, 11 rear guide keeper | Black PLA+ | 4 h 46 min / 60.59 g |
| 2 | 03 registered backing | Black and white PLA+ | 1 h 16 min / 10.15 g |
| 3 | 08 front guide and two identical 09 rear guides | Transparent PETG | 13 min / 0.55 g |

Total: approximately **6 h 15 min / 71.30 g**, excluding plate changes. The acrylic is laser-cut separately. There is exactly one keeper 11; the second rear guide is the second copy of STL 09, not an extra keeper.

## Map the filaments

1. **Black PLA+** — previous eSUN PLA+ baseline: 220 °C nozzle, 55 °C textured bed.
2. **White PLA+** — the same PLA+ profile as black, with white color assigned. The PETG assignment from the edited working file has been corrected.
3. **Transparent PETG** — optical profile: 255 °C nozzle, 70 °C textured bed, low part cooling and auxiliary fan off. The generic PETG assignment from the working file has been replaced with the earlier optical profile.

These numbers identify project filaments, not mandatory physical AMS bays. Map them to the actual loaded spools when sending each plate. Match temperatures and calibrated flow to your actual material. If changing a filament profile, re-slice and keep the guide objects' optical settings and low cooling.

The black/white insert uses your mesh painting. Sliced paths remain black through the **1.60 mm base**, with the first white layer at **Z = 1.70 mm**. Letter tops finish at 2.0 mm; the upper registration pads finish at 2.5 mm and are also white. The plate makes one automatic filament change. Its prime tower and **700 mm³ black-to-white flush** are included. Do not add a second manual color change over the painting. The insert's object-level filament can display white while the painted base still slices black; use Preview to inspect the actual paths.

## Settings and handling

- Main structure: 0.20 mm layers, four walls. Housings use 25% gyroid; the optical retainer and yoke use solid infill.
- Reset button and insert: 0.10 mm layers. The insert retains your slower 12 mm/s top-surface setting.
- Guides: lying on their continuous flats, long axes along bed X; 0.10 mm layers, one wall, 100% aligned fill, up to 20 mm/s extrusion, no brim or support. Do not rotate their axes away from the fill direction.
- Automatic support is confined to **07 reset button and 11 rear guide keeper** on plate 1. Other structural parts retain their intended unsupported bridges.
- The compact arrangement has some approximately 2 mm part-to-part gaps. Brims can join; cut connecting brim material after cooling instead of pulling neighboring parts apart.

For keeper 11, support the rigid printed body on the bench while clipping the support away in small sections. Work along the supported underside and avoid levering against the open arm, retaining shoulders or thin edge. Stop and inspect if removal begins bending the keeper. The keeper geometry is unchanged by this packaging update; its fit depends on those retaining surfaces remaining intact.

The first-layer height/speeds and acceleration are shared project settings: **0.10 mm first layer at 15 mm/s**, 1000 mm/s² default acceleration and 500 mm/s² outer-wall acceleration. These retain the optical requirements; main structural layers after the first remain 0.20 mm. Bambu's configuration separates these project settings from [object settings](https://github.com/bambulab/BambuStudio/blob/master/src/libslic3r/PrintConfig.hpp).

**First-layer inspection remains disabled** for the prior timeout workaround. Bed leveling and end-of-print heater shutdown remain enabled. No manual pause commands were added.

## Verification

All three plates were sliced with Bambu Studio 2.8.2.61 without slicer warnings. The ten placed pieces match the latest nine unique STLs, allowing your rotations within the bed plane. Checks confirmed all 25 insert layers' colors, one keeper, correct materials and bed temperatures, support locations, and **332 long guide fill runs parallel to their axes**. See [printing validation](../validation/printing.json).

The original edited project remains preserved in the development archive outside this release. The release file is the corrected, re-sliced copy. Follow the [assembly guide](BUILD-AND-ASSEMBLY.md) after printing; the finished enclosure uses nine M3×8 button-head screws and nine M3 nuts. No print job was sent.

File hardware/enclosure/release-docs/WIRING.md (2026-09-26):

# Two-switch wiring - enclosure v2.13

S1, the larger SPDT, disconnects the sign's load from the protected battery output. S2, the tiny DPDT, separately isolates the XIAO battery input and data output for USB work. The battery remains connected to the charging board when POWER is off; this is a hard disconnect for the sign load, not a zero-leakage battery-storage disconnect.

The four NeoPixels run directly from the single-cell battery rail, labelled **VBAT_SW**, rather than a regulated 5 V supply. Adafruit describes a 3.7 V LiPo supply with 3.3 V logic as a usable configuration. This simplification gives battery-dependent brightness and less voltage margin as the cell discharges. Check the actual pixels over the intended operating range; do not assume every unidentified NeoPixel revision behaves identically. [Adafruit basic connections](https://learn.adafruit.com/adafruit-neopixel-uberguide/basic-connections)

Keep the selected **330 Ω data resistor** near the first pixel and **680 µF capacitor, rated at least 6.3 V**, across the switched pixel rail. The resistor is in series with DATA; the capacitor is in parallel across power, with its negative lead on protected ground. Keep the pixels' existing SMD components. No boost board, logic buffer, MOSFET or separate signal carrier is required by this selected circuit. [Adafruit resistor and capacitor guidance](https://learn.adafruit.com/adafruit-neopixel-uberguide/best-practices)

The SPDT listing rates its contacts at 0.5 A; the DPDT listing is 100 mA. An older-pixel conservative estimate is 4 × 60 mA = 240 mA at full white, plus the MCU branch. This is a paper budget, not a measurement at battery voltage. **Wire LED+ and C1+ directly to the S1 switched rail, before S2.** The tiny switch carries only the MCU branch and signal. Confirm MCU branch current, including startup, remains below 100 mA. Keep a 12.5% initial brightness ceiling and measure actual current. [Adafruit power estimates](https://learn.adafruit.com/adafruit-neopixel-uberguide/powering-neopixels)

The 0.5 A SPDT listing does not specify capacitive-load inrush. Charging 680 µF can briefly exceed steady LED current; a DC steady-current rating alone does not qualify this transient. Test the actual switch/startup behavior and inspect for contact sticking or bounce-related resets. This remains a bench qualification of the parts you own, rather than a reason to add a switching module to the enclosure. [TI explanation of capacitive inrush](https://www.ti.com/lit/an/slva670a/slva670a.pdf)

## Capacitor and resistor: purpose and solder points

The capacitor **C1** stores a little energy to smooth changes in the LED supply. The resistor **R1** reduces sharp transients in the data signal entering LED1. R1 is not an LED power resistor and does not set brightness. Use the [illustrated capacitor/resistor guide](CAPACITOR-AND-RESISTOR.md) for the diagram, polarity markings, step-by-step soldering and meter checks.

| Lead | Connection |
| --- | --- |
| C1 **+** | VBAT_SW: the splice between S1 POWER's ON terminal and the front LED-power wire, before S2 |
| C1 **−** (negative stripe) | Protected ground: the splice joining charger OUT−, XIAO GND and front LED GND |
| One R1 lead | Front pigtail's DATA wire, arriving from S2 pole B common |
| Other R1 lead | LED1 DIN, through a short insulated lead if needed |

C1 goes **across** power and ground as two branch connections. Those power wires continue to the LEDs. R1 goes **in** the data wire, close to LED1, with no wire bypassing it; either resistor orientation works. C1 stays in the rear capacitor bay, while R1 stays with the front LED harness. Use one of each for all four pixels and retain their existing SMD components. Keep the three later DOUT-to-DIN connections direct.

## Exact connections

Disconnect the battery while soldering. Find both switches' commons and throws with a continuity meter. Do not infer pin numbers from the drawing or assume slider direction matches the nearest terminal. A refers to one isolated DPDT pole; B refers to the other.

| From | To |
|---|---|
| Cell positive and negative | Charger B+ and B−, permanently |
| Charger OUT+ | S1 POWER common |
| S1 ON throw | VBAT_SW junction |
| S1 OFF throw | Unconnected and insulated |
| VBAT_SW junction | LED power pigtail, C1 positive, S2 pole A RUN throw |
| S2 pole A common | XIAO BAT+ |
| S2 pole A PROGRAM throw | Unconnected and insulated |
| XIAO D2 / P0.28 | S2 pole B RUN throw |
| S2 pole B common | Front DATA pigtail → 330 Ω near LED1 → LED1 DIN |
| S2 pole B PROGRAM throw | Unconnected and insulated |
| Charger OUT− | XIAO BAT−/GND, C1 negative and LED GND; permanent common protected ground |
| LED1 DOUT → LED2 DIN; LED2 DOUT → LED3 DIN; LED3 DOUT → LED4 DIN | Daisy-chain DATA in this order |
| All four pixel power pads | VBAT_SW, continuous corresponding power rail |
| All four pixel ground pads | Protected ground, continuous corresponding ground rail |
| LED4 DOUT | Unconnected and insulated |

Keep charger B− separate from OUT− outside the board so the protection is not bypassed. Mark the user-supplied pigtails **GND, VBAT_SW, DATA**, checking both halves with a meter. A pixel pad marked +5 V still connects to VBAT_SW in this battery-powered build; do not attach a separate 5 V source to that rail.

## Everyday modes

| Action | POWER | MODE | USB |
|---|---|---|---|
| Use the sign | ON | RUN | Both unplugged |
| Turn sign off | OFF | RUN is acceptable | Both unplugged |
| Charge the cell | OFF | PROGRAM | Charger USB only |
| Program the XIAO | OFF | PROGRAM | XIAO USB only |

**Before connecting either USB, switch POWER off and select PROGRAM. Use only that USB port.** Disconnect USB before returning to RUN and turning POWER on. Move MODE only with POWER off and USB removed. PROGRAM is an electrical isolation position; it does not automatically put the XIAO into its bootloader. Use the captive reset button and the firmware's normal upload procedure as needed.

POWER off alone is insufficient for USB programming: in RUN, the XIAO's onboard charging path could feed the shared battery/pixel rail from USB. PROGRAM disconnects both BAT+ and DATA, preventing that intended-route backfeed and data-line parasitic powering. The circuit provides no automatic USB interlock; arbitrary USB/switch combinations are outside this manual operating procedure. [Seeed XIAO battery and charging documentation](https://wiki.seeedstudio.com/XIAO_BLE/)

## Charging and commissioning

The existing HiLetgo TP4056 board is advertised as up to 1 A. A **1000 mAh capacity does not establish the cell's maximum charge current**. Verify the actual board's setting against the cell specification before charging. Retain the existing current-setting resistor only if that setting is appropriate. If the cell's permitted rate is unknown or lower than the measured setting, resolve that before charging; a replacement programming resistor may then be required on the existing board, with no extra enclosure footprint. It is not an unconditional extra BOM item. A confirmed TP4056 commonly uses about 12 kΩ for 100 mA, but verify the IC and actual current after any change. [TP4056 current-setting and termination table](https://www.umw-ic.com/static/pdf/1c10411cf0937f9f813d2f3f7dea7cda.pdf)

Charge only with the load disconnected using the mode table. A simple TP4056 does not manage system load sharing; a live load can interfere with termination. Keep the XIAO USB unplugged during cell charging and the charger USB unplugged during programming. Check the intended USB-C cable works with the particular board revision.

Before final closure, verify continuity and shorts without the cell, capacitor polarity, POWER isolation, both PROGRAM contact openings, correct protected-ground wiring and no connection to unused throws. On the bench, measure startup and steady currents, all four pixel colors/order, dimming and resets as supply voltage falls. Confirm charger termination with the load disconnected. Test the closed case at intended brightness and during charging; use 40°C cell/case at 20–25°C ambient as a conservative build target, or the cell maker's lower limit. This is an acceptance test, not a simulated or certified thermal result.

## Firmware status for this release

The reserved output is XIAO D2/P0.28. The packaged firmware v0.1.2 still uses onboard RGB PWM only; it does not send NeoPixel data. See [firmware status](FIRMWARE-STATUS.md) before commissioning the external harness. The mechanical guide is [BUILD-AND-ASSEMBLY.md](BUILD-AND-ASSEMBLY.md).

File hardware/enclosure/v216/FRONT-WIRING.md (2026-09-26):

# Rearward LED wiring — v2.16

Reprint **05 rear housing and 06 electronics yoke** using the [two-part upgrade project](../bambu-studio/on-air-v216-X1C-upgrade-parts.3mf). Reuse the v2.15 front frame and all other parts. The wire paths now turn back into the electronics cavity, behind the optical screw heads, instead of taking the outside perimeter around the filled corners. The upper leads need small clearances in 05 and open grooves in 06; changing the front alone would leave those obstructions.

The [complete three-plate project](../bambu-studio/on-air-v216-X1C-all-plates.3mf) includes the same changes. Both replacement parts print in black PLA+, in the supplied orientations, without support. The new passages have open backs, without tunnel roofs to bridge. The nine M3×8 screws, nut pockets, board positions, USB openings, reset mechanism and light-guide bearings are retained. No new hardware or electrical parts are required.

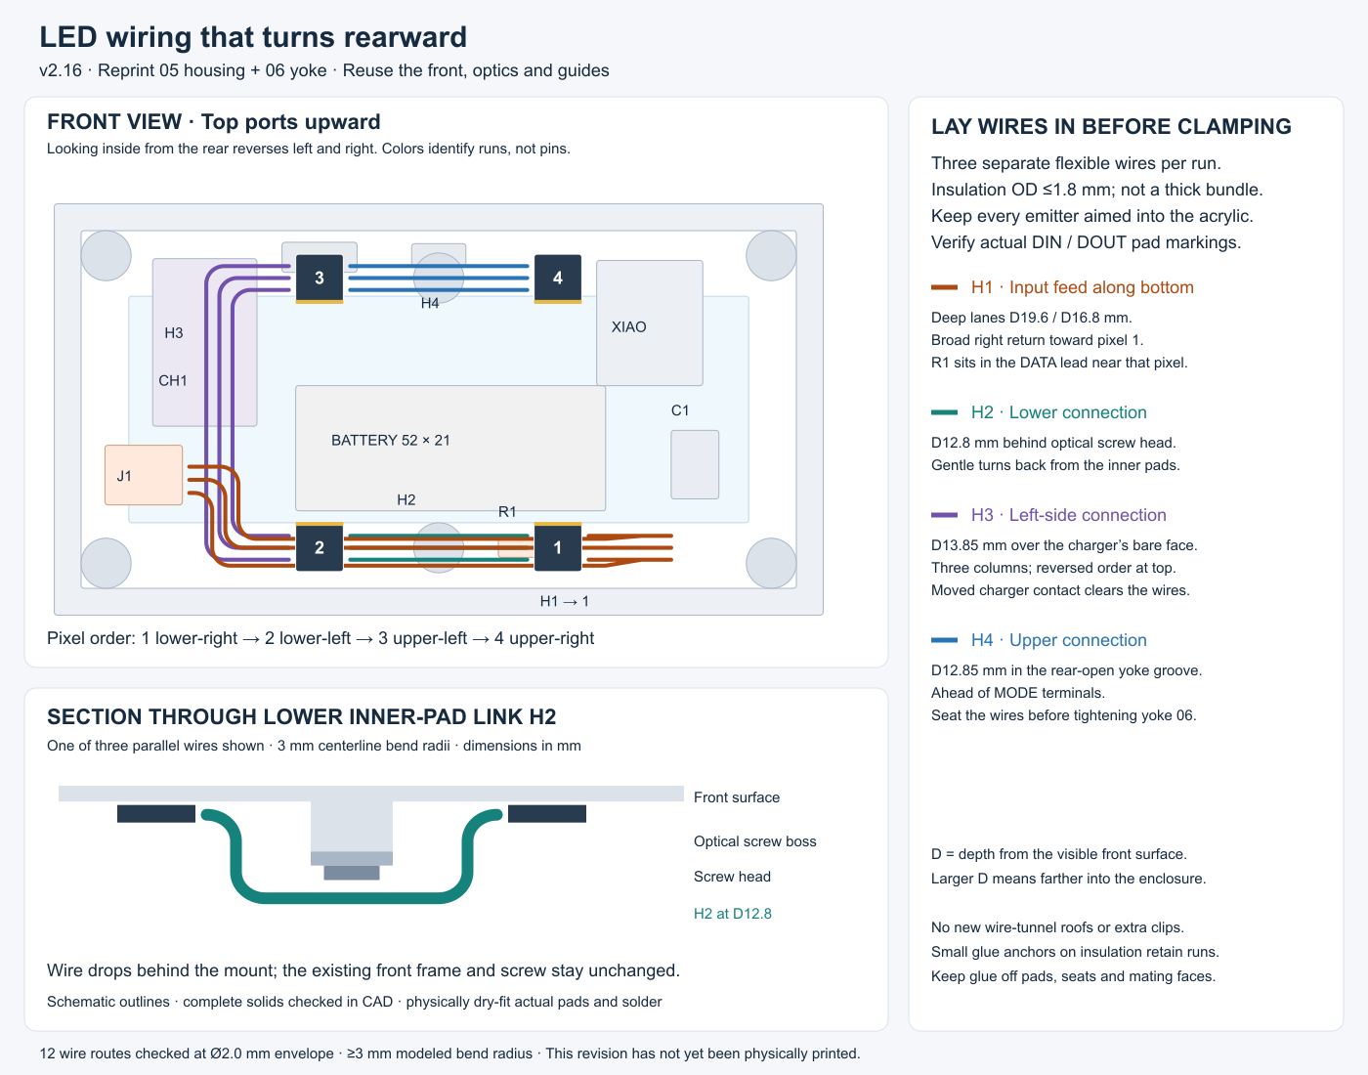
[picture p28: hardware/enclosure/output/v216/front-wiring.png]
Rearward wiring routes and depth section


[Open the scalable drawing](../reference/front-wiring.svg). This is a **front-view projection**: when looking inside the detached front from the rear, left and right are reversed. Depth D is measured back from the visible front surface; larger D is farther into the enclosure. Route colors distinguish harness sections, not electrical pin colors. The background footprints are schematic; the clearance checks use the complete CAD solids.

## Follow the pads, then dress the wires

Use three separate flexible conductors, each **no more than 1.8 mm insulated outside diameter**. Your 24 AWG is preferable if its insulation meets that limit; some 22 AWG insulation will be too large. A joined three-wire cable or a heat-shrink bundle will not fit the shallow upper grooves as drawn. Measure the insulation, not the copper diameter.

The planned pixel order is **1 lower-right → 2 lower-left → 3 upper-left → 4 upper-right**, viewed from the front. This follows the pad direction shown in [Adafruit's side-light strip reference](https://www.adafruit.com/product/3634) when the emitters face the acrylic: the lower row runs right to left and the upper row runs left to right. Your exact strip SKU is still unconfirmed, so verify DIN/DI, DOUT/DO, power and ground on the actual segments before soldering. Do not turn an emitter away from the acrylic to match a drawing. Upper-right DOUT remains unconnected; it needs no outgoing wire through the reset corner.

| Run | Where to lay it | Depth of main run |
| --- | --- | --- |
| H1: disconnect → pixel 1 | Down from the left lower connector bay, across the bottom interior, with a broad return bend below the right capacitor bay to the lower-right pixel's outer pads | Two lanes at D19.6 and one at D16.8; return legs at D13.6 / D10.8 |
| H2: pixel 1 → pixel 2 | Between the lower inner pads, turning rearward behind the lower central optical screw head | D12.8 |
| H3: pixel 2 → pixel 3 | Three parallel columns over the charger's **bare face toward the display**, then back toward the upper-left pixel's outer pads | D13.85; columns X21, 23.2 and 25.4 |
| H4: pixel 3 → pixel 4 | Between the upper inner pads, behind the upper optical screw head and through the open yoke groove in front of MODE's terminals | D12.85 |

The modeled turns use **3 mm wire-center bend radii**. Start bending after the wire has left the pad and its solder joint; do not use the pad as a bending tool. H3 reverses lane order at the opposite end so its wires nest without crossing. H1's three leads also use different depths to clear the battery cradle. The [coordinate record](../reference/routing-coordinates.json) and [nominal length guide](../reference/harness-length-guide.csv) document each lane; lane numbers are physical tracks, not connector pin numbers. Trace electrical connections using [WIRING.md](WIRING.md).

## What changed in the mounts

The rear housing has shallow reliefs beside POWER's supports and ahead of MODE's terminal guard. The fitted switch-body seats remain. The yoke has a wider shared POWER/MODE rail and a **1.95 mm floor beneath its open wire groove**, rather than thin unsupported fingers. Its charger-side rail is widened inward before its outer edge is relieved.

One of the charger's four front contact pads moves under the USB end, onto the bare PCB face. Its contact area, height and nominal **0.15 mm board-face clearance** remain the same; a 45° gusset supports its base for printing. The other three contacts and the proven full-width lower charger stop remain. Check that the moved pad meets bare board, not a solder joint or through-hole on your actual PCB revision.

Revised yoke with open grooves

Shallow reliefs in the rear housing

## Install without threading through tunnels

1. Print 05 and 06 from the upgrade project, let them cool, and remove strings from the open grooves and nut entries. Dry-fit the empty assembly and both switches. Leave yoke 06 loose until the wires are dressed.
2. Disconnect the battery and both USB cables. Solder the boards outside the enclosure. Preserve the existing circuit, including the inline **330 Ω R1** and **680 µF C1**. See [the capacitor/resistor soldering guide](CAPACITOR-AND-RESISTOR.md).
3. Dry-place the four pixels on the original front-frame floors, emitters inward. Plan the actual pad fanout using loose wires before soldering both ends. Start with excess length, form the rearward curves by hand and trim to the real path. Do not simply add a large loop to every conductor; the remaining space is finite.
4. Solder and insulate the pixel harness outside the frame. Keep solder blobs and sleeves outside the shallow grooves. Attach the LEDs with small hot-glue anchors at their backs/corners, leaving the optical floors, emitters and pads clear. Install the acrylic, backing and optical retainer as in [the build guide](BUILD-AND-ASSEMBLY.md); keep leads behind its screw heads, not under its clamping ears.
5. Install the rear light guides and keeper, then the charger, XIAO, switches and battery. Lay H1 along the bottom interior. Its connector body goes in the **left lower bay, X4–17, Y14–24, D12–19.5**: maximum 13 × 10 × 7.5 mm. Leave the connector accessible rather than gluing its two halves together.
6. Lay H3's three wires side by side on the front/bare side of the charger. Lay H4 flat in the new rear-open yoke grooves, between the yoke and the switch terminals. **Dress these wires before seating and tightening yoke 06.** They must not pass between a contact pad and a PCB, or between a switch body and its seat. Keep the existing small rear harness and its junctions off these new corridors.
7. Keep R1 in the bottom interior at **X70–82, Y5.2–8.4, D18–21.2**, in H1's DATA lead approaching pixel 1. Its sleeved assembly must fit within 12 mm length × 3.2 mm diameter. C1 stays in the unchanged right lower bay, body no larger than 8 mm diameter × 11.5 mm long. C1 stays on the rear side of the disconnect; R1 stays with the front pixel harness. Each exposed joint needs its own insulation.
8. Fit yoke 06 by hand, then tighten its two M3×8 screws gently. Check the charger contact under the USB end, both switch seats and the open wire grooves. Use only small hot-glue anchors on insulation in accessible open areas, away from contact pads, emitters, solder pads, screw/nut entries and mating faces. Do not fill the grooves with glue.
9. With POWER off and MODE in PROGRAM, connect the pigtail. Dress limited service slack in **X18–30, Y15–27, D10.3–12.4**. Bring the front straight onto the rear while guiding the reset and RGB guide into their bearings. Seat the seam by hand; do not pull it closed with screws. Reopen if there is spring pressure or a pinched lead.
10. Before the four closure screws are tightened, inspect all four pixel-pad exits, both optical screw heads, the charger contact, the MODE terminal area and the lower-right return bend. Verify reset travel, both USB plugs and both switch detents. Complete [COMMISSIONING.csv](COMMISSIONING.csv).

## What has been checked

All **12 modeled wire runs** clear the assembled CAD at **2.0 mm envelope diameter**, and all 66 wire-pair checks pass. This leaves nominal allowance around 1.8 mm insulation; it is not a guarantee for thicker wire. The rear housing and yoke pass static clearance checks plus 31 sampled yoke-insertion and 31 front-closure positions. Both meshes are single connected, watertight solids. Both supplied Bambu projects were sliced without warnings or supports on 05/06; the new reliefs have no roof bridges.

The wire paths start 1.15 mm beyond the nominal LED side edges. Exact copper-pad coordinates, solder fillets, insulation stiffness, end splices and printed shrinkage remain **physical dry-fit checks**. Motion checks cover the rigid parts, not automatic movement of flexible wires during closure. This revision has not yet been physically printed. The laser artwork and all unchanged parts are byte-identical to v2.15; no new acrylic or backing is needed.

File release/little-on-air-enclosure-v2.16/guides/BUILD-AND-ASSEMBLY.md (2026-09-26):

# Build and assembly — enclosure v2.16

Use the complete set in this release. The electronics mounts are integrated into the rear housing; they are independent of the black-and-white display backing. All dimensions below are millimetres.

## 1. Prepare the parts and hardware

Print the ten pieces listed in [PARTS.csv](../PARTS.csv), using the [printing guide](PRINTING.md). Cut and engrave one acrylic panel using the [laser guide](LASER.md). Let printed parts cool before removing brims, support and strings. The clear guides' flat sides are intentional printing surfaces.

Clean screw holes, nut entries, USB apertures and guide pockets. Remove support from reset button 07 and rear guide keeper 11 without shortening the reset tip or rounding retaining shoulders. Dry-fit the shell and retainers; they must seat by hand before screws are tightened. Do not scale the assembly to correct one tight hole.

Use nine M3×8 button-head screws, measured under the head, with heads no larger than 5.7 diameter × 1.65 high, and nine M3 nuts, 5.5 across flats × approximately 2.4 thick. No washers. Allocation: four case closures, two optical-retainer joints, two electronics-yoke joints and one rear-guide-keeper joint.

Load captive nuts while the parts are empty. Directions below are viewed from the front of the sign, top ports upward:

- Upper-left closure nut: enter from below. Lower-left: from the right. Both right closure nuts: from the left.
- Left electronics-yoke nut: from the right. Right yoke nut: from the left.
- Optical-retainer nuts: from the right through their open entries.
- Rear-guide-keeper nut: lower into the open bay below its boss, then slide approximately 7.8 toward the top under the 2 mm roof. It does not load straight through the screw hole.

## 2. Prepare the electrical harness

Disconnect the battery and both USB cables while soldering. Follow the [exact connection table](WIRING.md). Identify switch commons and throws with a meter before attaching wires; physical pin position does not establish electrical function.

Solder the boards outside the case without pin headers. The XIAO's component face will point toward the display; the charger's component face will point toward the rear wall. On the XIAO, leave both long pad rows accessible, route BAT/GND through the gap behind the board, and keep underside solder projection within the reserved 1.25 allowance. The charger OUT+/OUT− corner joints must clear the support seats 5 mm above its bottom edge.

The revised H1–H4 LED harness uses three separate flexible wires per run, each up to **1.8 mm insulation outside diameter**, laid rearward behind the optical screw heads and through the new open yoke grooves. Follow [FRONT-WIRING.md](FRONT-WIRING.md), its [diagram](../reference/front-wiring.svg), and the [nominal length guide](../reference/harness-length-guide.csv). Start overlong, dry-fit and trim; lane numbers describe tracks, not electrical pin numbers. Keep the fitted rear harness's compact leads (up to 0.9 mm OD, or 0.8 mm for constrained pairs) and dressed junctions clear of the new paths. Historical rear paths in [the coordinate record](../reference/routing-coordinates.json) are reference only and require dressing around this revision; old H1–H4 coordinates are superseded.

### Connect the capacitor and resistor

Use one of each for the whole four-pixel chain. Follow the [illustrated soldering guide](CAPACITOR-AND-RESISTOR.md) for identifying leads, making the splices, insulating them and checking them with a meter.

| Part | What it does | How to connect it |
| --- | --- | --- |
| **C1: 680 µF, ≥6.3 V capacitor** | Stores a little energy to smooth brief changes in LED power demand | **+** to the VBAT_SW splice after S1 POWER; **−** to charger OUT− / protected ground. These are two branch connections; the main LED power and ground wires continue past them. |
| **R1: 330 Ω resistor** | Reduces sharp transients at the first pixel's data input | Front pigtail **DATA → either resistor lead → other resistor lead → LED1 DIN**. Either orientation works. All data to LED1 must pass through it. |

C1 is polarized: its negative stripe faces the ground connection. Keep its power branch before S2 MODE, and use OUT− rather than the charger's B−. R1 goes in the data wire only; it has no connection to power or ground. Leave the modules' existing SMD components in place. See [Adafruit's NeoPixel guidance](https://learn.adafruit.com/adafruit-neopixel-uberguide/best-practices) for the recommended capacitor and resistor arrangement.

Keep R1 close to LED1 DIN. Its insulated assembly must fit within 12 length × 3.2 diameter, in the bottom interior at X70–82, Y5.2–8.4, depth 18–21.2 from the front face. C1 stays on the rear housing side of the pigtail: its body must fit within 8 diameter × 11.5 length, on its side in the right lower bay. Use short insulated branch leads with service slack, sleeve every exposed joint separately, and secure the parts so they cannot pull on solder pads or touch the battery pouch. Check both connections before closing the case.

The mated pigtail pair belongs in the left lower service bay, X4–17, Y14–24, depth 12–19.5, within 13 × 10 × 7.5 including its body. Label and verify both halves **GND, VBAT_SW, DATA**. Junctions belong in the open center, with the dressed trunk following the checked passages. Keep all leads out of screw/nut entries and the new guide keeper's channel.

## 3. Assemble the display in the front frame

With frame 01 face down on a clean soft surface, place the four cut LED modules in their seats, keeping every onboard SMD component and solder pad intact. Point the emitting sides into the clear acrylic edges. Pixel order in the routing drawing is lower-right → lower-left → upper-left → upper-right, as viewed from the front. Follow each module's actual DIN/DOUT labels even when that changes wire dressing.

Shape LED leads rearward behind the optical mounts, following [FRONT-WIRING.md](FRONT-WIRING.md). The existing perimeter channels are optional; the checked routes now use the interior. Secure the modules with small hot-glue anchors, retaining the original floor height and keeping emitters/pads clear. The interfering side lips are removed. Check real wires and joints before installing the optical retainer. Seat the acrylic with its smooth viewing face outward and engraved face inward. Viewed from the front, ON AIR must read normally and the keyed clipped corner must be upper left. Keep the LED entry edges clear of frosting, adhesive and excess solder.

Place backing 03 behind the acrylic, **white lettering toward the engraved face**. Use the common left/bottom datums so the text aligns. The integral pads set about 0.5 air gap between the white letter tips and the unengraved rear acrylic surface. The letters do not press into the engraving. Keep glue out of this optical gap.

Fit nonconductive shims/cushion behind the backing as specified in the laser guide: `rear gap = 0.45 − (actual acrylic thickness − 3.175)`. At nominal 3.175 thickness this is 0.45. Add thin compliant pads only where the optical retainer supports the LED modules, filling any real seating gap without bending their small boards.

Install optical retainer 04 with two M3×8 screws. Its ears must meet their seats without bowing the acrylic or loading the LED solder joints. Gently shake the subassembly: the panel, backing and LEDs should remain seated. Check text registration before tightening further.

Insert reset button 07 from inside the frame, feeding its keyed rounded stem through the front guide. Its collar retains it inside and its external face projects approximately 2.5. Keep the front subassembly separate for now.

## 4. Install the rear indicator guides first

With charger CH1 still out and the ninth nut already loaded, insert the two short guides 09 from inside housing 05. Their short outlet ends enter the rear viewing holes and their collars seat in the keyed wells. Point the broad printing flats toward the bottom of the sign; the smaller collar flats face the charger fence.

Lower keeper 11 over the guide shafts. Its crossbar enters the short channel through the charger fence and its screw pad bears on the nut boss. Install one M3×8 screw and tighten until seated. Do not use the screw to force alignment. Both guides should be captive with only slight movement; the nominal axial allowance is 0.20. They must not rest against either charger LED.

See [keeper view](../reference/views/rear-guide-keeper.png) and [rear housing view](../reference/views/rear-housing-with-retention.png).

## 5. Install the electronics and battery

Lower the XIAO into its short end supports, **components facing the front, USB toward the top**. Its PCB back seats at depth 19.7 from the display face. The pad beneath reset supports button force. Dress underside leads before clamping; do not trap wires in corner stops or against the antenna end.

Lower the charger into its supports, **components facing the rear, USB toward the top**. The bare PCB face is at depth 15.3 and the component-side face at approximately 16.3, based on the remaining 1.0 PCB-thickness assumption. Both solid lower corners must engage the widened 17.5 stop; the indented center need not touch. Confirm the real board, solder and USB overhang seat without strain. The rear guide pickups must stay clear of the two indicator packages.

Lower the SPDT POWER and DPDT MODE switches into their nests. Use the DPDT's exposed slider directly; there is no printed extension. Its two terminal channels clear three 0.7-wide legs per row with 1.85 clear gaps. The body must sit on its supports, rather than on bent legs or solder sleeves. The SPDT flange ends intentionally remain open for its bracket.

Place the 52 × 21 × 10 battery on approximately 0.5 insulating cushioning in its cradle. Pass a 2.5-wide nonconductive strap through the integral lugs and retain the pouch without compression. Route bundles around the battery, not on top of it; avoid projecting solder joints and sharp edges.

Lay H3 over the charger’s bare front face and H4 in the rear-open yoke grooves **before clamping the yoke**. Keep wires out of all board/switch contact seats. The relocated upper charger contact lands on bare board under the USB end; confirm it avoids solder and through-holes. Install electronics yoke 06 with two M3×8 screws. It should seat on both screw bosses by hand. Its pads retain the PCB ends and switch bodies; its roofs finish the USB and slider apertures. Check both USB plugs latch and unplug without shifting a board, and both switches reach both detents. Keep the guide-keeper bay and service disconnect accessible.

## 6. Fit the front guide and close the case

Insert front guide 08 **from inside the detached front frame**, passing its plain outlet end outward through the RGB viewing hole. Seat the internal collar in the frame pocket, with its printing flat toward the bottom of the sign. The narrow pickup end points toward the XIAO RGB LED. The old guide with an exterior collar does not fit this retention scheme.

Hold the guide seated while bringing the front straight onto the housing. Feed the reset stem through the yoke's second keyed guide and the indicator pickup through its existing bore. The yoke completes the front guide's capture, leaving 0.25 nominal axial play. Before closure, the guide can still back out inward.

With POWER off and MODE in PROGRAM, mate the internal pigtail. Dress the slack into the reserved bay. Seat the halves by hand, with no spring pressure, trapped leads or interference. Install the four M3×8 closure screws from the front and tighten gently until the seam is seated. Heads, nuts and tips must remain inset.

The [front section view](../reference/views/front-captive-guide.png) shows the gray frame bearing, amber yoke stop and blue guide. The production frame is whole; the image is a section through the actual solids.

## 7. Check operation and mount

Before power, press and release reset twenty times. It must click before its collar reaches the stop, return freely and not shift the PCB. The current collar allows 0.80 total movement, but actual button contact must be checked physically. Do not force it against the stop. Operate both switches repeatedly and gently push/pull all three guides; they should remain captive without pressing an LED or wire.

Complete the continuity, charge-current, temperature and operating checks in [COMMISSIONING.csv](COMMISSIONING.csv) using the [mode table](WIRING.md). The packaged firmware can exercise the XIAO RGB indicator; the four display NeoPixels require the external-output firmware described in [firmware status](FIRMWARE-STATUS.md).

Once the assembled unit passes its checks, apply removable adhesive strips to the flat rear, leaving the charger viewing holes uncovered. Rear indicators are viewed with the sign removed from the wall. The top USBs/switches and front reset remain accessible.

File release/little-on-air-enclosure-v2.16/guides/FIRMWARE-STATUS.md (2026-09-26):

# Firmware included with the manufacturing release

Enclosure revision **2.16** and firmware version **0.1.2** are separate version numbers. The earlier v0.1.2 firmware snapshot is preserved under `firmware/`; its exact commit is recorded in the release manifest. It is not a statement of the current development repository’s firmware capabilities. This packaging task does not change, build or flash firmware.

The bundled snapshot uses `src/status_output_pwm.c` and the board's `pwm_red`, `pwm_green` and `pwm_blue` aliases. It operates the **onboard RGB LEDs**, including the XIAO indicator visible through the new front guide. It does **not** configure or drive the four external NeoPixels on D2/P0.28.

The two-switch wiring guide reserves D2/P0.28 for the external data chain. To finish the illuminated display, use and validate an external addressable-pixel driver configured for the actual four modules, their protocol/color order, the data pin and a conservative brightness ceiling. Startup, low-cell-voltage behavior and current must then be tested with the physical harness. The PWM brightness setting alone does not add an addressable LED output.

The source ZIP contains the repository's firmware build, flashing, pairing and diagnostics guides, plus its pinned dependency manifest. The Zephyr toolchain/dependencies and generated local build directories are not included. No ambiguous local UF2 or ELF was selected as a release binary.

For USB work on the assembled sign, the enclosure's operating procedure takes precedence over the generic source flashing instructions: **POWER off, MODE in PROGRAM, only the XIAO USB plugged in**. Double-tap the front reset to use the factory bootloader as described in the source's `docs/FLASHING.md`. MODE selects electrical isolation; it does not enter the bootloader automatically. Unplug USB before selecting RUN and turning POWER on.

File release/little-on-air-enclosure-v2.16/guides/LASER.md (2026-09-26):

# Acrylic and LightBurn — Nova Plus 24, 60 W RF

Use `laser/02-acrylic-REAR-engrave-and-cut.svg` for the production panel. It is **104 × 38 mm**, with outlined text and a keyed outline. It contains no machine power or speed preset and no kerf compensation. Its rear engraving and key are already mirrored.

The machine for this project is the Thunder Nova Plus 24 with the 60 W RF source. Use its verified installed device profile, lens, focus and air-assist procedure. Do not substitute a glass-tube Nova's power/speed table or change controller frequency settings for this job. [Thunder Nova Plus RF manual](https://support.thunderlaserusa.com/portal/en/kb/articles/thunder-laser-nova-plus-rf-machine-user-manual).

## Stock and fit

Use confirmed clear PMMA acrylic; cast material generally produces a frosted engraved target. Verify the sheet and masking are suitable for the laser. Measure the nominal 1/8-inch stock at its corners and middle; nominal thickness is 3.175 mm, not exactly 3.0 mm.

The existing stack accommodates approximately **3.00–3.45 mm** using measured rear shims and cushioning. Calculate the remaining gap behind the printed backing as:

`rear cushion gap = 0.45 − (measured acrylic thickness − 3.175) mm`

| Measured acrylic | Available rear gap |
| --- | --- |
| 3.00 mm | 0.625 mm |
| 3.175 mm | 0.450 mm |
| 3.45 mm | 0.175 mm |

Use thin nonconductive shims and a compliant layer at the intended retainer contacts to fill this gap without bowing the panel. Outside that thickness range, revise the stack instead of forcing it. Register the acrylic and backing against the common left/bottom datums. Leave the opposite-edge clearance for fit and expansion; do not glue all four edges rigidly.

The white printed letters face the engraved rear acrylic surface across approximately **0.5 mm of air**. They are a separate contrast/illumination backing, not an inlay into engraved pockets. Keep the clear face and the air gap free of adhesive. The hidden printed registration pads extend farther than the white letters; their exposed sides may be blackened if visible at an angle.

## Calibrate on scrap from the same sheet

1. Import [91 kerf coupon](../laser/calibration/91-kerf-plug-and-frame-CUT.svg) at **40 × 30 mm**, without compensation. Cut its nominal 20 × 20 inner square before the outer outline. Measure the loose plug P and opening H in both axes and at both faces. Estimate full kerf as `(H − P) / 2`. Compare `20 − P` and `H − 20` to identify taper or measurement error.
2. For the production **outside** outline, move the cutting path outward by **half that full kerf**. Verify the resulting geometry in Preview; LightBurn's kerf controls and a manual path offset are alternatives, not adjustments to stack together. Keep text at 100% scale with no offset. [LightBurn kerf guide](https://docs.lightburnsoftware.com/latest/Guides/Test-KerfOffset/).
3. Use the [90 fit strip](../laser/calibration/90-fit-strip-CUT-ONLY.svg), **31 × 6 mm**, to check the sheet edge in the actual frame/retainer stack. It does not replace the full panel's registration check.
4. Use [92 engraving samples](../laser/calibration/92-engraving-quality-nine-samples-FILL.svg) with the rear face up. Start from a proven RF acrylic engraving setting. Compare line intervals **0.10, 0.125 and 0.15 mm** across columns and modestly lower/base/higher energy down rows. Record which colored sample receives each setting. These are calibration choices, not an established machine recipe.
5. Aim for a shallow, even frosted engraving, roughly **0.05–0.15 mm deep**, without ridges, cracks or a melted lip. This is a target to evaluate on scrap, not a depth guaranteed by a power percentage. Choose the least aggressive setting that gives useful scattering. Record speed, minimum/maximum power, interval, focus, lens, air and passes in [COMMISSIONING.csv](COMMISSIONING.csv).

## Make the panel

1. Import the [production SVG](../laser/02-acrylic-REAR-engrave-and-cut.svg) at exactly **104 × 38 mm**. Keep the intended rear face toward the laser. **Do not mirror again.**
2. Assign **blue to Fill** for the lettering and **red to Line** for the outside cut. Engrave first, cut last. Apply only the tested outline compensation; avoid duplicate outline passes.
3. Preview the job: letter counters should remain unengraved, the text should appear reversed before cutting, and the cut outline should run once. Use your confirmed RF device and successful scrap settings.
4. After cutting, flip the panel left-to-right. ON AIR should read normally from the front and the clipped corner should be upper left. Clean the panel according to the acrylic supplier's guidance. Keep all four LED entry edges smooth and free of frosting, glue or masking residue.
5. Dry-fit with backing 03 in the common datums, check lettering registration, then fit cushioning and retainer 04 according to the assembly guide.

`laser/02-acrylic-REVIEW-ONLY.lbrn2` is supplied for inspecting layer order and geometry. Its layer outputs are disabled and all powers are zero. Its saved device name and remaining speed/interval fields are historical placeholders, not a validated RF machine setup. Importing the SVG into your verified current device is the preferred route.

## Optional laminate alternative

The selected build uses the printed black-and-white backing. Only if substituting a measured **1.6 mm, laser-safe black-over-white laminate**, use the separate unmirrored artwork and **both** spacer rings under [alternatives/laminate](../alternatives/laminate/README.md). Do not install those rings with the printed backing or cut the laminate artwork as the acrylic panel.

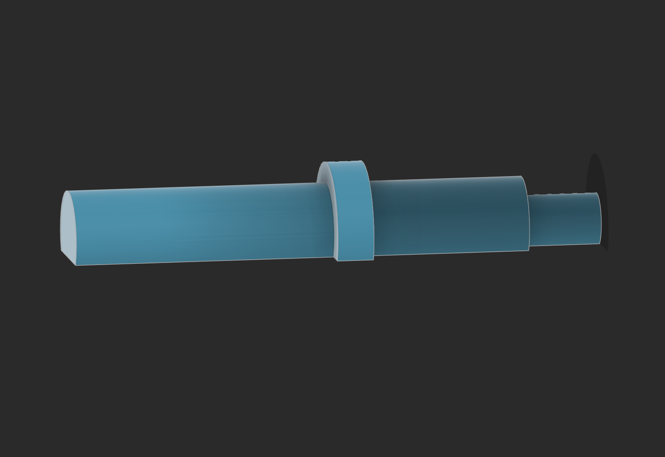
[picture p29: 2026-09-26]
release/little-on-air-enclosure-v2.16/reference/views/front-guide-shape.png

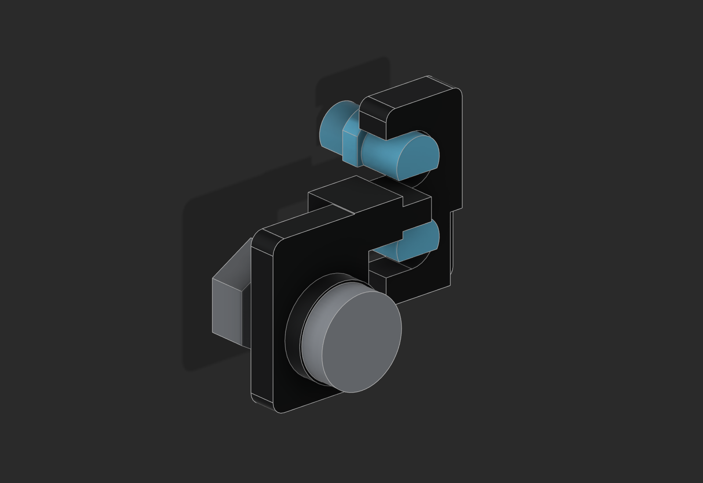
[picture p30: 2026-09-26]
release/little-on-air-enclosure-v2.16/reference/views/rear-guide-keeper.png

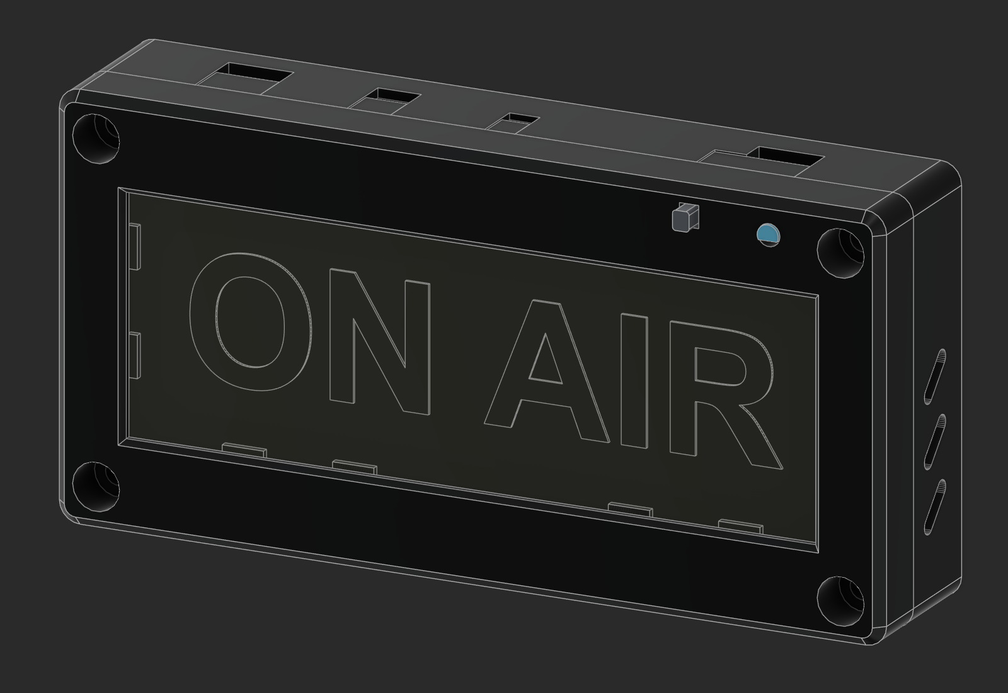
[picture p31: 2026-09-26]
release/little-on-air-enclosure-v2.16/reference/views/complete-assembly.png

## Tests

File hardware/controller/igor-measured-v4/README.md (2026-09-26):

# Project IGOR controller — measured-fit revision 4

This revision fits the supplied component measurements while retaining Igor's
original outline and orientation: **flat base down, horizontal encoder,
upward-facing display and vertical back**. It starts from the author's exact
STEP model and supersedes controller revisions 1–3.

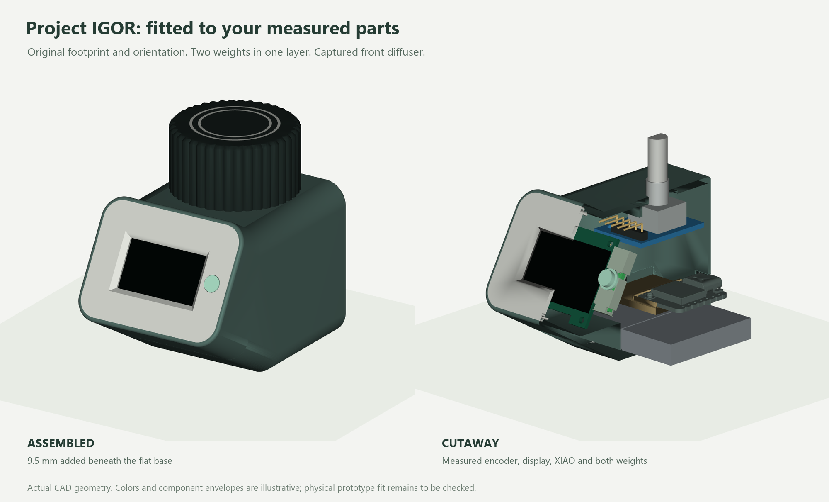
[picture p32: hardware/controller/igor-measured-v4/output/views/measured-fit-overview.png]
Measured controller and cutaway


## Changes

- **Two 20 × 33.5 × 6.5 mm weights**, side by side in one layer. The 6.5 mm
  includes their foam adhesive. A **9.5 mm base extension** provides a solid
  floor and clearance beneath the XIAO carrier. Original width and depth are
  retained; the raised front nose contains no weights.
- **Measured encoder mount and knob socket.** A close-fitting box locator
  includes tab clearance; the right-angle header faces forward. The original
  knob exterior is retained, with a new D socket and a 1.2 mm lift to allow a
  1 mm button press. The 5.4 mm shaft measurement is confirmed along the flat.
- **Measured OLED supports.** Edge guides replace the incompatible original
  pegs. The window throat grows to 26.2 × 15.2 mm so the 25.5 × 14.5 mm active
  area is visible. The ribbon, front solder and rear header have clearance.
- **Front mini-strip NeoPixel and transparent PETG diffuser.** The full
  17.6 × 5 × 1.4 mm segment fits a removable holder. A 5 mm visible diffuser
  has a retaining flange captured between the faceplate and holder. Its center
  matches the LED, with a 1.5 mm light-mixing gap.
- **Removable XIAO ESP32-S3 carrier**, above the weights. The rear USB opening
  is 9.8 × 4.6 mm and is raised 1.71 mm from revision 3.

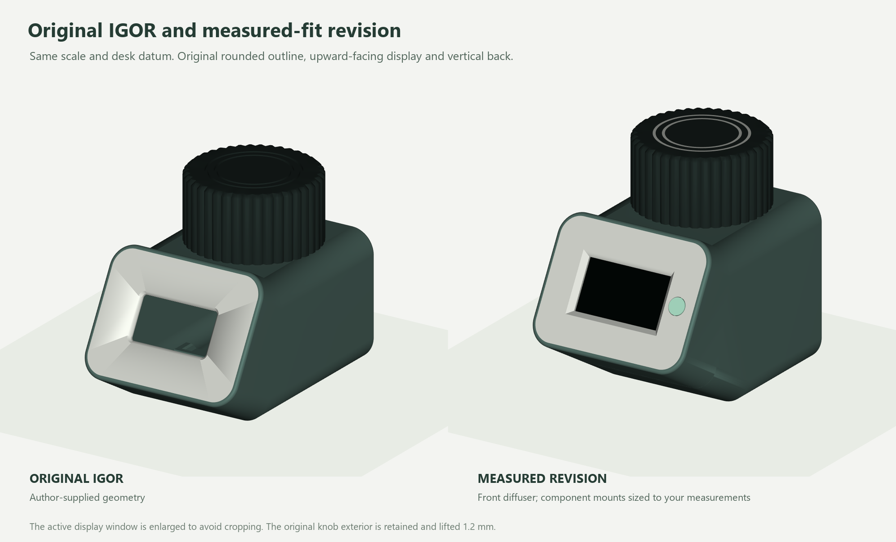
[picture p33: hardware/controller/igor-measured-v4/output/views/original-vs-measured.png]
Original and measured revision


## Files

- [Fit report](FIT-REPORT.md) · [Assembly guide](ASSEMBLY.md) · [BOM](BOM.csv)
- [Assembled STEP](output/cad/igor-measured-v4.step)
- [Shell STL](output/stl/01-igor-measured-shell.stl)
- [Faceplate STL](output/stl/02-igor-measured-faceplate.stl)
- [Knob STL](output/stl/03-igor-measured-hat.stl)
- [Transparent PETG diffuser STL](output/stl/06-front-diffuser-PETG.stl)
- [LED strip holder STL](output/stl/07-strip-cassette.stl)
- [XIAO carrier STL](output/stl/08-xiao-carrier.stl)
- [PLA shell, knob and carrier project](output/bambu-studio/igor-measured-v4-X1C-PLA-shell-hat-carrier.3mf)
- [PLA face, holder and inlays project](output/bambu-studio/igor-measured-v4-X1C-PLA-face-cassette-inlays.3mf)
- [Transparent PETG diffuser project](output/bambu-studio/igor-measured-v4-X1C-transparent-PETG-diffuser.3mf)
- [Wiring](WIRING.md) · [Firmware status](FIRMWARE.md) · [Source attribution](SOURCES.md)

There are eight STLs, including the two optional original decorative inlays.
The revised knob should be printed for this measured shaft. STEP models use
the desk frame, with the original base at Z=0 and the new bottom at Z=-9.5 mm.
STLs are already oriented on the print bed. Reference component meshes are
for inspection, not printing.

## Verification

The parts are valid native solids and closed, connected STL meshes. Digital
checks cover supplied component envelopes, retained headers and solder, knob
motion, component loading, front closure, diffuser capture and the active
display opening. All three Bambu projects slice without warnings. See the
[fit results](output/validation/fit.json) and [package audit](output/validation/package-audit.json).

These are prototype files: printed tolerances, actual switch travel, connector
housings, wiring bends and optical diffusion need a physical check. The measured
pins are modeled; extra connector space is explicitly an allowance. No physical
print test was recorded for this design package. The assembled controller's
[ESP32-S3 firmware](../../../apps/controller-esp32s3/README.md) now has local
electronics bench results; [receiver integration remains to be tested](../../../docs/ESP32S3_BENCH.md).

## Rebuild

Install `requirements.txt`, then run from this directory:

```text
python run_cad.py build
python run_cad.py validate_fit
python prepare_prints.py
python render_views.py
python package.py
```

The slicer check uses Bambu Studio on Windows. `run_cad.py` preserves ordinary
error reporting while avoiding an OpenCascade interpreter teardown fault.
The exact source geometry, measurements and CAD operations are included.

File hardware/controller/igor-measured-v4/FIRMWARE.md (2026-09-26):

# Controller firmware migration

This revision defines the **new controller hardware**. The existing
`apps/controller` application, overlays, UF2 images, reset gesture and build
instructions still describe the nRF52840 controller. They are not ESP32-S3
firmware. Igor's upstream D1-mini timer sketch is also not a Little On Air
controller and must not be treated as the new firmware.

The implementation is now available in
[apps/controller-esp32s3](../../../apps/controller-esp32s3/README.md). The assembled
controller has passed local USB, display and input checks; receiver integration
remains to be tested. See the [bench record](../../../docs/ESP32S3_BENCH.md).

## Intended local interaction

- Boot from computer USB, show **Connecting**, then read the receiver's
  authoritative state. Boot never advances or sends a state.
- Turn the encoder to choose **Off → Warn → On Air → Okay**. Rotation previews
  a selection; it does not change the receiver.
- Press once to send the selected state. Show **Sending** until the exact
  transaction/status acknowledgment arrives.
- Show **Confirmed** and a solid matching pixel only after the receiver's
  persisted/applied acknowledgment. The OLED labels also convey the status.
- On timeout, show the failure and reconcile with a read. Keep the last
  confirmed state visibly distinct from the pending selection.
- Pair through a deliberate on-screen action and the receiver's existing
  physical pairing window. Require an additional confirmation before erasing
  a bond; pressing or holding the encoder during boot must not erase it.
- Dim or blank the OLED after inactivity to reduce static-image wear. Wake on
  interaction while keeping the receiver's status unchanged.

## Implementation boundary

Retain the existing encrypted, bonded BLE central/peripheral relationship and
six-byte version-1 protocol. **ESP-NOW is not compatible with the existing
nRF52840 receiver.** Keep its service/characteristic UUIDs, little-endian
transaction IDs, indication subscription, exact-ack matching and recovery
semantics from `docs/ARCHITECTURE.md`.

The ESP32-S3 implementation and its acceptance testing must provide:

1. Its own supported board configuration and flash format, USB diagnostics,
   GPIO encoder debounce, an I2C driver matched to the actual display controller
   and resolution, and a NeoPixel output driver.
2. Event-driven input during runtime instead of the nRF reset-pin boot action
   and terminal `sleep_forever()` lifecycle. Retain responsive input/rendering
   while BLE operations run.
3. Bond/state storage on ESP32 flash. Remove nRF-only `RESETREAS`, UICR,
   GPREGRET2, nRF PWM and battery-current assumptions from that application.
4. A reviewed pairing and factory-reset UI, display error states, brightness
   limit, encoder direction check, and a bounded reconnect policy.
5. A real ESP32-S3 build plus bench tests against the existing receiver for
   first pairing, command acknowledgment, lost indications, reboot, USB power
   loss, peer replacement and input bounce.

The reusable protocol and state-machine code can remain shared. Add a
controller-specific board/output layer rather than switching the receiver's
board or changing the established wire protocol.

Revision 4 uses the measured Adafruit mini-strip segment. Its exact SKU and
color order are not established; verify red, green and blue individually.

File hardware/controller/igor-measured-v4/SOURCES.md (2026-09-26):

# Source geometry and references

Retrieved 2026-09-14 (local date).

## Exact Project IGOR basis

- Requested model: [Printables 1019283 — Project IGOR](https://www.printables.com/model/1019283-project-igor-open-source-offline-loyal-cheerful-fo).
- Creator: **UrbanCircles / Peter**.
- Creator-maintained repository: [UrbanCircles/igor](https://github.com/UrbanCircles/igor).
- Pinned commit: `7543085fe11f102f121f08aabd8f6c25c38bdf60`.
- Original STEP path: `3D Parts/Project IGOR v1 - shell, faceplate, basic hat (STEP).step`.
- Original 3MF path: `3D Parts/Project IGOR v1 - shell, faceplate, basic hat.3mf`.
- The STEP is copied byte-for-byte to `upstream/igor-v1.step`; SHA-256:
  `9645738bee23f74ca35bc64abd22047e27ce61a9ba0c0e83864a13e755bd8c33`.
- The original 3MF and repository MIT license are included alongside it.

Printables did not return the model page to the research fetcher. The original
geometry was obtained from the author's public repository, whose README describes
Igor's components and assembly. This remix does not use a traced
picture, unrelated enclosure or reconstructed approximation of Igor.

The creator's generic OLED description does not uniquely identify a PCB.
Revision 4 instead uses the user's measured module. Its larger active area
requires an enlarged window, and edge guides replace the original mounting pegs.

## XIAO board reference

- [Seeed getting-started page and mechanical downloads](https://wiki.seeedstudio.com/xiao_esp32s3_getting_started/).
- [Manufacturer 3D-model ZIP](https://files.seeedstudio.com/wiki/SeeedStudio-XIAO-ESP32S3/res/seeed-studio-xiao-esp32s3-3d_model.zip).
- `XIAO-ESP32S3 v2.step` is stored locally as `reference/xiao-esp32s3-seeed.step`
  for fit checks. It is manufacturer reference data, not an original Little
  On Air design. SHA-256:
  `870ad45c7af5d92324cec4c6ae65fbf86e3b049d5a97ab9ffd9039ebd73455dd`.

## Electrical references

- [Seeed pin map and USB power](https://wiki.seeedstudio.com/xiao_esp32s3_getting_started/).
- [TI SN74AHCT1G125](https://www.ti.com/product/SN74AHCT1G125).
- [Adafruit NeoPixel level shifting](https://learn.adafruit.com/adafruit-neopixel-uberguide/logic-level).

The user supplied the weight, encoder, OLED and mini-strip measurements stored
in `MEASUREMENTS.json`. Two 20 × 33.5 × 6.5 mm weights fit; their height includes
the supplied foam adhesive. Weight mass was not specified.

## Corrected orientation and measured front pixel (revision 4)

The broad bottom face and encoder mount are parallel in the exact source.
The assembly is rotated -30° about X into its desk frame before editing.
The base, encoder-plane and rear-wall normals are checked in CAD. Revisions
1 and 2 used an incorrect desk orientation and are superseded.

The LED is the user's 17.6 × 5 × 1.4 mm Adafruit mini-strip segment, behind a
separate transparent PETG diffuser. [Adafruit's strip guide](https://learn.adafruit.com/adafruit-neopixel-uberguide/neopixel-strips)
describes 5 mm Mini Skinny strips; it does not uniquely identify the user's SKU.
The measured envelope drives this model, not a substituted through-hole LED.
The user confirmed that the encoder's 5.4 mm measurement is along the flat
face of its D shaft. Sources and measurements updated 2026-09-15.

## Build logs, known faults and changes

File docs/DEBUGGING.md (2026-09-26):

# USB diagnostics for the current pair

The ESP32-S3 controller always exposes native USB serial diagnostics at 115200
baud. The normal nRF52840 receiver disables USB/logging; its optional diagnostic
configuration enables CDC without changing the current pixel configuration.
There is no nRF52840 controller debug target.

## Controller

```sh
python -m platformio device list
python tools/controller_serial.py --port COM4 --command status
python tools/controller_serial.py --port COM4 --command sync
```

Replace the example port. `status` inspects local state; `sync` reads the sign.
`help` lists the full command set. `send`, `pair` and `pixel` commands act on
hardware; use them as deliberate bench actions. The script sets serial control
lines before opening the port to avoid resetting the controller while observing.

## Receiver

From the repository root in a configured west workspace:

```sh
west build -b xiao_ble/nrf52840 apps/receiver -d build/receiver-debug -- \
  -DEXTRA_CONF_FILE=debug.conf \
  -DEXTRA_DTC_OVERLAY_FILE="$PWD/boards/xiao_ble_nrf52840_debug.overlay"
```

Flash the diagnostic UF2 using [FLASHING.md](FLASHING.md). Receiver USB requires
POWER OFF / PROGRAM and charger USB unplugged. That isolates battery/pixel paths;
a USB log capture is not evidence of normal battery/RUN optical behavior.

Receiver commands are `status`, `pair-reset`, `reboot` and `bootloader`. The last
three change device state. `pair-reset` stores reset intent before rebooting;
`bootloader` deliberately enters factory update mode.

## Reconnecting log capture

```sh
python -m pip install pyserial
python tools/tail_serial.py --duration 60
```

The tailer follows the current identities: ESP32-S3 native USB `303A:1001` as
CTRL and Zephyr receiver debug `2FE3:0006` as RECV. Keep only the intended boards
connected. It reconnects after USB resets and preserves ANSI-free log text.

For physical paired runs, leave receiver USB unplugged and capture from the
controller using `tools/paired_bench.py`. See the [developer guide](../CONTRIBUTING.md#diagnostics-and-bench-work).
After servicing, restore the normal receiver image before power measurements.
Record image hashes, source revision, power arrangement and actual observations.

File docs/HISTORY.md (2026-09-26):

# Firmware history and current support

This is a bespoke pair, not a family of supported firmware products. Current
code builds only the ESP32-S3 OLED/encoder controller and the four-pixel
nRF52840 receiver. Its USB diagnostic configuration remains a service tool for
that same receiver.

The last complete tree before firmware retirement is
[`04879443b3f015cbfd0007984686a501a69c5e85`](https://github.com/sayhiben/little-on-air/tree/04879443b3f015cbfd0007984686a501a69c5e85).
Use a separate checkout of that revision to inspect old firmware; do not copy
retired build targets back into the active tree as a compatibility layer.

Removed from active development:

- nRF52840 reset-button controller application, BLE client and debug target.
- Its portable controller state machine, status/error/pairing blink patterns and
  tests specific to those retired implementations.
- Onboard-only and 4 MHz/5-bit receiver build alternatives, optional pixel
  fragments and the runtime/build switches that selected them.
- Legacy firmware CI/release targets and dual-nRF USB identity handling.

Receiver output/scheduling code now lives with the receiver application, and
host test configuration for both current devices is under `tests/host/`. The
current 8 MHz/10-bit, 375 ns padded pixel stream is the receiver default.
Protocol validation, durable state, explicit pairing recovery, bootloader
recovery and current-device failure-path tests remain in active code.

## Dated evidence

These records retain observations and image hashes from their original builds.
Their historical commands may refer to retired files; use the current
[developer guide](../CONTRIBUTING.md) for builds and [FLASHING.md](FLASHING.md)
for updates.

- [Initial ESP32-S3 bench work](ESP32S3_BENCH.md)
- [Paired-device bench work](PAIRED_BENCH.md)
- [Initial padded-pixel experiment](PIXEL_TIMING_BUILD.md)
- [375 ns timing selection](PIXEL_TIMING_375NS_BUILD.md)
- [Buddy UI and six moods](BUDDY_UPDATE.md)
- [Pairing and independent power light](PAIRING_POWER_UPDATE.md)

Hardware archives, historical manufacturing ZIPs/checksums and preserved local
firmware/bench records are retained. Old firmware embedded in a manufacturing
snapshot records its provenance; it is not the firmware to install today.

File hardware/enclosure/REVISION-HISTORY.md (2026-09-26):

# Little On Air enclosure

**Current case: [v2.15](../../release/little-on-air-enclosure-v2.15/README.md).**
The user retained the case with open-backed frame channels and selected it again
on September 26, 2026. Its original housing and yoke are current along with the
frame. See [the current enclosure guide](README.md).

## Historical v2.16 — rearward LED wiring

The preserved [v2.16 release](../../release/little-on-air-enclosure-v2.16/README.md) changed **05 rear housing and 06 electronics yoke**, reusing the v2.15 front and all other parts. Shallow housing reliefs, reinforced open yoke grooves and one relocated charger contact let separate LED leads turn rearward behind the optical mounts. The [upgrade project](../../release/little-on-air-enclosure-v2.16/bambu-studio/on-air-v216-X1C-upgrade-parts.3mf) prints both parts in black PLA+, about 3 h 06 min / 40.51 g, without supports. Its recorded checks cover all 12 modeled wire paths, their 66 pairwise separations, rigid assembly and both sliced projects; actual pad exits, solder and print fit remain physical checks. This revision is archived rather than selected for the current case.

## v2.15 and v2.14 — wider perimeter wire channels

[v2.14](../../release/little-on-air-enclosure-v2.14/README.md) widened the front to 129 × 69 mm and added perimeter passages. Their roofs failed the user's physical bridge print. [v2.15](../../release/little-on-air-enclosure-v2.15/README.md) opened those channels toward the rear, retaining the other parts. The complete v2.15 case is the current selection.

## Historical v2.13 complete Bambu Studio project

Use the [single four-plate v2.13 project](../archive/enclosure/output/on-air-v213-complete-print/on-air-v213-X1C-all-plates.3mf) for a complete print: black PLA+ enclosure and retainers, black/white PLA+ display backing, and transparent PETG guides. It contains ten production pieces, including the new captive front guide and rear keeper, with no extra fit-size sets. All four plates are sliced and validated. See the [plate and filament guide](../archive/enclosure/output/on-air-v213-complete-print/README.md) for material mapping and the shared first-layer settings. Estimated total: 6 h 14 min / 71.65 g.

## v2.13 — captive light guides

Use the [v2.13 retention package](../archive/enclosure/output/on-air-v213-captive-light-guides.zip). The front guide has an internal collar captured by the frame and existing yoke; one rigid keeper secures both rear guides in keyed seats. Replace **01 front frame, 05 rear housing and 08 front guide**, and add **11 rear guide keeper** with one additional **M3×8 button-head screw and M3 nut**. Existing short rear guides may be reused if they fit freely. The clear-PETG plate now contains exactly **one front and two rear guides**, with no alternate-size copies. Structural parts have a separate PLA+ or PETG plate; only keeper 11 uses automatic support. The wider bevels and all four seam corrections are included. See the [assembly and printing instructions](../archive/enclosure/output/on-air-v213-captive-light-guides/README.md).

## Previous front revision: v2.12 — complete perimeter cleanup

The [v2.12 front package](../archive/enclosure/output/on-air-v212-clean-perimeter-front.zip) closes the fourth legacy notch on the upper right side, while retaining the three top closures and wider bevels. Replace **part 01 only**. An exact perimeter audit covers all four sides and four rounded corners; all pass after correction. Assembly-motion, wiring, mesh and slicing checks also pass. [PLA+](../archive/enclosure/output/on-air-v212-clean-perimeter-front/bambu-studio/on-air-v212-X1C-eSUN-PLA-plus-clean-perimeter-front.3mf) and [PETG](../archive/enclosure/output/on-air-v212-clean-perimeter-front/bambu-studio/on-air-v212-X1C-PETG-clean-perimeter-front.3mf) projects take about 1 h 10 min. See the [revision instructions](../archive/enclosure/output/on-air-v212-clean-perimeter-front/README.md).

## Previous front revision: v2.11 — clean top seam

The [v2.11 front package](../archive/enclosure/output/on-air-v211-clean-top-front.zip) closes three obsolete top-edge notches while retaining the wider v2.10 bevels. Replace **part 01 only**. The existing assembly and light guides remain compatible; the normal 0.15 mm retainer seam clearance is preserved. [PLA+](../archive/enclosure/output/on-air-v211-clean-top-front/bambu-studio/on-air-v211-X1C-eSUN-PLA-plus-clean-top-front.3mf) and [PETG](../archive/enclosure/output/on-air-v211-clean-top-front/bambu-studio/on-air-v211-X1C-PETG-clean-top-front.3mf) projects contain the replacement front, about 1 h 10 min. Native assembly-path, wire-clearance, mesh and slicing checks pass. See the [revision instructions](../archive/enclosure/output/on-air-v211-clean-top-front/README.md).

## Previous front revision: v2.10 — broader bevels

The [v2.10 front package](../archive/enclosure/output/on-air-v210-beveled-front.zip) broadens the outer bevel to **1.4 mm** and the display-opening bevel to **0.8 mm**, both 45°. Replace **part 01 only**; keep the v2.8 assembly and light guides. [PLA+](../archive/enclosure/output/on-air-v210-beveled-front/bambu-studio/on-air-v210-X1C-eSUN-PLA-plus-beveled-front.3mf) and [PETG](../archive/enclosure/output/on-air-v210-beveled-front/bambu-studio/on-air-v210-X1C-PETG-beveled-front.3mf) projects pass slicing checks, approximately 1 h 10 min. The acrylic seat, controls and screw recesses remain unchanged. See the [revision instructions](../archive/enclosure/output/on-air-v210-beveled-front/README.md).

## Previous front revision: v2.9 — subtle bevel

Use the [beveled front package](../archive/enclosure/output/on-air-v29-beveled-front.zip) to replace **part 01 only**. The front has a 0.8 mm outer bevel and a 0.4 mm display-opening bevel, both 45°. [PLA+](../archive/enclosure/output/on-air-v29-beveled-front/bambu-studio/on-air-v29-X1C-eSUN-PLA-plus-beveled-front.3mf) and [PETG](../archive/enclosure/output/on-air-v29-beveled-front/bambu-studio/on-air-v29-X1C-PETG-beveled-front.3mf) projects are sliced and validated, about 1 h 10 min each. Keep the v2.8 housing, optical parts, hardware and light guides. The acrylic seat, controls and screw recesses are unchanged. See the [revision instructions](../archive/enclosure/output/on-air-v29-beveled-front/README.md).

## Previous v2.8 light guides — friction retention, superseded

The v2.13 package above replaces this friction-retained design. Its main optical plate has three required parts; the historical plate below has nine pieces because it includes three fit-size sets. The old exterior-collared front guide is not compatible with the new captive front pocket.

The [light-guide package](../archive/enclosure/output/on-air-v28-light-pipes.zip) adds one front RGB guide and two rear charger guides, with no enclosure reprint. Its [Bambu Studio plate](../archive/enclosure/output/on-air-v28-light-pipes/bambu-studio/on-air-v28-clear-PETG-light-pipes.3mf) contains three complete fit choices (2.95, 3.05 and 3.15 mm shafts), lying flat with verified lengthwise fill. Approximately 29 minutes / 0.98 g. See the [fit and installation instructions](../archive/enclosure/output/on-air-v28-light-pipes/README.md); retention is a close friction fit with stop collars, so physical fit and brightness still need checking.

## Base fabrication release: v2.8 — charger corner contact and reset travel

Use the [v2.8 fabrication package](../archive/enclosure/output/on-air-v28-fabrication.zip) and [two-part eSUN PLA+ fit plate](../archive/enclosure/output/on-air-v28-fabrication/bambu-studio/on-air-v28-X1C-eSUN-PLA-plus-fit-checks.3mf). Bambu Studio estimates **1 h 22 min / 22.40 g**. The fit plate contains revised upper rear section 99 and button 07; reuse the v2.7 upper front sample 91 and keeper 06.

Only production parts **05 rear housing and 07 reset button** change. The charger's lower stop is now the full 17.5 mm board width, reaching both corner feet around its center indentation. Reducing the collar thickness by 0.20 mm increases available reset travel from 0.60 to 0.80 mm, while preserving its resting tip position and guide fit. Case dimensions, other printed parts, wiring and laser SVGs remain unchanged.

Native assembly, wiring, mesh and slicing checks pass. The earlier simplified CAD reset target did not predict the physical contact position, so verify a light click and full release on the fit sample before printing the full rear housing. See the [revision notes](../archive/enclosure/output/on-air-v28-fabrication/REVISION-NOTES.md), [assembly guide](../archive/enclosure/output/on-air-v28-fabrication/BUILD-AND-ASSEMBLY.md) and [validation record](../archive/enclosure/output/on-air-v28-fabrication/VALIDATION.md). No print or laser job was sent.

## Previous fabrication release: v2.7 — parallel PCBs and slim case

Use the [v2.7 fabrication package](../archive/enclosure/output/on-air-v27-fabrication.zip) and [four-part eSUN PLA+ fit plate](../archive/enclosure/output/on-air-v27-fabrication/bambu-studio/on-air-v27-X1C-eSUN-PLA-plus-fit-checks.3mf). The body is **120 × 60 × 24 mm**, down from 34 mm, and **26.5 mm** including the front reset button. Bambu Studio estimates **2 h 8 min / 34.25 g** for the fit plate. Replace **01, 05, 06 and 07 together** after testing.

Both PCBs now lie parallel to the display, with top USB ports and direct front insertion. XIAO faces forward for a deeply guided front-frame reset button and RGB viewing hole; the charger faces backward for its rear LED holes. Short end supports replace the tall XIAO cage. All eight screws remain M3×8 button heads; the upper-right closure screw moves to the corner. Acrylic, graphic backing and optical retainer remain compatible.

Read the [revision notes](../archive/enclosure/output/on-air-v27-fabrication/REVISION-NOTES.md), [assembly guide](../archive/enclosure/output/on-air-v27-fabrication/BUILD-AND-ASSEMBLY.md) and [validation record](../archive/enclosure/output/on-air-v27-fabrication/VALIDATION.md). Native assembly motions, solder access, hardware,45 wiring/bay checks,120 route-pair checks,18 meshes and nine slicing projects pass. First-layer inspection stays disabled. Only the button uses automatic support. The next check is the physical fit plate; no fabrication has been started.

## Previous fabrication release: v2.6 — common screws and service access

Use the [v2.6 fabrication package](../archive/enclosure/output/on-air-v26-fabrication.zip) and [four-part eSUN PLA+ fit plate](../archive/enclosure/output/on-air-v26-fabrication/bambu-studio/on-air-v26-X1C-eSUN-PLA-plus-fit-checks.3mf). Bambu Studio's estimate is **2 h 45 min / 46.07 g**. Replace **01 bezel, 05 rear housing, 06 yoke and 07 reset button** together after testing. All eight screws are now **M3×8 button heads**, with recessed heads and captive nuts.

The charger flips to expose its indicators through two rear holes. The XIAO gains an RGB sight aperture, moves 2 mm inward, and has open pad-edge channels, an underside power-wire opening and a removable lower clamp. Both bare-board and pre-soldered insertion paths are checked. The MODE pocket is 0.3 mm narrower overall and retains the measured switch with 0.15 mm total depth clearance.

Read the [revision notes](../archive/enclosure/output/on-air-v26-fabrication/REVISION-NOTES.md), [assembly guide](../archive/enclosure/output/on-air-v26-fabrication/BUILD-AND-ASSEMBLY.md) and [validation record](../archive/enclosure/output/on-air-v26-fabrication/VALIDATION.md). The acrylic, graphic and optical retainer remain compatible. First-layer inspection stays disabled. Only the button uses automatic support. No physical fabrication was started.

## Previous fabrication release: v2.5 — third physical-fit revision

Use the [v2.5 fabrication package](../archive/enclosure/output/on-air-v25-fabrication.zip) and [combined fit plate](../archive/enclosure/output/on-air-v25-fabrication/bambu-studio/on-air-v25-X1C-eSUN-PLA-plus-fit-checks.3mf). Replace **05 rear housing, 06 yoke and 07 reset button** together after testing the sample. This revision turns the blocked upper-left nut entry, centers the XIAO USB opening on the measured 1.2 mm PCB, lengthens the reset tip and outside stem, clears the DPDT terminals with end supports, closes the POWER roof gap and moves the charger feet away from the OUT solder pads.

Load nuts first. Install the button with its end held **9 mm inward**, then slide it outward. Insert the XIAO **8 mm low**, slide it upward into the USB opening and install the yoke. See the [revision notes](../archive/enclosure/output/on-air-v25-fabrication/REVISION-NOTES.md), [build instructions](../archive/enclosure/output/on-air-v25-fabrication/BUILD-AND-ASSEMBLY.md) and [validation record](../archive/enclosure/output/on-air-v25-fabrication/VALIDATION.md). The optical parts and laser artwork are unchanged. First-layer inspection stays disabled; the housing and yoke use no automatic support. The new fits require the next physical sample.

## Previous fabrication release: v2.4 — second physical-fit revision

Use the [v2.4 fabrication package](../archive/enclosure/output/on-air-v24-fabrication.zip) and [start here](../archive/enclosure/output/on-air-v24-fabrication/START-HERE.md). Begin with the [eSUN PLA+ combined fit plate](../archive/enclosure/output/on-air-v24-fabrication/bambu-studio/on-air-v24-X1C-eSUN-PLA-plus-fit-checks.3mf). It contains the continuous upper housing section, complete yoke and reset button, so the corner and mount reinforcement are tested together. First-layer inspection remains disabled.

Replace **05 rear housing, 06 electronics yoke and 07 reset button** together. This revision adds six angled pill vents, reinforces the XIAO corner and yoke, clears the seated USB socket and button travel, enlarges the MODE mount to the newly measured DPDT body and legs, and reinforces the successful POWER mount. The housing and yoke print without automatic support; only the small reset button uses support.

**Install the reset button first. Then insert the XIAO 8 mm below its final position and slide it upward 8 mm into the USB opening. Install the yoke afterward.** The removable yoke supplies the lower board stop and button travel stop. Leave wire slack for the board movement. See the [revision notes](../archive/enclosure/output/on-air-v24-fabrication/REVISION-NOTES.md), [build instructions](../archive/enclosure/output/on-air-v24-fabrication/BUILD-AND-ASSEMBLY.md) and [validation record](../archive/enclosure/output/on-air-v24-fabrication/VALIDATION.md). The optical parts and laser artwork are unchanged. Physical fit and strength still require the new sample print.

## Previous fabrication release: v2.3 — measured fits

Use the [v2.3 fabrication package](../archive/enclosure/output/on-air-v23-fabrication.zip) and [start here](../archive/enclosure/output/on-air-v23-fabrication/START-HERE.md). Begin with the [eSUN PLA+ fit plate](../archive/enclosure/output/on-air-v23-fabrication/bambu-studio/on-air-v23-X1C-eSUN-PLA-plus-fit-checks.3mf), which retains the inspection-off setting that allowed the previous print to finish.

Replace **05 rear housing, 06 electronics yoke and 07 reset button** together. Omit the old printed DPDT slider (08); the switch's own actuator is now exposed. The revised housing uses the measured charger and SPDT sizes, closer-fitting measured USB openings, and a braced XIAO frame. The reset button has a keyed stem, rounded cap, roughly 5 mm guide and positive travel stop. See the [change record](../archive/enclosure/output/on-air-v23-fabrication/REVISION-NOTES.md) and [assembly instructions](../archive/enclosure/output/on-air-v23-fabrication/BUILD-AND-ASSEMBLY.md).

The XIAO now inserts from the front **8 mm below its final position, then slides up 8 mm** into the port; the yoke supplies the removable lower stop. Leave wire slack for this movement. Fit the reset button before tightening the yoke, and verify free return as the screws are seated.

The six-piece fit plate checks only the four revised mount sections, complete yoke and new reset button. The full release includes six printed assembly parts, separate STLs, nine material/filament-change Bambu projects, Fusion and STEP archives, unchanged laser artwork, updated BOM and wiring layout. Native and slicing validation are recorded in [VALIDATION.md](../archive/enclosure/output/on-air-v23-fabrication/VALIDATION.md). Physical acceptance of these new fits requires the next coupon print. The original v2.2 files remain below for history.

## Previous fabrication release: v2.2 — two switches

The user confirmed that the separate [inspection-off recovery project](../archive/enclosure/output/on-air-v22-first-layer-recovery/READ-ME.md) allowed the fit print to complete. The printer's inspection fault itself was not diagnosed or repaired. The original fabrication release and edited source file remain unchanged.

Use the complete [v2.2 fabrication ZIP](../archive/enclosure/output/on-air-v22-fabrication.zip) or [start here](../archive/enclosure/output/on-air-v22-fabrication/START-HERE.md). It includes [assembly and selected two-switch wiring instructions](../archive/enclosure/output/on-air-v22-fabrication/BUILD-AND-ASSEMBLY.md), [separate FDM STLs](../archive/enclosure/output/on-air-v22-fabrication/stl), [LightBurn SVGs](../archive/enclosure/output/on-air-v22-fabrication/laser), and [nine X1C Bambu projects](../archive/enclosure/output/on-air-v22-fabrication/bambu-studio) for PETG, PLA and a clearly labeled PLA+ starting profile.

The design is 120 × 60 × 34 mm, with fixed electronics mounts in the rear housing, a removable retaining yoke, and an independent optical assembly. Revision 2.2 adds the owned SPDT as POWER and retains the tiny DPDT and printed slider as RUN/PROGRAM. Replace parts 05 and 06 together if upgrading a v2.1 print; other main shapes and laser artwork are unchanged. Sample 98 checks the new POWER mount. The editable Fusion archive is [little-on-air-v22.f3d](../archive/enclosure/output/on-air-v22-fabrication/cad/little-on-air-v22.f3d).

Read [the validation record](../archive/enclosure/output/on-air-v22-fabrication/VALIDATION.md). All 18 meshes, 15 assembly/control paths, 40 harness/space checks and nine slicing projects passed; the saved Fusion archive was reimported and checked. Actual component/sheet fits, wiring and thermal behavior require the supplied fit samples and commissioning checks. The SPDT's actual other-axis lever width and travel still need the fit sample. Current receiver firmware drives the onboard RGB LED only; four-pixel NeoPixel output remains an operational step. Use the curated package; `output/v22` contains working exports and logs.

The selected circuit uses direct battery power, the inline resistor/capacitor and user pigtails. LED and capacitor current bypass the tiny DPDT. Before either USB: POWER off, MODE PROGRAM, then connect only the selected USB port. Confirm the charger's current setting against the actual cell rating.

Everything below documents the earlier v1 prototype. Previous v2 and v2.1 packages are retained for history; their alternative wiring instructions are superseded by v2.2.

Native Autodesk Fusion design, built through the local MCP API on port **27182**.
All dimensions and exports use **millimetres**. The front is the XY plane at Z=0;
the rear is at Z=-30. The positive Y edge is the top of the wall-mounted sign.

## Architecture review

The [FDM design review](../archive/enclosure/DESIGN-REVIEW.md) recommends replacing this v1 carrier
architecture with an integrated rear electronics housing and a separate front
optical assembly. Its [illustrated report](../archive/enclosure/output/pdf/on-air-fdm-design-review.pdf)
explains the support-heavy carrier, component retention, control insertion,
acrylic registration and revised parts plan. The older Fusion/STL/3MF files
remain the v1 baseline; the replacement is now implemented in `output/v2/`.
Passing mesh and slicing checks do not resolve those manufacturing findings.

## Fabrication package

The `output` directory contains the Fusion archive, STEP assembly, individual
part meshes, laser artwork, assembly views, and a geometry verification report.
The editable source is `build_enclosure.py`; the local API client is
`fusion_client.py`. Reference electronics are explicitly named `REF` and must
not be printed.

Assembled enclosure in Fusion

This is a **first-fit prototype**, not a dimensionally verified production
enclosure. Physical board heights, soldering envelopes, reset position/travel,
switch throw, and LED emitter alignment still need confirmation. Named Fusion
parameters identify these measurements. The native timeline supports editing
individual sketches and features; changes to the overall layout should be made
in the builder and regenerated so all component positions stay coordinated.

## Parts and materials

| Component | Process | Notes |
| --- | --- | --- |
| 01 Body and front frame | Black PETG | Integrated bezel, LED pockets, four front M3 recesses, top USB openings |
| 02 Engraved acrylic | Clear acrylic, CO2 laser | Nominal 3.175 mm; cut and reverse-engrave the supplied artwork |
| 03 Black and white backing | Black then white PETG | Back down; change filament at 1.6 mm; white lettering is 0.4 mm tall |
| 04 Optical and electronics tray | PETG | Three side latches, LED retaining fingers, battery cradle, board and switch mounts |
| 05 Charger keeper | PETG | U clip with locating legs; back ribs prevent withdrawal |
| 06 XIAO keeper | PETG | Side-inserted fork; case stop prevents withdrawal |
| 07 Captive reset plunger | PETG | Insert from inside before fitting the board |
| 08 Captive power slider | PETG | Insert from inside and engage the DPDT actuator |
| 09 Switch keeper | PETG | Removable terminal-access cover, captured by the back |
| 10 Wall back plate | Black PETG | Flat adhesive surface; internal nut bosses and keeper ribs |

Use a 0.4 mm nozzle and 0.2 mm layers as the starting print setup. Use four
perimeters on structural parts and solid small clips. Inspect the slicer for
bridges, support beneath overhangs, and thin features. Remove support from mating
surfaces before checking fit. The mesh package places parts on Z=0 and includes
recommended print orientations; do not apply those transforms to laser artwork.
The individual-part 3MF files contain geometry only. Configured Bambu Studio
projects, with the printer profile, supports and automatic color change or
manual pause, are in `output/bambu-studio/`; see `PRINT-SETUP.md` there.
When using individual meshes, set the black-to-white change after the 1.6 mm base.

The upper-right fastener is at X=96, Y=54 mm, moved inward to clear the XIAO.
The other fasteners are at (6,6), (114,6), and (6,54) mm, measured from the lower-left
front corner. Hardware heads are recessed by 0.2 mm, and screw tips have 0.5 mm
clearance above a 1.3 mm rear skin. Reference bolts have simplified unthreaded shafts.

Hardware: four M3 x 25 mm socket-head screws and four ordinary M3 hex nuts,
removable adhesive mounting strips, a thin nonconductive battery strap, and thin
perimeter/LED cushioning pads. Confirm the actual screw head and nut dimensions
against the fit coupon before printing the full body.

## Optical stack and artwork

The 100 x 34 mm window exposes a 104 x 38 mm keyed acrylic panel. A chamfered
upper-left corner, viewed from the front, identifies the correct orientation.
The backing uses the same outline. A nominal 0.5 mm air gap separates the rear
engraving from the raised white letters. Do not glue the clear viewing faces
together or coat the light-entry edges.

The two upper and two lower LED modules point into the long acrylic edges.
Their emitting-window centres must align to the middle of the measured acrylic
thickness. The supplied 2 mm module thickness does not determine emitter height;
the current model assumes a 1 mm optical offset from the module's front face.

Use the **rear-face** laser file as supplied: the text and the asymmetric cut
outline are mirrored together. The separate front-view artwork is for alignment
and inspection. Engrave only the text layer; cut only the outline layer. Run an
engraving/edge-coupling sample with the actual acrylic before the full panel.

## Assembly and servicing

1. Solder and insulate the LED leads, with the emitting faces kept clean. Lay the
   four modules into the body pockets; route wires beside the modules.
2. Insert the acrylic from the rear, engraving facing inward. Insert the backing
   with the white lettering toward the acrylic, matching the keyed corner.
3. Install the XIAO and its fork keeper on the loose tray. Insert the reset
   plunger into the body from inside before fitting this tray assembly.
4. Fit the tray assembly, positioning the fork behind the case's withdrawal
   stop. Confirm all three side latches engage and the LED fingers contact
   cushioning pads without bending the LED boards. Verify the reset has no
   preload and adjust its contact tip before repeated presses.
5. Fit the charger and its U keeper. Check both actual USB cables can seat fully
   without moving the boards.
6. Fit the top slider, engage the DPDT actuator, and fit the switch keeper.
   Check both detents and adequate clearance for the six soldered terminals.
7. Install the battery and loose nonconductive strap. Keep solder joints, wire
   ends, and screws clear of the pouch; leave room at the battery lead exit.
8. Load the M3 nuts into the back's internal pockets. Check the internal ribs
   align behind the charger and switch keepers, leaving their small running
   gaps. Fit the back and tighten the four front screws gently until the
   compression posts meet.
9. Apply removable adhesive strips to the flat back, keeping removal tabs
   accessible after the body is detached. Remove the front screws to service
   the sign while the back remains on the wall.

Release the tray before removing the XIAO fork. The charger and switch keepers
can be lifted out after removing the back; their legs locate them while the back
ribs provide positive retention during use. Keep wiring out of the rib paths.

## Measurements and physical acceptance

- Measure actual acrylic thickness (3 mm and 1/8 inch are different).
- Verify each separated LED module including solder fillets and emitter height.
- Verify the charger PCB thickness, underside, components, and USB overhang.
- Verify the XIAO reset centre, actuation direction, safe travel, and bare PCB
  support locations. The reference model is an envelope, not a manufacturer STEP.
- Measure DPDT throw separately from the 1.4 mm actuator height. Tune the slider
  slot and socket if necessary. The six legs have a nominal 3 mm trimmed envelope;
  allow additional space for the actual soldered/insulated assembly.
- Verify mating clearances with small samples before full printing. Start at
  0.25 mm per side; keeper legs and slots require printer-specific adjustment.
- Verify letters are aligned and the four LEDs illuminate red/yellow/green
  acceptably, without strong glare or isolated hotspots.
- Test repeated USB insertion, single and double reset presses, switch operation,
  cable bend clearance against the wall, closed-case charging temperature, and
  BLE operation using the intended electrical circuit.

Firmware and the power circuit are unchanged. The mechanical model does not
validate charger selection, charge current, or isolation between the two USB
power paths.

Exploded Fusion assembly

The exploded view separates the body, acrylic, backing, carrier, controls,
keepers, and back. The electronics are hidden in this view. See
`output/views/electronics-layout.png` for the component arrangement, viewed
from the rear (left and right are reversed relative to the front).

## Reproduction

With Fusion's MCP server running on `127.0.0.1:27182`, use Python 3 and run:

These commands use the repository layout. In the ZIP, scripts are in `source`;
run the equivalent commands there without the `hardware/enclosure/` prefix.

```powershell
python hardware/enclosure/fusion_client.py stage setup
python hardware/enclosure/fusion_client.py stage shell
python hardware/enclosure/fusion_client.py stage optics
python hardware/enclosure/fusion_client.py stage backplate
python hardware/enclosure/fusion_client.py stage tray
python hardware/enclosure/fusion_client.py stage keepers
python hardware/enclosure/fusion_client.py stage controls
python hardware/enclosure/fusion_client.py stage references
python hardware/enclosure/fusion_client.py stage refine
python hardware/enclosure/fusion_client.py run hardware/enclosure/correct_fit.py
python hardware/enclosure/fusion_client.py run hardware/enclosure/mechanical_finish.py
python hardware/enclosure/fusion_client.py run hardware/enclosure/finish_design.py
python hardware/enclosure/fusion_client.py run hardware/enclosure/add_fasteners.py
python hardware/enclosure/fusion_client.py run hardware/enclosure/retention_finish.py
python hardware/enclosure/fusion_client.py run hardware/enclosure/verify_fusion.py
python hardware/enclosure/fusion_client.py run hardware/enclosure/export_fusion.py
python hardware/enclosure/fusion_client.py run hardware/enclosure/capture_views.py
python hardware/enclosure/fusion_client.py run hardware/enclosure/fit_coupons.py
python hardware/enclosure/prepare_prints.py
python hardware/enclosure/package_release.py
```

The setup stage creates a new design. Later stages operate only on a design
marked with the `LittleOnAir` attribute. Do not rerun completed build stages in
the same design; they intentionally create new native features.

Print the small samples in `output/print/90-*`, `91-*`, and `92-*` first. They check
M3 heads/nuts, the LED/acrylic interface, and the reset guide. The fastener sample
is shorter than the case, so a 25 mm screw intentionally extends through it.
Also print the small keepers, plunger and slider before committing to the full
body. The carrier needs support beneath its optical partition and overhangs;
remove that support without damaging the latch leaves or snug sockets.

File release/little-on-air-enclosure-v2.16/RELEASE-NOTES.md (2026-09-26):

# Enclosure v2.16

LED wiring now turns back into the electronics cavity with modeled 3 mm bend radii, behind the optical screw heads and through open mount reliefs. The v2.15 perimeter channels made the pad exits awkward. Clearing the installed upper electronics requires changes to **05 rear housing and 06 electronics yoke**, so those are the only replacement parts. The current front and every other printed/laser-cut part remain byte-identical.

The rear housing loses only 40.22 mm³ at shallow lead clearances beside POWER supports and ahead of MODE's terminal guard. Switch-body seats remain. The yoke gains reinforced rails, an open groove with a 1.95 mm floor, and one relocated charger contact beneath the USB end. That contact keeps its area, height and 0.15 mm nominal board-face clearance; a 45° gusset supports its underside for FDM. All other contact pads, board positions, reset/USB/guide interfaces and the nine M3×8 joints remain.

The planned chain is lower-right → lower-left → upper-left → upper-right, viewed from the front. Verify actual DIN/DOUT labels. H1–H4 use separate flexible wires up to 1.8 mm insulation OD; 2 mm clearance envelopes and 3 mm bends were checked. The service connector sits farther left, and the inline resistor has a bottom-interior bay near the lower-right first pixel. C1 stays in its existing right bay. No electrical components are added.

Twelve modeled runs clear all installed rigid solids and each other (66 pairs). Static and sampled yoke-insertion/front-closure checks pass. Both meshes are watertight single solids; both Bambu projects are re-sliced and audited. Upgrade printing takes about 3 h 06 min / 40.51 g black PLA+, without supports. The full project retains the approved three plates, one keeper, black/white PLA+ insert painting and clear PETG guide orientation/fill. First-layer inspection remains disabled for the prior timeout workaround.

Read [the illustrated installation guide](guides/FRONT-WIRING.md) before soldering and clamping the yoke. Actual LED pad fanout, solder blobs, insulation stiffness and printed fit still need physical checking; this revision has not been printed. Historical compact rear harness paths are reference only and must be dressed clear of the new LED routes. Electrical connections and the earlier bundled firmware snapshot are unchanged. No printer or laser job was sent.

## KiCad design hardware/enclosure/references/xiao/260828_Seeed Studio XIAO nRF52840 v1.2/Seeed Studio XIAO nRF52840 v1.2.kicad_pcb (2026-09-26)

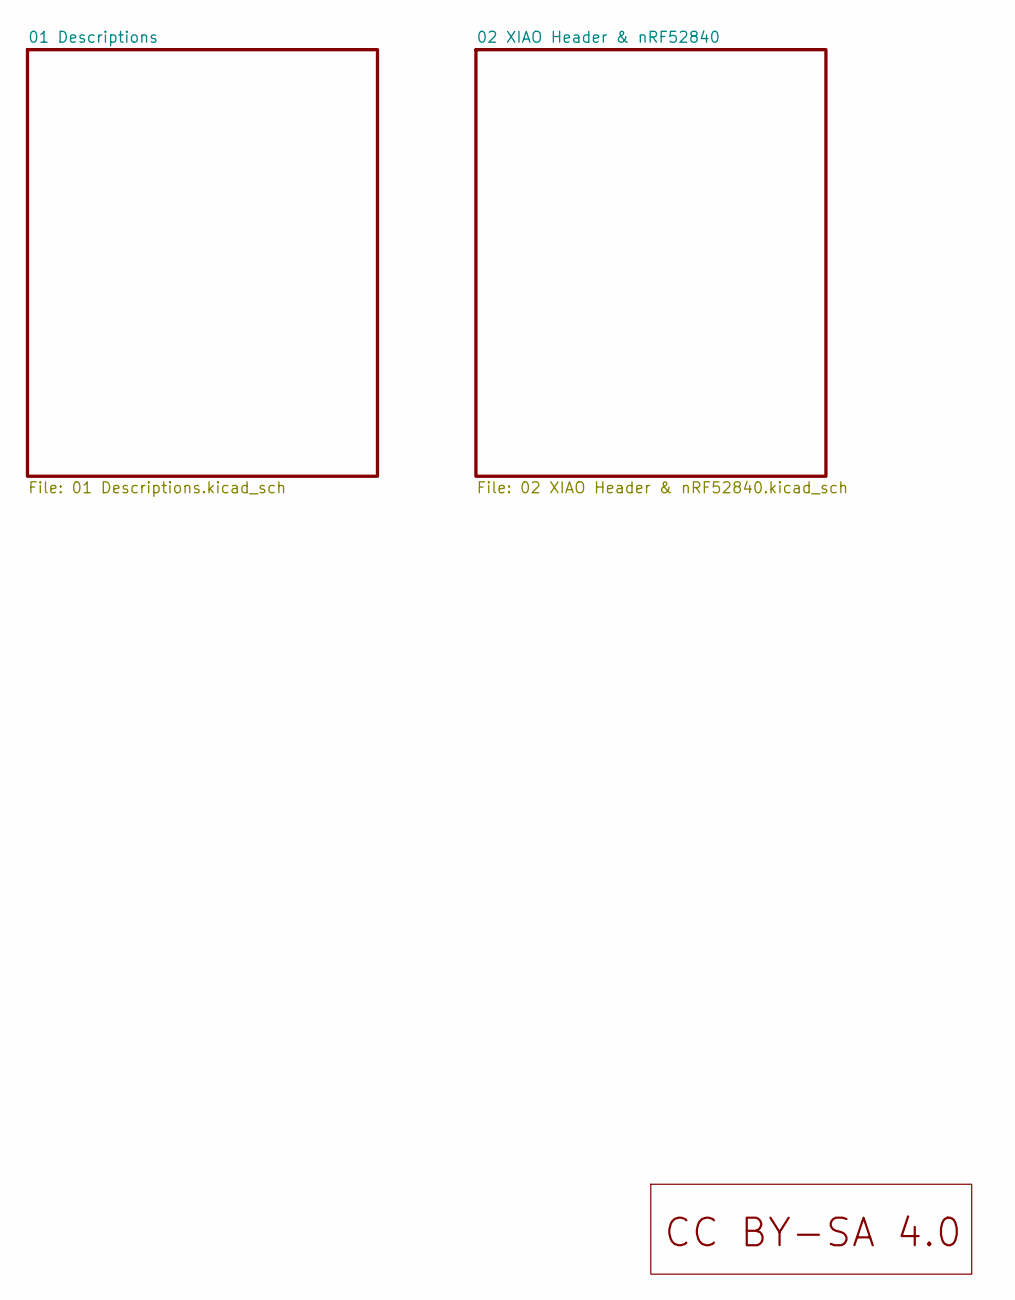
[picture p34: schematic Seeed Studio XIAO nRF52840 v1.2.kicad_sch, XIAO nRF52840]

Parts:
U5: LOGO_CC_BY-SA_4.0

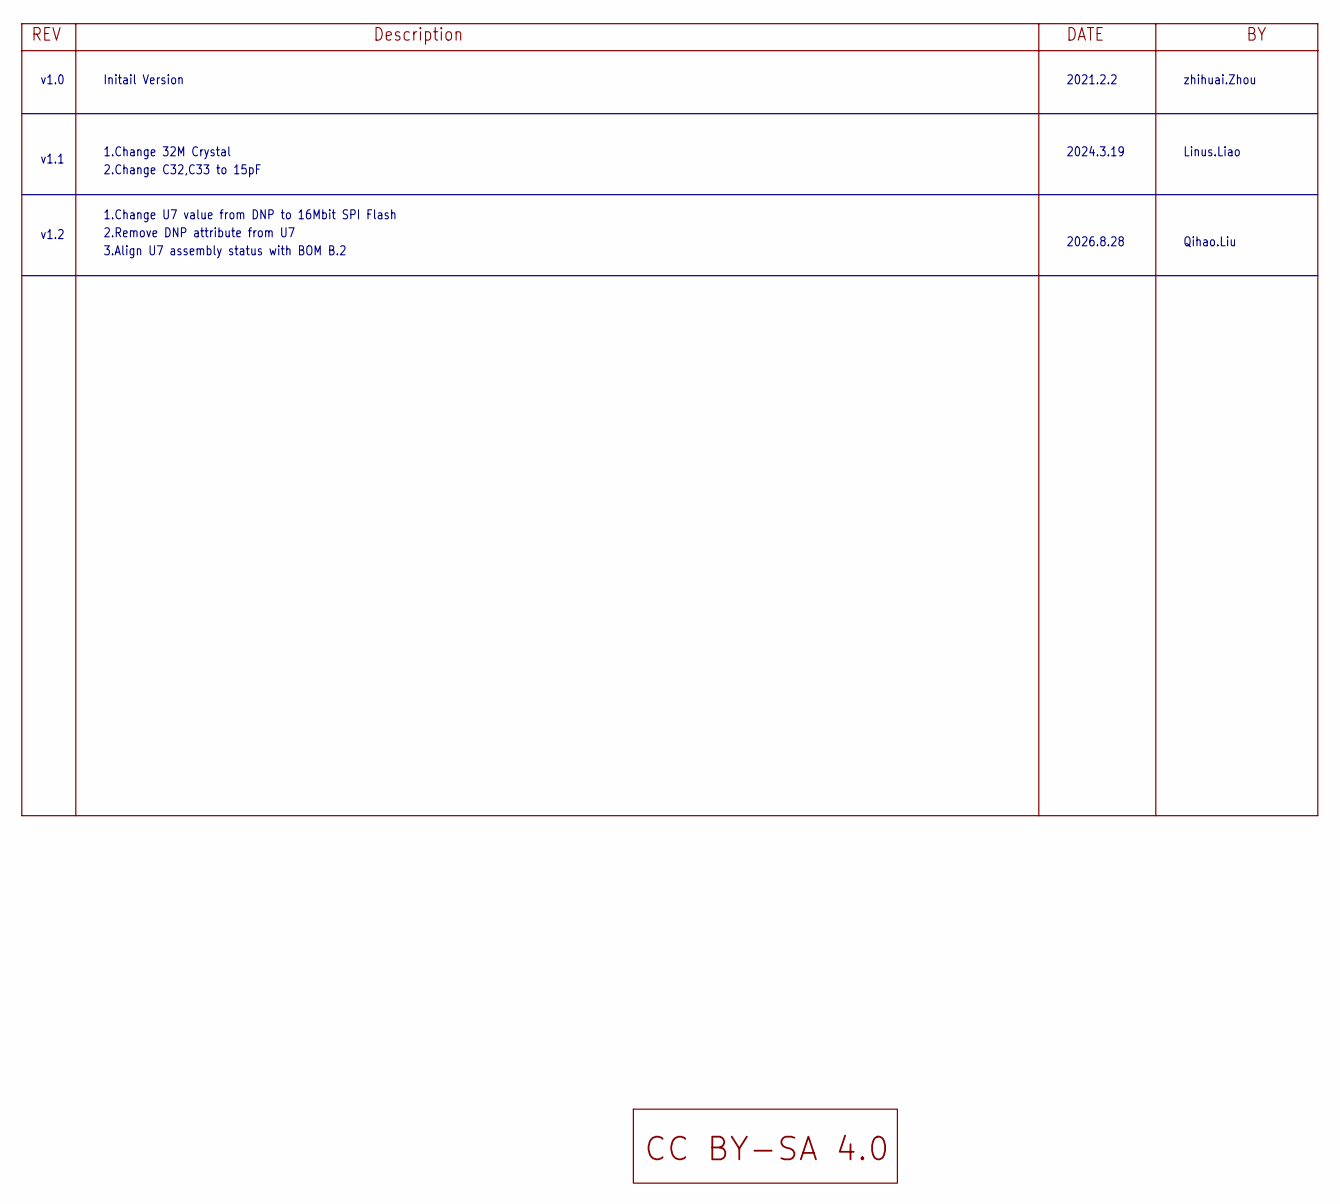
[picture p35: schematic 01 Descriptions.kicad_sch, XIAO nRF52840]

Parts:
U8: LOGO_CC_BY-SA_4.0

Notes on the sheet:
v1.2
zhihuai.Zhou
Linus.Liao
2021.2.2
3.Align U7 assembly status with BOM B.2
v1.0
2.Change C32,C33 to 15pF
1.Change U7 value from DNP to 16Mbit SPI Flash
v1.1
2.Remove DNP attribute from U7
2026.8.28
1.Change 32M Crystal
Qihao.Liu
2024.3.19
Initail Version

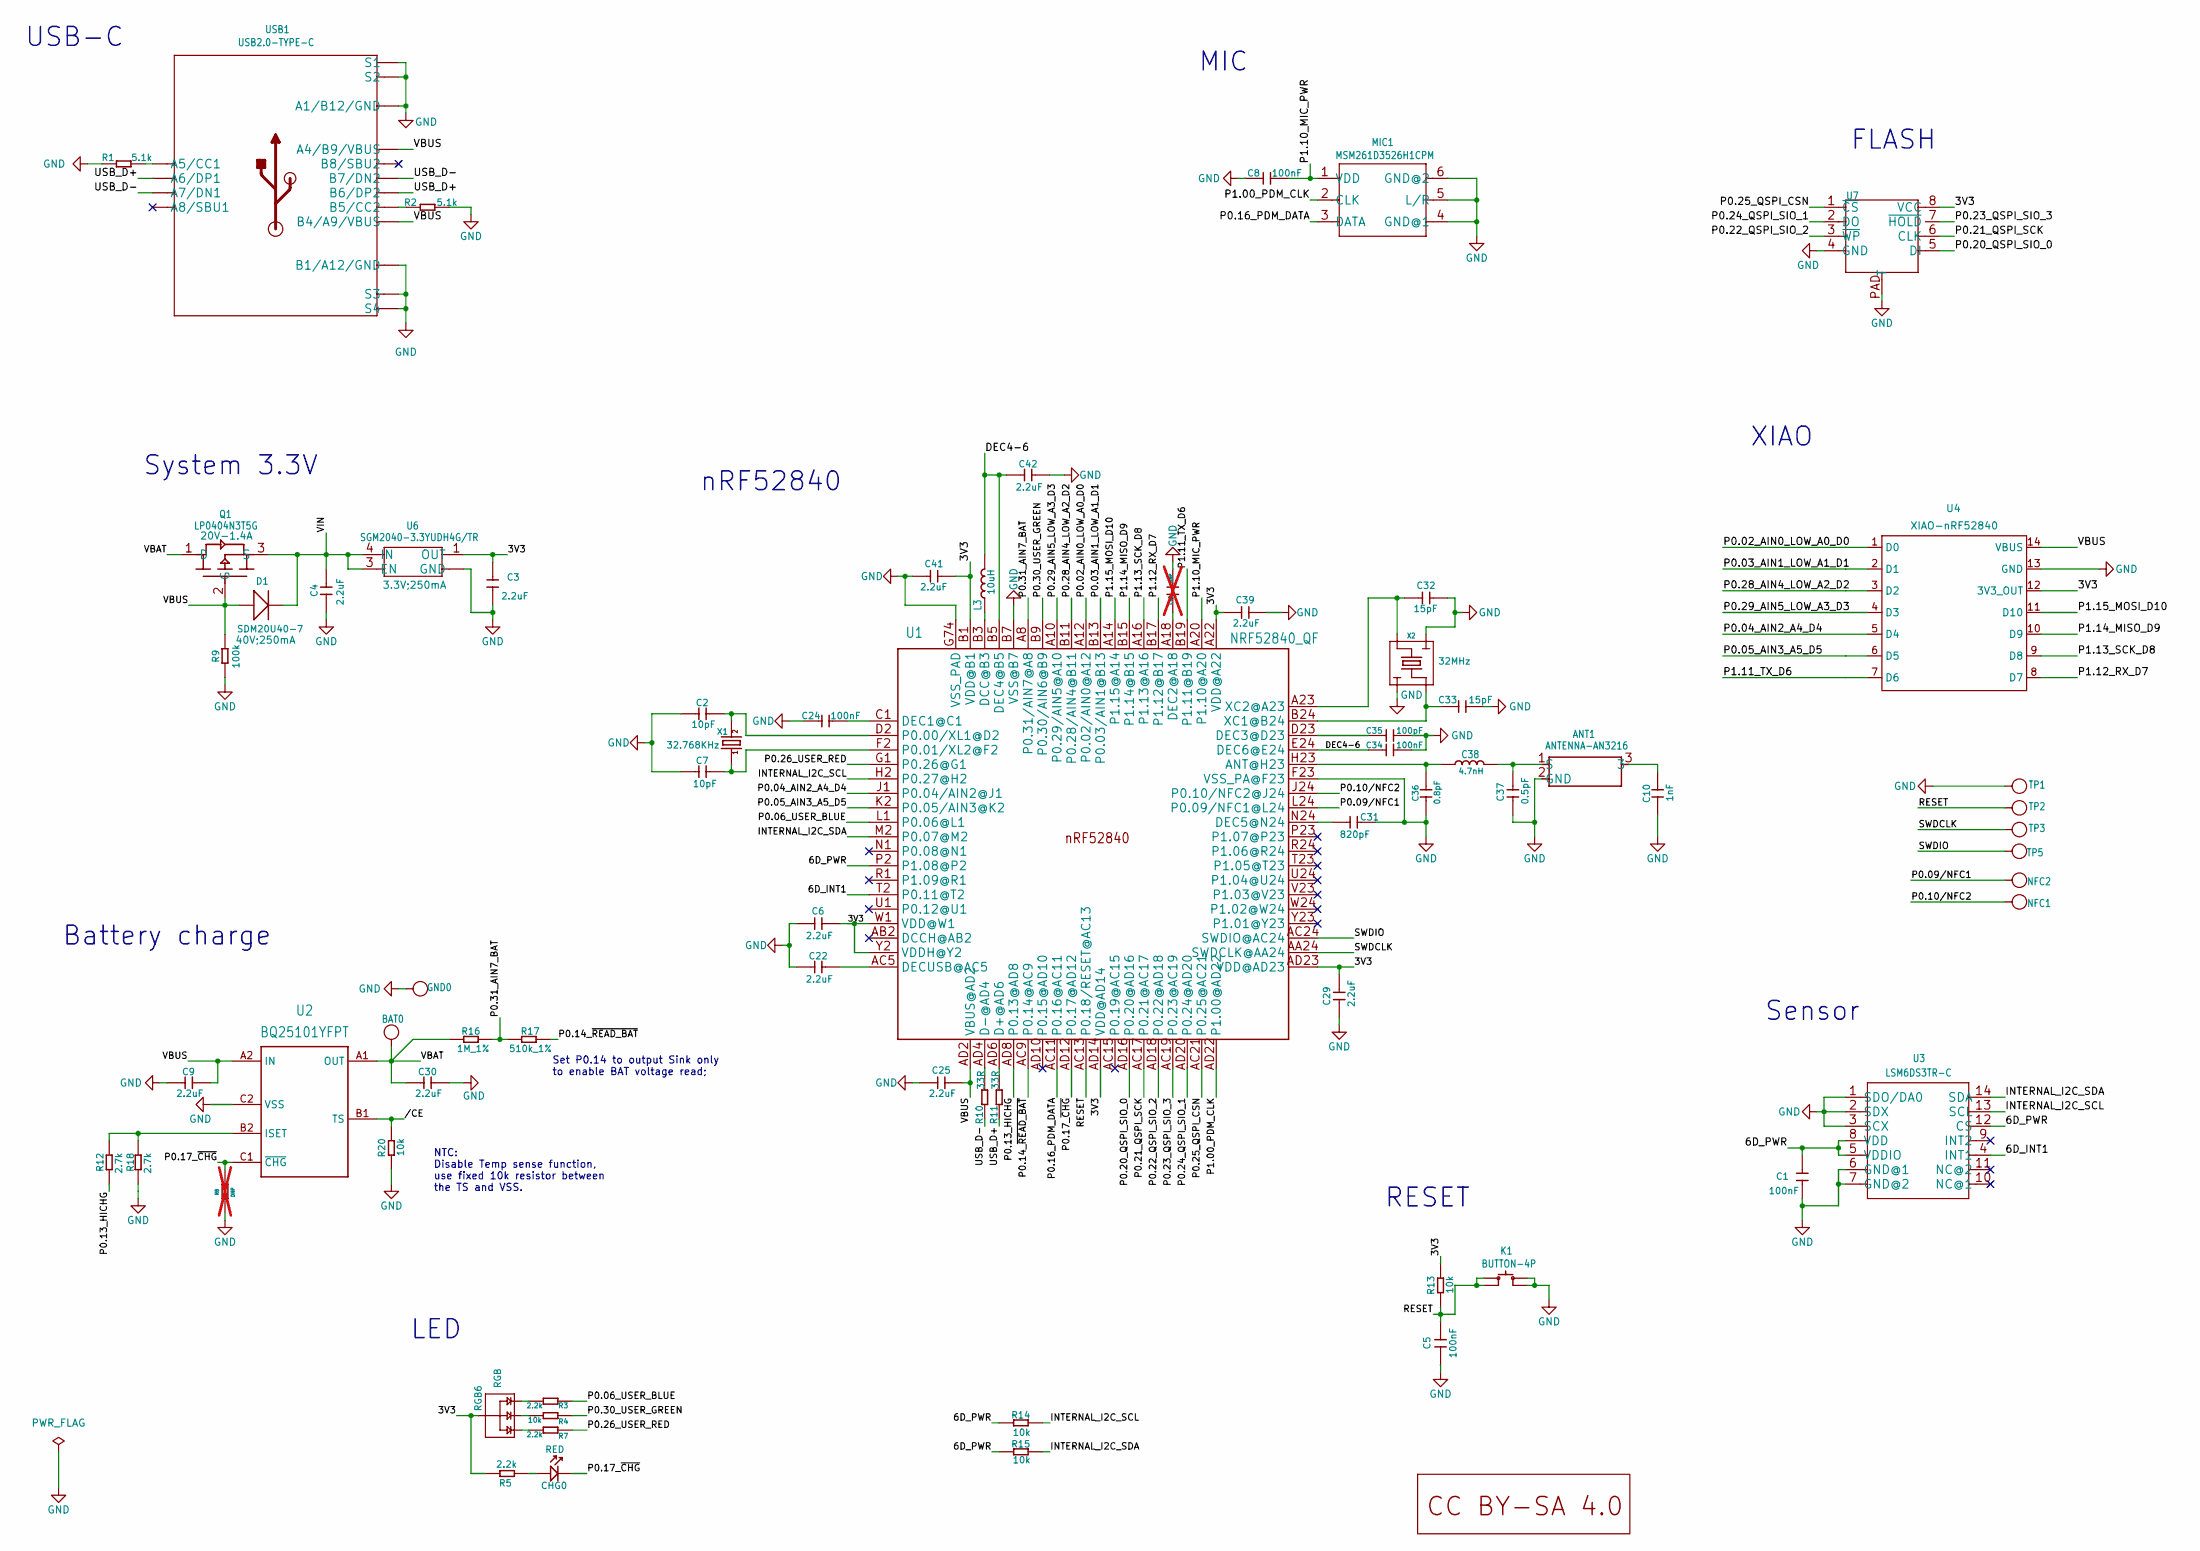
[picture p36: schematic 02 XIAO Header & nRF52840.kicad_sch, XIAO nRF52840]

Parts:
ANT1: ANTENNA-AN3216; ANT-SMD3P-3.2X1.6X1.04MM
BAT0: TEST-POINT'4080'; TP-80X40MIL
C1, C5, C8, C24, C34: 100nF; C0201
C2, C7: 10pF; C0201
C3, C4, C6, C9, C22, C25, C29, C30, C39, C41, C42: 2.2uF; C0201
C10: 1nF; C0402
C31: 820pF; C0201
C32, C33: 15pF; C0201
C35: 100pF; C0201
C36: 0.8pF; C0201
C37: 0.5pF; C0201
C38: 4.7nH; L0201
C40: DNP; C0201; not fitted
CHG0: RED; LED-0402
D1: SDM20U40-7; SOD-523
GND0: GND; TP-80X40MIL
K1: BUTTON-4P; SW4-SMD-2.8-2.6X1.6X0.53MM
L3: 10uH; L0603
MIC1: MSM261D3526H1CPM; MIC6P-3.5X2.65X0.94MM
NFC1, NFC2: TEST-POINT'4080'; TP-80X40MIL
Q1: LP0404N3T5G; PMOS_1.0_0.6_0.35MM
R1, R2: 5.1k; R0201
R3, R5, R7: 2.2k; R0201
R4, R13, R14, R15, R20: 10k; R0201
R8: DNP; R0201; not fitted
R9: 100k; R0201
R10, R11: 33R; R0201
R12, R18: 2.7k; R0201
R16: 1M_1%; R0201
R17: 510k_1%; R0201
RGB6: RGB; 4P1010
TP1, TP2, TP3, TP5: TEST-POINT'4545'; TP-D45MIL
U1: NRF52840_QF; AQFN50P700X700X85_HS-74N
U2: BQ25101YFPT; DSBGA6-0.4-1.6x0.9x0.5mm; MPN BQ25101YFPT
U3: LSM6DS3TR-C; LGA14-0.5-2.5X3X0.86MM
U4: XIAO-nRF52840; XIAO-Add-On
U6: SGM2040-3.3YUDH4G/TR; X2SON-4
U7: USON2X3_8
U9: LOGO_CC_BY-SA_4.0
USB1: USB2.0-TYPE-C
X1: 32.768KHz; X2-SMD-L1.6X1.0X0.5MM
X2: 32MHz; 4P1612

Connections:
/02 XIAO Header & nRF52840/3V3: C3.2, C6.2, C29.2, C39.1, C41.2, R5.1, R13.1, RGB6.+, U1.A22 (VDD@A22), U1.AD14 (VDD@AD14), U1.AD23 (VDD@AD23), U1.B1 (VDD@B1), U1.W1 (VDD@W1), U1.Y2 (VDDH@Y2), U4.12 (3V3_OUT), U6.1 (OUT), U7.8 (VCC)
/02 XIAO Header & nRF52840/6D_INT1: U1.T2 (P0.11@T2), U3.4 (INT1)
/02 XIAO Header & nRF52840/6D_PWR: C1.2, R14.1, R15.1, U1.P2 (P1.08@P2), U3.5 (VDDIO), U3.8 (VDD), U3.12 (CS)
/02 XIAO Header & nRF52840/DEC4-6: C34.1, C42.1, L3.2, U1.B5 (DEC4@B5), U1.E24 (DEC6@E24)
/02 XIAO Header & nRF52840/INTERNAL_I2C_SCL: R14.2, U1.H2 (P0.27@H2), U3.13 (SCL)
/02 XIAO Header & nRF52840/INTERNAL_I2C_SDA: R15.2, U1.M2 (P0.07@M2), U3.14 (SDA)
/02 XIAO Header & nRF52840/P0.02_AIN0_LOW_A0_D0: U1.A12 (P0.02/AIN0@A12), U4.1 (D0)
/02 XIAO Header & nRF52840/P0.03_AIN1_LOW_A1_D1: U1.B13 (P0.03/AIN1@B13), U4.2 (D1)
/02 XIAO Header & nRF52840/P0.04_AIN2_A4_D4: U1.J1 (P0.04/AIN2@J1), U4.5 (D4)
/02 XIAO Header & nRF52840/P0.05_AIN3_A5_D5: U1.K2 (P0.05/AIN3@K2), U4.6 (D5)
/02 XIAO Header & nRF52840/P0.06_USER_BLUE: R3.2, U1.L1 (P0.06@L1)
/02 XIAO Header & nRF52840/P0.09/NFC1: NFC2.1 (T), U1.L24 (P0.09/NFC1@L24)
/02 XIAO Header & nRF52840/P0.10/NFC2: NFC1.1 (T), U1.J24 (P0.10/NFC2@J24)
/02 XIAO Header & nRF52840/P0.13_HICHG: R12.2, U1.AD8 (P0.13@AD8)
/02 XIAO Header & nRF52840/P0.14_~READ_BAT: R17.2, U1.AC9 (P0.14@AC9)
/02 XIAO Header & nRF52840/P0.16_PDM_DATA: MIC1.3 (DATA), U1.AC11 (P0.16@AC11)
/02 XIAO Header & nRF52840/P0.17_~CHG: CHG0.-, R8.1, U1.AD12 (P0.17@AD12), U2.C1 (~CHG)
/02 XIAO Header & nRF52840/P0.20_QSPI_SIO_0: U1.AD16 (P0.20@AD16), U7.5 (DI)
/02 XIAO Header & nRF52840/P0.21_QSPI_SCK: U1.AC17 (P0.21@AC17), U7.6 (CLK)
/02 XIAO Header & nRF52840/P0.22_QSPI_SIO_2: U1.AD18 (P0.22@AD18), U7.3 (~WP)
/02 XIAO Header & nRF52840/P0.23_QSPI_SIO_3: U1.AC19 (P0.23@AC19), U7.7 (~HOLD)
/02 XIAO Header & nRF52840/P0.24_QSPI_SIO_1: U1.AD20 (P0.24@AD20), U7.2 (DO)
/02 XIAO Header & nRF52840/P0.25_QSPI_CSN: U1.AC21 (P0.25@AC21), U7.1 (~CS)
/02 XIAO Header & nRF52840/P0.26_USER_RED: R7.2, U1.G1 (P0.26@G1)
/02 XIAO Header & nRF52840/P0.28_AIN4_LOW_A2_D2: U1.B11 (P0.28/AIN4@B11), U4.3 (D2)
/02 XIAO Header & nRF52840/P0.29_AIN5_LOW_A3_D3: U1.A10 (P0.29/AIN5@A10), U4.4 (D3)
/02 XIAO Header & nRF52840/P0.30_USER_GREEN: R4.2, U1.B9 (P0.30/AIN6@B9)
/02 XIAO Header & nRF52840/P0.31_AIN7_BAT: R16.2, R17.1, U1.A8 (P0.31/AIN7@A8)
/02 XIAO Header & nRF52840/P1.00_PDM_CLK: MIC1.2 (CLK), U1.AD22 (P1.00@AD22)
/02 XIAO Header & nRF52840/P1.10_MIC_PWR: C8.2, MIC1.1 (VDD), U1.A20 (P1.10@A20)
/02 XIAO Header & nRF52840/P1.11_TX_D6: U1.B19 (P1.11@B19), U4.7 (D6)
/02 XIAO Header & nRF52840/P1.12_RX_D7: U1.B17 (P1.12@B17), U4.8 (D7)
/02 XIAO Header & nRF52840/P1.13_SCK_D8: U1.A16 (P1.13@A16), U4.9 (D8)
/02 XIAO Header & nRF52840/P1.14_MISO_D9: U1.B15 (P1.14@B15), U4.10 (D9)
/02 XIAO Header & nRF52840/P1.15_MOSI_D10: U1.A14 (P1.15@A14), U4.11 (D10)
/02 XIAO Header & nRF52840/RESET: C5.1, K1.1 (A0), K1.3 (A1), R13.2, TP2.T, U1.AC13 (P0.18/RESET@AC13)
/02 XIAO Header & nRF52840/SWDCLK: TP3.T, U1.AA24 (SWDCLK@AA24)
/02 XIAO Header & nRF52840/SWDIO: TP5.T, U1.AC24 (SWDIO@AC24)
/02 XIAO Header & nRF52840/USB_D+: R11.1, USB1.A6 (A6/DP1), USB1.B6 (B6/DP2)
/02 XIAO Header & nRF52840/USB_D-: R10.1, USB1.A7 (A7/DN1), USB1.B7 (B7/DN2)
/02 XIAO Header & nRF52840/VBAT: BAT0.1 (T), C30.1, Q1.1 (D), R16.1, U2.A1 (OUT)
/02 XIAO Header & nRF52840/VBUS: C9.2, C25.2, D1.+, Q1.2 (G), R9.2, U1.AD2 (VBUS@AD2), U2.A2 (IN), U4.14 (VBUS), USB1.A4_B9 (A4/B9/VBUS), USB1.B4_A9 (B4/A9/VBUS)
/02 XIAO Header & nRF52840/VIN: C4.1, D1.-, Q1.3 (S), U6.3 (EN), U6.4 (IN)
/02 XIAO Header & nRF52840//CE: R20.1, U2.B1 (TS)
GND: ANT1.2 (GND), C1.1, C2.1, C3.1, C4.2, C5.2, C6.1, C7.1, C8.1, C9.1, C10.1, C22.1, C24.1, C25.1, C29.1, C30.2, C31.2, C32.2, C33.2, C34.2, C35.2, C36.1, C37.1, C39.2, C40.2, C41.1, C42.2, GND0.1 (T), K1.2 (B0), K1.4 (B1), MIC1.4 (GND@1), MIC1.5 (L/R), MIC1.6 (GND@2), R1.2, R2.1, R8.2, R9.1, R18.2, R20.2, TP1.T, U1.B7 (VSS@B7), U1.F23 (VSS_PA@F23), U1.G74 (VSS_PAD), U2.C2 (VSS), U3.1 (SDO/DA0), U3.2 (SDX), U3.3 (SCX), U3.6 (GND@1), U3.7 (GND@2), U4.13 (GND), U6.2 (GND), U6.T (GND), U7.4 (GND), U7.PAD (T), USB1.A1_B12 (A1/B12/GND), USB1.B1_A12 (B1/A12/GND), USB1.S1, USB1.S2, USB1.S3, USB1.S4, USB1.S5 (S1), USB1.S6 (S2), X2.2 (1), X2.4 (3)
unnamed: ANT1.3, C10.2
unnamed: ANT1.1 (S), C37.2, C38.2
unnamed: CHG0.+, R5.2
unnamed: R3.1, RGB6.B-
unnamed: R4.1, RGB6.G-
unnamed: R7.1, RGB6.R-
unnamed: C36.2, C38.1, U1.H23 (ANT@H23)
unnamed: R11.2, U1.AD6 (D+@AD6)
unnamed: R10.2, U1.AD4 (D-@AD4)
unnamed: L3.1, U1.B3 (DCC@B3)
unnamed: C24.2, U1.C1 (DEC1@C1)
unnamed: C40.1, U1.A18 (DEC2@A18)
unnamed: C35.1, U1.D23 (DEC3@D23)
unnamed: C31.1, U1.N24 (DEC5@N24)
unnamed: C22.2, U1.AC5 (DECUSB@AC5)
unnamed: C2.2, U1.D2 (P0.00/XL1@D2), X1.2
unnamed: C7.2, U1.F2 (P0.01/XL2@F2), X1.1
unnamed: C33.1, U1.B24 (XC1@B24), X2.1 (2)
unnamed: C32.1, U1.A23 (XC2@A23), X2.3 (4)
unnamed: R12.1, R18.1, U2.B2 (ISET)
unnamed: R1.1, USB1.A5 (A5/CC1)
unnamed: R2.2, USB1.B5 (B5/CC2)

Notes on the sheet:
the TS and VSS.
use fixed 10k resistor between
Battery charge
LED
RESET
Sensor
USB-C
FLASH
nRF52840
XIAO
Set P0.14 to output Sink only to enable BAT voltage read;
System 3.3V
Disable Temp sense function,
NTC:
MIC

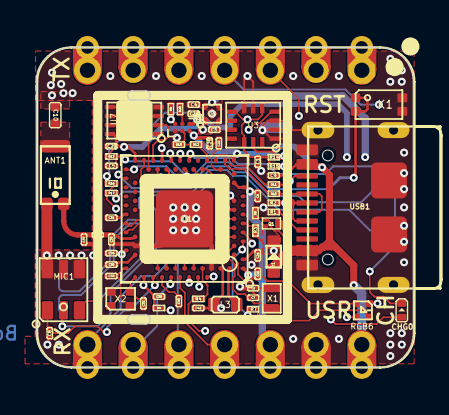
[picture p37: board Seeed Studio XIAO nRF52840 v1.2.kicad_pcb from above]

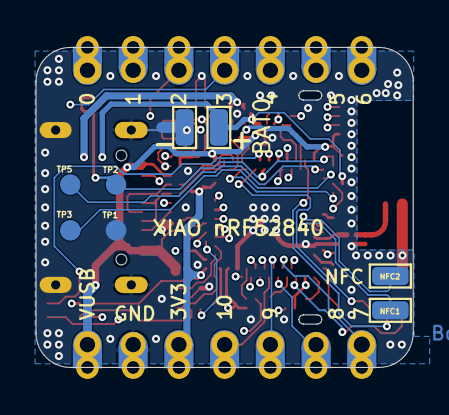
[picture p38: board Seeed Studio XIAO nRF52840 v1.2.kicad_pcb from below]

Board: 4 copper layers, 21.0 x 17.8 mm, 73 parts (8 on the bottom side), 67 nets.

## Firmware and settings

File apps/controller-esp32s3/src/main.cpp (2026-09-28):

// SPDX-License-Identifier: MIT
#include "brightness_ui.hpp"
#include "buddy_ui.hpp"
#include "controller.hpp"
#include "receiver_link.hpp"
#include <Adafruit_NeoPixel.h>
#include <Adafruit_SSD1306.h>
#include <Arduino.h>
#include <Preferences.h>
#include <Wire.h>
#include <driver/gpio.h>
#include <esp_system.h>

namespace {
constexpr int encoderClk = 1, encoderDt = 2, encoderSw = 4;
constexpr int oledSda = 5, oledScl = 6, pixelPin = 44;
constexpr char firmwareVersion[] = "esp32s3-0.5.0";
static_assert(LOA_ENCODER_DIRECTION == 1 || LOA_ENCODER_DIRECTION == -1, "Direction must be +/-1");

Adafruit_SSD1306 display(128, 64, &Wire, -1);
Adafruit_NeoPixel pixel(1, pixelPin, NEO_GRB + NEO_KHZ800);
Preferences preferences;
loa::State state;
loa::Button button;
loa::Encoder encoder;
loa::LocalBrightness localBrightness;
loa::BrightnessEditor brightnessEditor;
loa_brightness signBrightness = loa_brightness_defaults();
const char *brightnessError = "Press to read sign";
portMUX_TYPE encoderLock = portMUX_INITIALIZER_UNLOCKED;
volatile int encoderSteps = 0;
bool oledReady = false, storageReady = false, radioReady = false, bonded = false, busy = false;
uint8_t oledAddress = 0;
uint32_t lastActivity = 0, lastFrame = 0, lastCheck = 0, retryAt = 0;
uint32_t effectStarted = 0;
bool quietOperation = false, sendAfterCheck = false;
loa_status queuedSelection = LOA_STATUS_OFF;
unsigned retries = 0;
int turns = 0, clicks = 0, holds = 0;
enum class Screen { Home, Menu, Test, Forget, PairHelp, Brightness, LightEdit };
Screen screen = Screen::Home;
int menuItem = 0, testColor = 0;
int brightnessItem = 0;
bool confirmForget = false;
const char *notice = "Hi, stream buddy!";
uint32_t noticeAt = 0;
const char *const menuItems[] = {"Back to my sign", "Check my sign", "Connect a sign",
                                 "Brightness",      "Light test",    "Forget this sign"};
const char *const brightnessItems[] = {"Back to settings", "Sign frame", "Sign indicator",
                                       "Screen awake",     "Screen dim", "Controller light"};
const char *const testNames[] = {"OFF", "RED", "GREEN", "BLUE", "WHITE", "YELLOW"};
constexpr loa_rgb testColors[] = {{0, 0, 0},   {255, 0, 0},     {0, 255, 0},
                                  {0, 0, 255}, {255, 255, 255}, {255, 255, 0}};

void IRAM_ATTR onEncoder() {
    const uint8_t pins = (gpio_get_level(static_cast<gpio_num_t>(encoderClk)) << 1) |
                         gpio_get_level(static_cast<gpio_num_t>(encoderDt));
    portENTER_CRITICAL_ISR(&encoderLock);
    encoderSteps += encoder.update(pins) * LOA_ENCODER_DIRECTION;
    portEXIT_CRITICAL_ISR(&encoderLock);
}

void say(const char *text) {
    notice = text;
    noticeAt = millis();
    Serial.printf("NOTICE %s\n", text);
}

void saveState() {
    uint8_t payload[LOA_PROTOCOL_PAYLOAD_LEN];
    if (loa_protocol_encode(payload, &state.confirmed) == 0 &&
        (!storageReady ||
         preferences.putBytes("state", payload, sizeof(payload)) != sizeof(payload)))
        say("State save failed");
}

bool start(LinkOperation operation, uint8_t pixelIndex = 255, loa_rgb pixelColor = {0, 0, 0},
           bool quietly = false) {
    if (!radioReady || busy) {
        say(busy ? "One sec, please!" : "Radio needs a restart");
        return false;
    }
    if (operation == LinkOperation::Pair && bonded) {
        say("Already connected!");
        return false;
    }
    if ((operation == LinkOperation::Send || operation == LinkOperation::Sync ||
         operation == LinkOperation::Pixel || operation == LinkOperation::ReadBrightness ||
         operation == LinkOperation::SetBrightness) &&
        !bonded) {
        say("Connect a sign first");
        return false;
    }
    uint32_t transaction = esp_random();
    if (transaction == 0)
        transaction = 1;
    LinkRequest request{operation, {transaction, state.selected}, pixelIndex, pixelColor, {}};
    if (operation == LinkOperation::SetBrightness) {
        request.brightness = signBrightness;
        // Never reuse the transaction of the snapshot being edited.
        if (transaction == signBrightness.transaction_id)
            transaction = transaction == UINT32_MAX ? 1 : transaction + 1;
        request.brightness.transaction_id = transaction;
        if (brightnessEditor.light == LOA_LIGHT_FRAME)
            request.brightness.frame = brightnessEditor.value;
        else
            request.brightness.indicator = brightnessEditor.value;
    }
    if (!linkStart(request))
        return false;
    busy = true;
    quietOperation = quietly;
    if (operation != LinkOperation::ReadBrightness && operation != LinkOperation::SetBrightness)
        retryAt = 0;
    if (!quietly)
        say(operation == LinkOperation::SetBrightness    ? "Saving brightness..."
            : operation == LinkOperation::ReadBrightness ? "Reading brightness"
            : operation == LinkOperation::Pixel          ? "Testing a light"
            : operation == LinkOperation::Send           ? "Telling your sign..."
            : operation == LinkOperation::Pair           ? "Looking for a friend"
                                                         : "Checking your sign");
    Serial.printf("REQUEST op=%u tx=%08lx status=%s\n", unsigned(operation),
                  static_cast<unsigned long>(transaction), loa_status_name(state.selected));
    return true;
}

void report() {
    Serial.printf("STATUS firmware=%s uptime=%lu oled=%s address=0x%02x size=128x64 "
                  "bonded=%u busy=%u known=%u verified=%u confirmed=%s selected=%s "
                  "screen=%u color=%s turns=%d clicks=%d holds=%d heap=%u\n",
                  firmwareVersion, static_cast<unsigned long>(millis()),
                  oledReady ? "ok" : "missing", oledAddress, bonded, busy, state.known,
                  state.verified, loa_status_name(state.confirmed.status),
                  loa_status_name(state.selected), unsigned(screen), testNames[testColor], turns,
                  clicks, holds, ESP.getFreeHeap());
    Serial.printf("LIGHTS saved_awake=%u saved_dim=%u saved_controller=%u\n", localBrightness.awake,
                  localBrightness.dim, localBrightness.led);
}

void enterTest() {
    if (busy) {
        say("Wait for receiver");
        return;
    }
    screen = Screen::Test;
    testColor = 1;
    lastActivity = millis();
    Serial.println("TEST RED; rotate or click for colors; hold to exit; no receiver command sent");
}

void openBrightness() {
    if (busy) {
        say("One sec, please!");
        return;
    }
    const auto light = static_cast<loa_light>(brightnessItem - 1);
    if (light <= LOA_LIGHT_SIGN_LED && (!bonded || !radioReady)) {
        say(!bonded ? "Connect a sign first" : "Radio needs a restart");
        return;
    }
    brightnessEditor.open(light, localBrightness.get(light), light > LOA_LIGHT_SIGN_LED);
    screen = Screen::LightEdit;
    brightnessError = "Press to read sign";
    if (brightnessEditor.remote())
        start(LinkOperation::ReadBrightness);
}

void saveBrightness() {
    if (brightnessEditor.remote()) {
        start(LinkOperation::SetBrightness);
        return;
    }
    auto next = localBrightness;
    next.set(brightnessEditor.light, brightnessEditor.value);
    uint8_t payload[LOA_LOCAL_BRIGHTNESS_RECORD_LEN], previous[LOA_LOCAL_BRIGHTNESS_RECORD_LEN];
    next.encode(payload);
    localBrightness.encode(previous);
    if (memcmp(payload, previous, sizeof(payload)) != 0 &&
        (!storageReady ||
         preferences.putBytes("brightness", payload, sizeof(payload)) != sizeof(payload))) {
        // Restore the saved output and keep an explicit failure visible.
        screen = Screen::Brightness;
        say("Light save failed");
        return;
    }
    localBrightness = next;
    screen = Screen::Brightness;
    say("Brightness saved");
}

void click() {
    switch (screen) {
    case Screen::Brightness:
        if (brightnessItem == 0)
            screen = Screen::Menu;
        else
            openBrightness();
        break;
    case Screen::LightEdit:
        if (busy)
            break;
        if (!brightnessEditor.ready) {
            start(LinkOperation::ReadBrightness);
        } else if (brightnessEditor.editing) {
            brightnessEditor.editing = false;
            brightnessEditor.row = 1;
        } else if (brightnessEditor.row == 0)
            brightnessEditor.editing = true;
        else if (brightnessEditor.row == 1)
            saveBrightness();
        else if (brightnessEditor.row == 2)
            brightnessEditor.reset();
        else
            screen = Screen::Brightness;
        break;
    case Screen::PairHelp:
        retries = 0;
        if (start(LinkOperation::Pair))
            screen = Screen::Home;
        break;
    case Screen::Test:
        testColor = (testColor + 1) % 6;
        Serial.printf("TEST %s\n", testNames[testColor]);
        break;
    case Screen::Forget:
        if (confirmForget && start(LinkOperation::Forget))
            screen = Screen::Home;
        else if (!confirmForget)
            screen = Screen::Menu;
        break;
    case Screen::Menu:
        switch (menuItem) {
        case 0:
            screen = Screen::Home;
            break;
        case 1:
            retries = 0;
            if (start(LinkOperation::Sync))
                screen = Screen::Home;
            break;
        case 2:
            retries = 0;
            if (start(LinkOperation::Pair))
                screen = Screen::Home;
            break;
        case 3:
            screen = Screen::Brightness;
            brightnessItem = 0;
            break;
        case 4:
            enterTest();
            break;
        case 5:
            if (!busy) {
                screen = Screen::Forget;
                confirmForget = false;
            }
            break;
        }
        break;
    case Screen::Home:
        if (!bonded) {
            retries = 0;
            start(LinkOperation::Pair);
        } else if (busy && quietOperation) {
            sendAfterCheck = true;
            queuedSelection = state.selected;
            say("You're up next!");
        } else if (!busy && state.verified && state.selected == state.confirmed.status) {
            say("Already set!");
        } else {
            retries = 0;
            start(LinkOperation::Send);
        }
        break;
    }
}

void input() {
    const uint32_t now = millis();
    portENTER_CRITICAL(&encoderLock);
    int steps = encoderSteps;
    encoderSteps = 0;
    portEXIT_CRITICAL(&encoderLock);
    const auto event = button.update(digitalRead(encoderSw) == LOW, now);
    if (steps == 0 && event == loa::ButtonEvent::None)
        return;
    const bool waking = now - lastActivity >= 120000;
    lastActivity = now;
    turns += steps;
    if (event == loa::ButtonEvent::Click)
        ++clicks;
    if (event == loa::ButtonEvent::Hold)
        ++holds;
    Serial.printf("INPUT steps=%d event=%s turns=%d clicks=%d holds=%d\n", steps,
                  event == loa::ButtonEvent::Click  ? "click"
                  : event == loa::ButtonEvent::Hold ? "hold"
                                                    : "turn",
                  turns, clicks, holds);
    if (waking)
        return; // First gesture wakes the display without sending anything.
    while (steps != 0) {
        const int direction = steps > 0 ? 1 : -1;
        steps -= direction;
        switch (screen) {
        case Screen::Home:
            if ((!busy || quietOperation) && !sendAfterCheck)
                state.selected = loa::rotate(state.selected, direction);
            break;
        case Screen::Menu:
            menuItem = (menuItem + direction + 6) % 6;
            break;
        case Screen::Brightness:
            brightnessItem = (brightnessItem + direction + 6) % 6;
            break;
        case Screen::LightEdit:
            if (!busy)
                brightnessEditor.turn(direction);
            break;
        case Screen::Test:
            testColor = (testColor + direction + 6) % 6;
            break;
        case Screen::Forget:
            confirmForget = !confirmForget;
            break;
        case Screen::PairHelp:
            break;
        }
    }
    if (event == loa::ButtonEvent::Hold) {
        screen = screen == Screen::Home ? Screen::Menu : Screen::Home;
        menuItem = 0;
        confirmForget = false;
        say("Hold for menu");
    } else if (event == loa::ButtonEvent::Click)
        click();
    report();
}

void serialInput() {
    static char command[48];
    static size_t used = 0;
    static bool overflow = false;
    while (Serial.available()) {
        const char c = Serial.read();
        if (c == '\r')
            continue;
        if (c != '\n') {
            if (used < sizeof(command) - 1)
                command[used++] = c;
            else
                overflow = true;
            continue;
        }
        command[used] = 0;
        used = 0;
        if (overflow) {
            overflow = false;
            Serial.println("ERROR command too long");
            continue;
        }
        if (!strcmp(command, "status")) {
            report();
            continue;
        }
        if (!strcmp(command, "help")) {
            Serial.println("status | test [off|red|green|blue|white|yellow] | next | exit | menu | "
                           "sync | pair | send off|warn|on-air|okay|request|special | pixel 1..4 "
                           "color | pixel end");
            continue;
        }
        lastActivity = millis();
        if (!strcmp(command, "test") || !strncmp(command, "test ", 5)) {
            enterTest();
            if (screen == Screen::Test && strlen(command) > 5) {
                bool found = false;
                for (int i = 0; i < 6; ++i)
                    if (!strcasecmp(command + 5, testNames[i])) {
                        testColor = i;
                        found = true;
                    }
                if (!found)
                    Serial.println("ERROR unknown test color");
                Serial.printf("TEST %s\n", testNames[testColor]);
            }
        } else if (!strcmp(command, "next") && screen == Screen::Test)
            click();
        else if (!strcmp(command, "exit")) {
            screen = Screen::Home;
            confirmForget = false;
        } else if (!strcmp(command, "menu")) {
            screen = Screen::Menu;
            menuItem = 0;
        } else if (!strcmp(command, "sync")) {
            retries = 0;
            start(LinkOperation::Sync);
        } else if (!strcmp(command, "pair")) {
            retries = 0;
            screen = Screen::Home;
            start(LinkOperation::Pair);
        } else if (!strcmp(command, "pixel end")) {
            start(LinkOperation::Pixel);
        } else if (!strncmp(command, "pixel ", 6)) {
            unsigned index;
            char colorName[12], extra;
            bool found = false;
            if (sscanf(command + 6, "%u %11s %c", &index, colorName, &extra) == 2 && index >= 1 &&
                index <= 4) {
                for (int i = 0; i < 6; ++i) {
                    if (!strcasecmp(colorName, testNames[i])) {
                        found = true;
                        if (start(LinkOperation::Pixel, index - 1, testColors[i]))
                            Serial.printf("PIXEL index=%u color=%s; other pixels off\n", index,
                                          testNames[i]);
                        break;
                    }
                }
            }
            if (!found)
                Serial.println("ERROR pixel expects 1..4 and off|red|green|blue|white|yellow");
        } else if (!strncmp(command, "send ", 5)) {
            bool found = false;
            for (int i = LOA_STATUS_OFF; i < LOA_STATUS_COUNT; ++i) {
                const auto selected = static_cast<loa_status>(i);
                if (strcmp(command + 5, loa_status_name(selected)))
                    continue;
                found = true;
                const auto previous = state.selected;
                state.selected = selected;
                if (start(LinkOperation::Send)) {
                    retries = 0;
                    screen = Screen::Home;
                } else {
                    state.selected = previous;
                }
                break;
            }
            if (!found)
                Serial.println("ERROR send expects off|warn|on-air|okay|request|special");
        } else
            Serial.println("ERROR unknown command; type help");
        report();
    }
}
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
void loop() {
    input();
    serialInput();
    receive();
    const uint32_t now = millis();
    if (!busy && bonded && screen == Screen::Home) {
        if (retryAt && static_cast<int32_t>(now - retryAt) >= 0)
            start(LinkOperation::Sync, 255, {0, 0, 0}, true);
        else if (!retryAt && retries == 0 && now - lastCheck >= 60000)
            start(LinkOperation::Sync, 255, {0, 0, 0}, true);
    }
    render();
    delay(2);
}

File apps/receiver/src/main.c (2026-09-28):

/* SPDX-License-Identifier: MIT */
#include <zephyr/bluetooth/bluetooth.h>
#include <zephyr/bluetooth/conn.h>
#include <zephyr/kernel.h>
#include <zephyr/logging/log.h>
#include <zephyr/settings/settings.h>

#include <little_on_air/reset_input.h>
#include <little_on_air/store.h>

#include "ble_server.h"
#include "brightness_settings.h"
#include "device_indicator.h"
#include "mood_indicator.h"
#include "pair_reset.h"

#if defined(CONFIG_UART_CONSOLE)
#include <errno.h>
#include <string.h>
#include <hal/nrf_power.h>
#include <zephyr/drivers/uart.h>
#include <zephyr/sys/reboot.h>

static void bench_usb_poll(void)
{
	static char line[32];
	static size_t used;
	static bool overflow;
	const struct device *uart = DEVICE_DT_GET(DT_CHOSEN(zephyr_console));
	uint8_t c;
	while (uart_poll_in(uart, &c) == 0) {
		if (c == '\r') {
			continue;
		}
		if (c != '\n') {
			if (used < sizeof(line) - 1) {
				line[used++] = c;
			} else {
				overflow = true;
			}
			continue;
		}
		line[used] = 0;
		used = 0;
		if (overflow) {
			overflow = false;
			printk("BENCH ERROR command too long\n");
			continue;
		}
		if (strcmp(line, "pair-reset") == 0) {
			int err = loa_pair_reset_request();
			printk("BENCH pair-reset saved=%d\n", err);
		} else if (strcmp(line, "reboot") == 0 || strcmp(line, "bootloader") == 0) {
			printk("BENCH %s\n", line);
			k_sleep(K_MSEC(250));
			if (strcmp(line, "bootloader") == 0) {
				nrf_power_gpregret_set(NRF_POWER, 0U, 0x57U);
			}
			sys_reboot(SYS_REBOOT_COLD);
		} else if (strcmp(line, "status") == 0) {
			struct loa_message current = loa_store_get_state();
			struct loa_brightness brightness = loa_brightness_settings_get();
			printk("BENCH bonded=%u saved=%u tx=%08x status=%u\n",
			       loa_ble_server_has_bond(), loa_store_has_state(),
			       current.transaction_id, current.status);
			printk("BENCH brightness_tx=%08x frame=%u indicator=%u\n",
			       brightness.transaction_id, brightness.frame, brightness.indicator);
		} else {
			printk("BENCH commands: status | pair-reset | reboot | bootloader\n");
		}
	}
}
#endif

LOG_MODULE_REGISTER(loa_receiver_main);

int main(void)
{
	struct loa_boot_input input;
	struct loa_message initial_state = {
		.transaction_id = 0U,
		.status = LOA_STATUS_OFF,
	};
	int err;

	err = loa_mood_indicator_init();
	if (err != 0) {
		return err;
	}
	loa_device_indicator_init();
	input = loa_reset_input_capture();
	LOG_INF("boot button_press=%u factory_reset=%u", input.button_press, input.factory_reset);

	err = bt_enable(NULL);
	if (err != 0) {
		LOG_ERR("Bluetooth enable failed err=%d", err);
		return err;
	}
	LOG_INF("Bluetooth enabled");
	err = settings_load();
	if (err != 0) {
		LOG_ERR("settings load failed err=%d", err);
		return err;
	}
	LOG_INF("settings loaded");
	err = loa_brightness_settings_init();
	if (err != 0) {
		LOG_ERR("brightness restore failed err=%d", err);
		return err;
	}
	err = loa_reset_input_resolve(&input);
	if (err != 0) {
		LOG_ERR("reset gesture storage failed err=%d", err);
		return err;
	}
	input.factory_reset = input.factory_reset || loa_pair_reset_pending();

	if (input.factory_reset) {
		err = loa_pair_reset_mark();
		if (err != 0) {
			return err;
		}
		err = bt_unpair(BT_ID_DEFAULT, BT_ADDR_LE_ANY);
		LOG_INF("factory reset unpair result=%d", err);
		if (err != 0) {
			return err;
		}
		err = loa_store_clear_state();
		LOG_INF("factory reset state clear result=%d", err);
		if (err != 0) {
			return err;
		}
		err = loa_pair_reset_complete();
		if (err != 0) {
			return err;
		}
	} else if (loa_store_has_state()) {
		initial_state = loa_store_get_state();
	}
	LOG_INF("initial transaction=0x%08x status=%u", initial_state.transaction_id,
		initial_state.status);

	err = loa_ble_server_init(&initial_state);
	if (err != 0) {
		LOG_ERR("BLE server init failed err=%d", err);
		return err;
	}
	err = loa_ble_server_start(input.button_press || input.factory_reset);
	if (err != 0) {
		LOG_ERR("BLE server start failed err=%d", err);
		return err;
	}
	LOG_INF("receiver ready");

#if defined(CONFIG_UART_CONSOLE)
	/* CDC ACM needs its OUT endpoint armed even with polling reads. */
	uart_irq_rx_enable(DEVICE_DT_GET(DT_CHOSEN(zephyr_console)));
#endif
	while (true) {
#if defined(CONFIG_UART_CONSOLE)
		bench_usb_poll();
		k_sleep(K_MSEC(10));
#else
		k_sleep(K_FOREVER);
#endif
	}
	return 0;
}

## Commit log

2026-08-11 Fix BLE Secure Connections Just Works pairing (#2)
    Use LE Secure Connections pairing-only mode so the no-I/O XIAO boards can complete encrypted Just Works bonding. Add build guards against authenticated-only SC mode and bump the firmware version to 0.1.1.
2026-08-11 Fix receiver advertising restart (#3)
    Defer connectable advertising restart until Zephyr releases the disconnected connection object. Add retry handling and opt-in dual-board USB diagnostics.
    [main.c]
2026-09-15 Add enclosure v2.13 release and design history
    [01 Descriptions.kicad_sch, 01-body-and-front-frame.3mf, 01-body-and-front-frame.stl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]
2026-09-26 Consolidate current firmware, enclosure, and controller iterations
    Add the ESP32-S3 desk controller, six mood states, persistent pairing recovery, independent power indication, and padded pixel timing with host regressions and bench records.
    Preserve receiver enclosure releases v2.13 through v2.16 and Igor controller prototypes v1 through v4, including CAD, manufacturing files, guides, and verified archives.
    [00.stl, 01-front-optical-bezel.stl, 01-igor-flat-base-shell.step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]
2026-09-26 Archive historical hardware and consolidate build output
    [01 Descriptions.kicad_sch, 01-body-and-front-frame.3mf, 01-body-and-front-frame.stl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]
2026-09-26 Restore v2.15 as the current receiver enclosure
    [00.stl, 01-front-optical-bezel.stl, 01.stl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]
2026-09-26 Retire legacy firmware and build only the current device pair
2026-09-28 Add persistent brightness controls for both devices
